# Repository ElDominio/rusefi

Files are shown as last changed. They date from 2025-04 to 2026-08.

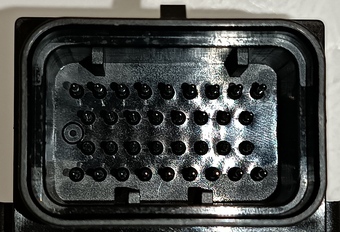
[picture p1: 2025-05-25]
firmware/config/boards/hellen/alphax-4K-GDI/connectors/34pins-4k-A.jpg

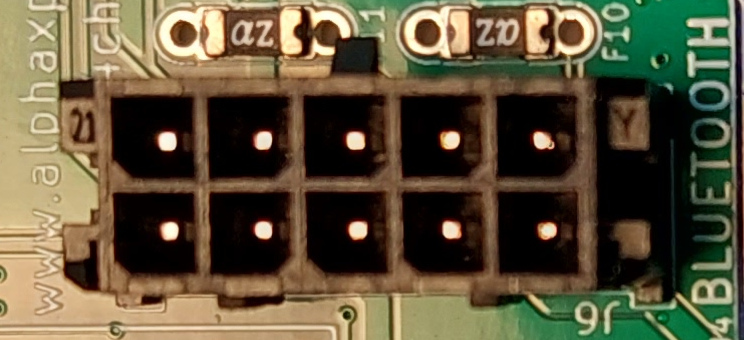
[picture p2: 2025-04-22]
firmware/config/boards/hellen/alphax-silver/connectors/alphax-silver-aux.jpg

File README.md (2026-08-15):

<div align="center">

rusEFI

<b>GPL open-source ECU</b>



</div>

# rusEFI



[shop.rusEFI.com](https://www.shop.rusefi.com/)

# Download

Current binaries are always available on our [build server](http://rusefi.com/build_server/)

# Release Notes

See [the changelog](firmware/CHANGELOG.md)

# What do we have here?
 * [Firmware](/firmware) Source code for open source engine control unit for stm32 chips including [implementation overview](https://github.com/rusefi/rusefi/blob/master/firmware/readme.md)
 * [Hardware](/hardware) KiCAD files for our older PCBs
 * [rusEFI console](/java_console) rusEFI own native tuning software
 * [Simulator](/simulator) win32 or posix version of firmware allows to explore without any hardware
 * [Unit Tests](/unit_tests) Unit tests of firmware pieces [coverage report](https://rusefi.com/docs/unit_tests_coverage/)
 * [Misc tools](/java_tools) Misc development utilities
 * [Software Development process](misc/SoftwareDevelopmentProcess.md)

# External Links

 * [Forum](http://rusefi.com/forum)
 * [Documentation](https://wiki.rusefi.com)
 * [Doxygen documentation](http://rusefi.com/docs/html)
 * [General source code Q&A](http://rusefi.com/forum/viewtopic.php?f=5&t=10)
 * [Facebook](https://www.facebook.com/rusEfiECU)
 * [YouTube](https://www.youtube.com/user/rusefi)
 * [Patreon](https://www.patreon.com/rusefi)

# Cloning the repository
`git clone https://github.com/rusefi/rusefi.git`
Important note - we now use submodules:

`git submodule update --init`

# Building the Code

See [gcc_version_check.c](https://github.com/rusefi/rusefi/blob/master/firmware/gcc_version_check.c) for recommended version of GCC.

Check out https://rusefi.com/forum/viewtopic.php?f=5&t=9

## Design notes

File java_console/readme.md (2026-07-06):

# rusEFI console

rusEFI frontend applications is historically known as rusEFI console.

* firmware update
* wizard for one-time initial setup
* on-going monitoring and calibration

Here we have source code for rusEFI console: while [TunerStudio](http://www.tunerstudio.com/index.php/products/tuner-studio) is the primary calibration frontend application we need secondary app for firmware update and some advanced troubleshooting. One day we shall combine but not yet :(

See also http://rusefi.com/build_server/ for pre-compiled full bundle

🔴 not main folder for java code - it's [../java_tools](../java_tools) where primary build.gradle is located 🔴

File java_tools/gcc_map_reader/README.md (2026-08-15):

# Firmware Stack Usage Report

`StackUsageReport` combines GCC's post-LTO callgraph data with stack metadata
linked into the firmware and bootloader ELF files. The report is informational:
it highlights changes for review but does not fail a build because a stack is
too small.

## Files

| Path | Reason |
|---|---|
| `src/main/resources/stack_usage/*.md` | Hand-maintained profile inputs: display names, reviewed measurements, proxy snapshots, and scenarios |
| `firmware/build/firmware_stack_usage_<profile>.md` | Generated by `com.rusefi.tools.stack.StackUsageReport` during the stack-usage workflow |
| `docs/firmware_stack_usage.md` | Generated and committed by `.github/workflows/firmware-stack-usage.yaml` from the three profile reports |

Generated reports carry a header naming their generator. Do not edit generated
reports directly; update the firmware metadata, profile input, or report tool.

## Inputs

uses compiler-checked metadata macros from
`firmware/controllers/core/common_headers.h`:

- `RUSEFI_STACK_ROOT` for a `ThreadController` or `PeriodicController` member.
- `RUSEFI_STACK_ROOT_EXPLICIT` for a root with an explicit function and budget.
- `RUSEFI_STACK_PROCESS_ROOT` for the linker-sized main process stack.
- `RUSEFI_STACK_FOREIGN_ROOT` only for inaccessible upstream static functions.

The STM32 linker keeps this metadata in non-allocated ELF sections, so it adds
nothing to the flashed image. The Java tool reads:

- The full ELF symbol table for typed roots, including local symbols.
- Foreign-root string sections for inaccessible upstream functions.
- Linker map process and exception stack sizes.
- GCC `.ci` post-LTO callgraphs produced with `-fcallgraph-info=su`.
- The matching hand-maintained profile table under
  `src/main/resources/stack_usage/`.

Profile membership is exact. Adding or removing a linked root without updating
the corresponding profile table makes report generation fail with the missing
and extra entries.

## Add A Thread

1. Mark the thread entry in the source that owns its working area:

```cpp
class ExampleThread final : public ThreadController<512> {
    // ...
};

RUSEFI_STACK_ROOT(ExampleThread, ThreadTask);
```

For a `PeriodicController`, use `PeriodicTask`. For a function passed directly
to `chThdCreateStatic`, use the working-area size explicitly:

```cpp
static THD_WORKING_AREA(exampleThreadStack, 512);

static THD_FUNCTION(exampleThread, arg) {
    // ...
}

RUSEFI_STACK_ROOT_EXPLICIT(exampleThread, 512);
```

Place the macro after the entry function is declared. Use
`RUSEFI_STACK_FOREIGN_ROOT` only when the entry is an inaccessible static
function in upstream code. The macros compile to no code outside production
stack-report builds and their ELF metadata is not flashed.

2. Build and run the report for every affected reference-board profile. The
report fails and prints the exact `missing` or `extra` entry when a linked root
is not in its profile.

3. Add the exact demangled entry name to the matching
`src/main/resources/stack_usage/<profile>.md` table. Start with `-` for
Retained, Proxy, and Scenario if the thread has not been measured:

```text
| firmware | ExampleThread::ThreadTask | example worker | - | - | - |
```

Do not add inactive roots to a profile. The profile describes the final ELF
for that board, not all source files.

## Fix A Stack Overflow

1. Reproduce the highest realistic workload on hardware and record the maximum
stack used by the thread. `Remaining stack` console diagnostics and the stack
guard/check are useful runtime evidence; include ChibiOS overhead in the
working-area budget.

2. Increase the owning `ThreadController<N>`, `PeriodicController<N>`, or
`THD_WORKING_AREA` size above that measurement with a practical margin. Do not
use the direct-call proxy as the measurement: indirect calls, unknown frames,
recursion, interrupts, and context switches can make it too small.

3. Update the profile row's Retained bytes, Proxy snapshot, and Scenario. The
scenario must say what was exercised, for example `SD exFAT log creation`.
The next report compares Current proxy to that snapshot and flags growth for
review.

## Run Locally

Build one profile with stack and callgraph data. For example, H743:

```bash
cd firmware
EXTRA_3_PARAMS="-fstack-usage -fcallgraph-info=su" \
  bash bin/compile.sh config/boards/nucleo_h743/meta-info.env \
  elf bootloader --output-sync=recurse
cd ..
```

Build, test, and run the Java report tool:

```bash
./gradlew :gcc_map_reader:test :gcc_map_reader:shadowJar
java -cp java_tools/gcc_map_reader/build/libs/gcc_map_reader-all.jar \
  com.rusefi.tools.stack.StackUsageReport \
  --profile stm32h743_nucleo \
  --firmware-dir firmware/build \
  --bootloader-dir firmware/bootloader/blbuild \
  --output firmware/build/firmware_stack_usage_stm32h743_nucleo.md
```

`arm-none-eabi-readelf` and `arm-none-eabi-c++filt` must be available on
`PATH`; command overrides are available through `--readelf` and `--cxxfilt`.

## Reading The Report

- **Nominal** is the allocated stack budget from C++ or the linker.
- **Reviewed** is a manually traced realistic scenario, not a root-wide maximum.
- **Proxy snapshot** is the post-LTO direct-call estimate when that scenario was
  reviewed.
- **Current proxy** is the estimate from the current build.
- `REVIEW PROXY +N` means the estimate grew and the scenario should be reviewed.
- `NOT REVIEWED` means no retained scenario exists for that root.

Indirect calls, unknown frames, recursion, interrupts, and context switching can
make the proxy incomplete. The report lists these limitations rather than
pretending the proxy is a proven maximum.

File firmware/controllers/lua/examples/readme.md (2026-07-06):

# rusEFI Lua examples

General reference: https://wiki.rusefi.com/Lua-Scripting

This folder is a grab-bag of community Lua snippets that talk to the rusEFI Lua API
(CAN RX/TX, sensors, outputs, PWM, timers, PID, TunerStudio buttons, etc.). When
asked to write a new Lua script, **scan this folder first** for an analogous
example before starting from scratch. Files use `.lua` or `.txt` — both are plain
Lua; the `.txt` extension is historical.

For iterating on a live or simulated ECU from an LLM, see
`java_console/mcp_ecu/README.md` (the `:mcp_ecu` MCP server: `set_lua`,
`lua_reset`, `wait_for_message`, …).

---

## Gotchas (read before writing a script)

- **Lua-fed sensors time out — refresh them every `onTick`, not on a slow
  gated cadence.** A `Sensor.new(...)` value goes invalid `setTimeout(ms)`
  after the last `:set()` (see `StoredValueSensor::get()` in
  `controllers/sensors/core/stored_value_sensor.h`). If you only call `:set()`
  from a block gated to, say, every 2s while the timeout is 3s, you have ~1s
  of slack — any tick jitter pushes the gap past the timeout and the consumer
  briefly reads 0/invalid, then your next update restores it (gauges that
  "drop to 0 and jump back"). Push `:set()` unconditionally each tick and gate
  only the *value computation* (e.g. a sweep counter). Or, at minimum, set the
  timeout well above the worst-case refresh interval.
- **Failed `txCan` stalls the Lua thread.** On a bench with no second node to
  ACK (or a mis-wired/unterminated bus), transmits fail and `txCan` blocks
  until timeout; the `canWriteNotOk` output channel climbs. Many `txCan` calls
  per tick at a high `setTickRate(...)` can then delay `onTick` by seconds —
  which is exactly what trips the sensor-timeout gotcha above. Symptom is
  environmental (gone on a live, terminated bus) but design scripts to tolerate
  it.

Related (full engine configs, not just snippets):
- VAG CAN producer — `firmware/config/engines/vw_b6.lua`
- GM CAN producer — `firmware/config/engines/gm_ls_4.cpp`

---

## Categories

### Getting started / building blocks
- `pid.lua` — minimal `Pid.new(...)` usage; a good "hello PID" template.
- `ts-button-example.lua` — wire a TunerStudio button (`fireEvent`) to a Lua
  handler. Reference for any UI-triggered action.
- `etb-test-script.lua` — one-liner to drive the electronic throttle manually.
- `dac.txt` — write an analog voltage via the on-board DAC.
- `analog-gear-input.txt` — decode a gear position from a single analog input
  (voltage windows → gear number).
- `linear-oil-sensor.lua` — convert a linear oil-pressure sensor voltage to a
  rusEFI sensor reading.

### Utilities / helpers (good to copy-paste into other scripts)
- `utils-print-array.lua` — pretty-print a Lua array (debug helper).
- `utils-can-dbc.lua` — bit-field pack/unpack helpers in the spirit of DBC
  signal definitions; the cleanest reference for building CAN payloads.
- `utils-dash-sweep.lua` / `dash-sweep.lua` — sweep gauge needles on power-up
  (a "self-test" animation for digital dashes).

### Launch control / antilag / quickshift
- `launch_control.lua` — full-featured launch control with CAN status frames,
  ignition cut and configurable thresholds. The most complete example in this
  folder.
- `custom-launch-control.txt` — simpler launch-control sketch.
- `CruiseCheck.lua` — cruise-control safety / engagement checks.
- `ALS (simple antilag strategy).txt` and the companion
  `ALS (simple antilag strategy)LUA_MAPS.txt` — minimal antilag with Lua-side
  fuel/ignition maps.
- `quickshift.txt` — flat-shift / quickshifter ignition-cut on a digital input.

### Drive-by-wire / actuators
- `DBW-controller.txt` — closed-loop electronic throttle controller written in
  Lua (useful when the built-in ETB is not enough).
- `can-client-dc-pid.txt` — PID-controlled DC motor over CAN.
- `Volvo-electric-power-steering-pump.txt` — drive a Volvo EPS pump via PWM /
  CAN.

### CAN: man-in-the-middle and gateways
"Cut a CAN bus and put rusEFI in the middle" patterns — rusEFI receives frames
on one bus and re-transmits modified copies, typically to spoof RPM / TPS / etc.
to a downstream module.
- `man-in-the-middle.txt` — generic MITM template, start here.
- `man-in-the-middle-nissan-tcu.txt`, `nissan-xterra-tcu.txt`,
  `nissan-tcu.lua` — feed a Nissan TCU with fabricated ECU frames so the
  factory transmission keeps working behind rusEFI.
- `TCU-4-speed.txt` — a fuller standalone 4-speed TCU written in Lua.
- `vag-headlight.txt` — VAG headlight / lighting CAN MITM.

### CAN: VAG / VW transport protocol (TP 2.0)
- `vw-tp.txt` — VW/Audi TP 2.0 transport layer in Lua (channel setup,
  segmented messages).
- `vw-tp-tcu.txt` — TP 2.0 talking to a VAG TCU.
- `vw-sensors-from-ptbus-pq46.txt` — read sensor values off a PQ46 powertrain
  bus.

### CAN: dashboards / instrument clusters
Drive a factory cluster from rusEFI by emitting the frames it expects.
- `suzuki_can_dash.lua` — Suzuki cluster.
- `dash_output_abit_m11.txt`, `dash_output_abit_m11.16txt` — Abit M11
  aftermarket dash.
- `uaDASH-dev.lua` — uaDASH (rusEFI / community digital dash) output frames.
- `bmw-idrive.txt` — drive BMW iDrive / cluster signals.

### CAN: body / comfort modules (BCM)
- `honda-bcm.txt` — Honda body control module signalling.
- `nissan-350z-bcm.txt`, `350z-ac.txt` — Nissan 350Z BCM + A/C request
  handling.
- `ford-focus-ii-pps.txt` — Ford Focus II accelerator-pedal (PPS) decode from
  CAN.
- `polaris_slingshot.txt` — Polaris Slingshot bus integration.

### CAN: peripherals / smart sensors / dynos
- `motec-ltc-input.lua` — read a MoTeC LTC wideband over CAN.
- `Dyno-Dynamics.lua`, `ECU-to-DynoLog.txt` — exchange data with Dyno
  Dynamics / DynoLog dynamometers.
- `canopen-keypad.lua` — read a CANopen keypad (button matrix over CAN).
- `cantcu.lua` — talk to a generic CAN-controlled TCU.
- `can-adc-server.txt` — expose ADC readings as a CAN server (let other nodes
  ask rusEFI for analog values).
- `gdi4-communication.lua` — communicate with the GDI4 (4-channel direct-
  injection driver) over CAN; the most detailed GDI example here.
- `gdi8-pressure-input.lua` — read fuel-rail pressure reported by a GDI8
  driver.
- `msio-device.lua` — talk to an MSIO expansion board.

### Diagnostics / programming protocols
- `uds-prog.txt` — UDS (ISO 14229) programming session sketch.
- `xcp-prototyping.txt` — XCP measurement/calibration protocol prototype.
- `ms11bit.txt`, `ms29bit.txt` — raw 11-bit vs 29-bit CAN ID handling demos.

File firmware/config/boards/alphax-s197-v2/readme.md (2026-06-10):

# alphax-s197-v2

Custom board for the Ford S197 Mustang, heavily based on the `uaefi F4` design.

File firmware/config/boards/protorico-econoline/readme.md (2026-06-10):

# Protorico-Econoline rusEFI board definition

This is a board definition for the custom Protorico-Econoline board.

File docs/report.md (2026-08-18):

# Work Report

## 2026-07-14 - Investigation: "Malformed Packet: packet length" in USB.pcapng

What was done:
- Analyzed USB.pcapng (USBPcap capture of the rusEFI ECU USB link, device address 7)
  using tshark to explain the "malformed packet" warnings.

Findings:
- Protocol hierarchy: 84926 frames, mostly USB mass storage (usbms/scsi) plus 2 CDC
  (usbcom) control frames. 23 SCSI frames + 1 URB frame flagged _ws.malformed.
- The 23 usbms malformed frames are ALL the same case: the device reply to
  SCSI Mode Sense(6) (opcode 0x1a). Wireshark message: "SCSI: length of contained
  item exceeds length of containing item".
- Root cause is a Wireshark dissector strictness issue, NOT bad wire data. The 16-byte
  reply is self-consistent:
      0f 00 00 00  08 0a 00 00 00 00 00 00 00 00 00 00
  Mode Data Length=15 (=total-1), Caching mode page (0x08) with PageLength=0x0a=10.
  SBC-2 mandates the Caching page be 0x12=18 long (20-byte page); rusEFI emits a valid
  but non-standard SHORT caching page. Wireshark decodes the full 20-byte layout, reads
  past the 16-byte buffer, and raises the exception. Windows accepts it -> device works.
- Response is hardcoded in ChibiOS-Contrib USB-MSD SCSI target (os/hal/src/hal_usb_msd.c,
  submodule not checked out locally), driven by
  firmware/hw_layer/mass_storage/mass_storage_device.cpp.
- Frames 27759-27772 "USBPcap did not recognize URB Function code" are a USBPcap capture-
  driver limitation, unrelated to rusEFI traffic.

Decisions:
- Classified as cosmetic; no code change made. Not a functional defect.

Validation:
- tshark -z io,phs, per-frame -V dissection, and raw -x hex confirmed the byte layout
  and that all 23 malformed frames share the Mode Sense(6) cause.

Open follow-ups:
- Optional cleanup if the warning ever matters: set the Caching mode page length to 0x12
  and pad the page to the full 20 bytes, or drop the caching page from the Mode Sense
  reply. Lives upstream in ChibiOS-Contrib hal_usb_msd.c.

## 2026-07-14 - SD ECU<->PC switch soak sandbox + USB CDC link-drop investigation

What was done:
- Created a headless soak sandbox SdEcuPcCycleSandbox in the :ui test subproject
  (java_console/ui/src/test/java/com/rusefi/SdEcuPcCycleSandbox.java), modeled on the
  purple-gateway SdPcToEcuSwitchSandbox. It cycles the SD card ECU/logging <-> PC/MSD 10
  times, 20s dwell per mode, confirming each switch via the sd_present / sd_logging_internal
  / sd_msd output channels, and reports a pass/fail tally. Added Gradle task :ui:runSdCycle.
- Initialized two uninitialized git submodules required by the Java build:
  java_console/peak-can-basic (missing peak.can.basic.* -> :ecu_io compile fail) and
  java_console/luaformatter (missing neoe.formatter.lua -> :ui compile fail).

Result of the run (COM149, purple-gateway fw, USB-powered only / no +12V):
- Cycle 1 fully succeeded BOTH directions. PC/MSD->ECU no longer hits FR_DISK_ERR: firmware
  logged "SD: switched from PC/MSD to ECU/logging" and opened log file re_10.mlg; status bits
  confirmed sd_logging_internal=1.
- ~1.5s after the ECU switch the host CDC serial link dropped:
  "output channels: executeCommand failed: java.io.IOException: write failed: wrote 0 but
  expected 11", COM149 closed. Never recovered, so cycle 2's first command got no response and
  the soak aborted at 1/20. Sandbox behaved correctly - it detected and reported the drop.

Root cause (investigated, code-evidenced):
- CDC console and USB mass storage are interfaces on ONE composite USB device (USBD1). The
  config descriptor is fixed at 3 interfaces - MSD IF0 + CDC-control IF1 + CDC-data IF2, 98
  bytes (usbcfg.cpp DESCRIPTOR_SIZE/NUM_INTERFACES). MSD is always present in the enumerated
  descriptor whenever HAL_USE_USB_MSD is built in.
- The SD mode switch does NOT re-enumerate or reconfigure USB. attachMsdSdCard /
  deattachMsdSdCard (mass_storage_init.cpp) merely hot-swap LUN1's backing block device
  between the real SD card and the null device ND1 on the already-running MSD controller.
- Causal chain: PC/MSD->ECU calls deattachMsdSdCard() which swaps LUN1 (SD card -> ND1) while
  Windows still has that mass-storage volume mounted -> the medium vanishes under the mounted
  volume -> the Windows usbstor stack resets/re-enumerates the whole composite device to
  recover -> firmware gets USB_EVENT_RESET/SUSPEND, whose handler calls sduSuspendHookI(&SDU1)
  (usbcfg.cpp:446), tearing down the CDC channel -> host CDC write returns 0, COM149 drops.
- It is host-side (write wrote 0 = port handle invalidated), not a firmware stall: the switch
  completed cleanly, logging started, and the device kept emitting messages up to the drop.

Remediation directions (not implemented - investigation only):
- Don't swap the MSD LUN to a dead null device under a mounted volume. Instead present a stable
  medium or return SCSI "not ready / medium not present" (unit attention) so Windows performs an
  orderly media-eject rather than treating it as a device fault and resetting the port.
- Or signal proper SCSI medium-removal / unit-attention before switching so the host dismounts
  cleanly.
- Host-side, for a true 10x soak: reconnect LinkManager after each switch (treat the CDC drop
  as expected re-enumeration). The current sandbox intentionally reports it instead.
- The existing USB.pcapng capture can confirm the host-issued bus reset around a mode switch.

Validation:
- ./gradlew :ui:compileTestJava BUILD SUCCESSFUL after submodule init.
- ./gradlew :ui:runSdCycle exercised against real hardware; full log captured.

Open follow-ups:
- Decide remediation approach (firmware SCSI media-eject vs host-side reconnect).
- Consider gating: the soak cannot complete 10 cycles over one connection until the CDC drop is
  addressed.

## 2026-07-14 - SD indicator/output-channel name reuse between SdEcuPcCycleSandbox and .ini

What was done:
- Removed the duplicated magic strings sd_present / sd_logging_internal / sd_msd that existed
  independently in output_channels.txt (bit field names), tunerstudio.template.ini (6 indicator
  expressions) and SdEcuPcCycleSandbox.java (SensorCentral lookups). They now flow from a single
  source of truth via the existing code generation.

Change inventory:
| File | Change |
|---|---|
| firmware/integration/rusefi_config_shared.txt | new OUTPUT_CHANNEL_SD_PRESENT / _SD_LOGGING_INTERNAL / _SD_MSD quoted defines |
| firmware/console/binary/output_channels.txt | the 3 SD bit fields renamed to @#OUTPUT_CHANNEL_SD_...#@ references |
| firmware/tunerstudio/tunerstudio.template.ini | 6 indicator lines reference @#OUTPUT_CHANNEL_SD_...#@ |
| java_tools/.../ReaderStateImpl.java (config_definition_base)| handleBitLine now applies variable substitution to the bit name (comment stays templated, matching plain-field parsing) |
| java_tools/.../ConfigFieldParserTest.java | new testBitNameViaVariableReference |
| java_console/.../SdEcuPcCycleSandbox.java | uses VariableRegistryValues.OUTPUT_CHANNEL_SD_* constants |
| java_tools/version/.../UiVersion.java | CONSOLE_VERSION -> 20260714 |

Key decisions and why:
- Constants live in rusefi_config_shared.txt because it is prepended by BOTH pipelines that need
  them: gen_config_common.sh (template .ini + VariableRegistryValues.java) and the LiveData.yaml
  output_channels entry (LiveDataProcessor parsing output_channels.txt).
- Used the existing @#NAME#@ quote-stripping substitution (same as TS_HELLO_COMMAND usages) so the
  quoted define yields a bare identifier in struct field names and { } indicator expressions while
  generating a proper Java String constant.
- handleBitLine substitution was narrowed to the name part only: applying it to the whole line
  expanded @@...@@ comment templates at parse time, which changed engine_state_generated.h
  (clutchDownState comment). The narrowed version keeps every generated artifact byte-identical.
- Did not resurrect the deleted generated TsOutputs.java (removed in #6711); defines + existing
  VariableRegistryValues generation is the sanctioned mechanism.

Validation:
- ./gradlew :config_definition:test :config_definition_base:test green including the new test.
- gen_live_documentation.sh + gen_config_board.sh f407-discovery: all generated outputs
  (output_channels_generated.h, live_data_fragments.ini, data_logs.ini, board .ini indicator
  lines) byte-identical to committed state; only VariableRegistryValues.java gains the 3 new
  String constants. Board-generated .h/.ini signature/date churn reverted (CI regenerates).
- ./gradlew :ui:compileTestJava BUILD SUCCESSFUL with the sandbox on the generated constants.

Open follow-ups:
- Other magic output-channel names shared between java_console and .ini (e.g. sd_error,
  sd_formating, sd_active_wr/rd) could adopt the same pattern when java code starts using them.

---

## 2026-07-14 - N52 preset: bake in TPS/PPS calibration from reference tune

What: Ported TPS + PPS calibration out of the "super N52" TunerStudio tune (CurrentTune.msq)
into the `bmwN52()` engine preset in `firmware/config/engines/bmw.cpp`, so a fresh N52 selection
ships with the real throttle-body/pedal calibration instead of raw defaults.

| Field(s) | Source (msq, volts) | Stored as |
|---|---|---|
| tpsMin / tpsMax | 4.545 / 0.58 | 10-bit ADC via convertVoltageTo10bitADC |
| tps1SecondaryMin / tps1SecondaryMax | 0.75 / 4.72 | 10-bit ADC via convertVoltageTo10bitADC |
| throttlePedalUpVoltage / throttlePedalWOTVoltage | 0.625 / 2.230 | float volts (verbatim) |
| throttlePedalSecondaryUpVoltage / ...WOTVoltage | 0.947 / 4.197 | float volts (verbatim) |

Key decisions:
- Used shared helpers setTPS1Calibration()/setPPSCalibration() (defaults.h), matching subaru.cpp.
- TPS stored as 10-bit ADC counts (not volts): wrapped msq volts in convertVoltageTo10bitADC
  (= volts*200). PPS stored as float volts, copied through directly. This units split is the main
  porting hazard and is now documented.
- Skipped tps2* fields: msq had them at defaults (0/5, 5/0); N52 runs a single dual-sensor throttle.
- Added #include "defaults.h"; convertVoltageTo10bitADC comes transitively via pch.h.

Docs: new docs/AI/engine_presets.md documents the canned-tune/preset process end to end
(enum -> engine_type_impl.cpp dispatch -> config/engines setup fn), the TPS-vs-PPS units gotcha,
and a step-by-step msq->preset porting recipe.

Validation: static review only - mirrors the established subaru.cpp calibration pattern; all
referenced helpers are declared in the included headers. No generated files touched (presets are
plain code, no gen_config step).

Open follow-ups:
- Confirm on hardware that a defaults-reset N52 reads plausible TPS
---

## 2026-07-14 - N52 preset: bake in TPS/PPS calibration from reference tune

What: Ported TPS + PPS calibration out of the "super N52" TunerStudio tune (CurrentTune.msq)
into the bmwN52() engine preset in firmware/config/engines/bmw.cpp, so a fresh N52 selection
ships with the real throttle-body/pedal calibration instead of raw defaults.

| Field(s) | Source (msq, volts) | Stored as |
|---|---|---|
| tpsMin / tpsMax | 4.545 / 0.58 | 10-bit ADC via convertVoltageTo10bitADC |
| tps1SecondaryMin / tps1SecondaryMax | 0.75 / 4.72 | 10-bit ADC via convertVoltageTo10bitADC |
| throttlePedalUpVoltage / throttlePedalWOTVoltage | 0.625 / 2.230 | float volts (verbatim) |
| throttlePedalSecondaryUpVoltage / ...WOTVoltage | 0.947 / 4.197 | float volts (verbatim) |

Key decisions:
- Used shared helpers setTPS1Calibration()/setPPSCalibration() (defaults.h), matching subaru.cpp.
- TPS stored as 10-bit ADC counts (not volts): wrapped msq volts in convertVoltageTo10bitADC
  (-> volts*200). PPS stored as float volts, copied through directly. This units split is the
  main porting hazard and is now documented.
- Skipped tps2* fields: msq had them at defaults (0/5, 5/0); N52 runs a single dual-sensor throttle.
- Added #include "defaults.h"; convertVoltageTo10bitADC comes transitively via pch.h.

Docs: new docs/AI/engine_presets.md documents the canned-tune/preset process end to end
(enum -> engine_type_impl.cpp dispatch -> config/engines setup fn), the TPS-vs-PPS units gotcha,
and a step-by-step msq->preset porting recipe.

Validation: static review only - mirrors the established subaru.cpp calibration pattern; all
referenced helpers are declared in the included headers. No generated files touched (presets are
plain code, no gen_config step).

Open follow-ups:
- Confirm on hardware that a defaults-reset N52 reads plausible TPS%/pedal% before user tuning.
---

## 2026-07-15 - SD card logging: overview doc + code comments (f_expand logic)

What: Documented the SD card logging subsystem and annotated its three core source files.

| File | Change |
|---|---|
| docs/AI/sd_card_logging.md (new) | End-to-end overview: SD thread mode state machine (IDLE/ECU/PC/UNMOUNT/FORMAT, all transitions via IDLE), .mlg vs .teeth loggers, FileBufferedWriter path, f_expand pre-allocation, file naming, status channels, console commands |
| firmware/hw_layer/mmc_card.cpp | Expanded LOGGER_MAX_FILE_SIZE, f_expand and f_truncate comments; doc pointer in file header |
| firmware/console/binary_mlg_log/binary_mlg_logging.cpp | File-header overview (MLG v2 layout, who owns file lifecycle); comments on writeFileHeader/writeSdBlock/writeSdLogLine/resetFileLogging |
| firmware/console/binary/tooth_logger.cpp | Comment on freeBuffers/filledBuffers multi-buffering (BigBuffer, interrupt producers -> TS/SD consumers); ToothLoggerWriter() contract incl. 3s idle timeout -> new file |
| CLAUDE.md | Added sd_card_logging.md to Deep Dive AI Guidance list |

Key facts captured (the f_expand logic in particular):
- sdLoggerCreateFile() pre-allocates each log file to 32Mb with f_expand(fd, size, opt=1)
  (allocate-now, contiguous; FF_USE_EXPAND=1 in firmware/ext/FatFS/ffconf.h). All FAT
  updates happen up-front, so writes inside the pre-allocated area never touch FAT
  structures -> sudden power loss loses buffered data but not the filesystem.
- f_expand failure (fragmented card) is deliberately non-fatal: FatFS falls back to
  cluster-by-cluster growth, logging works without the corruption protection.
- sdLoggerCloseFile() f_truncate()s back to actual size; a power-lossed file stays 32Mb
  with trailing garbage.
- Both loggers share sdLoggerCreateFile() (so .teeth files are pre-allocated too) but
  only sdLoggerMlg() enforces the 32Mb rollover cap.

Validation: comment/doc-only changes, no code touched; facts verified against source
(mmc_card.cpp, file_writer.h, ffconf.h FF_USE_EXPAND=1, tooth_logger.cpp, sd_log_trigger.h).

Open follow-ups: none.

## 2026-07-15 - Lua scripting API: categorized hook inventory doc

What: Reviewed every custom Lua method registered around lua_hooks.cpp and documented
them in a new docs/AI/lua_scripting.md, grouped into 11 categories.

| File | Change |
|---|---|
| docs/AI/lua_scripting.md (new) | Full inventory of Lua hooks by category: input reads, virtual sensors, virtual switches, closed-loop trims, cut/disable controls, PWM/DAC outputs, CAN, config/calibration access, state queries, luaaa helper classes, framework/test hooks; plus registration-site map, indexing conventions, build-flag gating, and an "adding a new hook" recipe |
| CLAUDE.md | Added lua_scripting.md to the Deep Dive AI Guidance list |

Key decisions / findings:
- Registration is spread over four files: lua_hooks.cpp (bulk + luaaa classes),
  lua_hooks_util.cpp (print/interpolate/find*/mcu_standby), lua.cpp (setTickRate,
  onTick dispatch), lua_can_rx.cpp (onCanRx dispatch, global_can_data workaround).
  lua_hooks_ext.cpp is an empty extension point; boardConfigureLuaHooks() is a weak
  board hook with no in-tree overrides.
- Documented the mixed indexing convention explicitly: 1-based (HUMAN_OFFSET) for
  TS-facing entities (CAN bus, curves, tables, TS buttons, gauges), 0-based for
  sensor indices, PWM channels, aux digital inputs, vin().
- Documented flash-saving exclusions (#if !defined(STM32F4) group) and the
  DISABLE_LUA_* / WITH_LUA_* opt-out macros.
- setTickRate code clamps 1..2000 Hz while its comment says 1..200 - doc records
  the code behavior (comment discrepancy left in source, not a functional issue).

Validation: doc-only change; every listed hook, guard macro and constant
(LUA_PWM_COUNT=8, LUA_GAUGE_COUNT=8, LUA_DIGITAL_INPUT_COUNT=8, LUA_BUTTON_COUNT=10,
CMD_BURNCONFIG="burnconfig") verified against source via grep/read of the four
registration files, lua_pid.h and rusefi_config.txt.

Open follow-ups:
- lua.cpp setTickRate comment ("Limit to 1..200 hz") disagrees with clampF(1, x, 2000).
- lua_hooks.cpp has a commented-out hasCriticalReportFile hook referencing issue #7291.

## 2026-07-17 - loss-of-cdc.pcapng analysis: one-shot composite reset from pre-capture MSD wedge

What: Analyzed loss-of-cdc.pcapng (repo root, USBPcap, 24.6 s, captured 2026-07-17
12:25 - i.e. the day AFTER the #9860 fix series landed) against the recent
mass_storage changes. Goal: confirm/refute whether the CDC drop mechanism from
issue #9860 is still present.

Devices in capture: address 21 = the ECU (VID 0483:5740, composite MSD+CDC),
address 22 = PEAK PCAN-USB adapter (19.9k of the 22k packets - unrelated noise).

Timeline (t = seconds from capture start):
- t=0..10.8: ZERO MSD traffic from the ECU. A healthy medium-less device gets
  ~1 Hz Test Unit Ready polls (visible later in this same capture), so at capture
  start usbstor already had one command in flight that never completed - the MSD
  side was already wedged/stuck before the capture began.
- t=7.79: host opens the COM port (GET/SET LINE CODING burst); CDC request/reply
  traffic (TS-style 7/11-byte commands, 1024-byte replies) runs cleanly for 3 s.
- t=10.847: usbstor ~20 s give-up timer fires -> all-endpoint cancel storm on the
  ECU: 10 URBs with USBD_STATUS_CANCELED (0xc0010000) - MSD bulk-IN 0x81 (the
  stuck data/CSW read, pending since before capture start), CDC data 0x82/0x02,
  CDC interrupt 0x83, plus control. This is the loss-of-CDC moment.
- t=10.883: host immediately retries line coding - those control URBs are
  canceled too (device still resetting).
- t=11.03..11.05: MSD recovers: Test Unit Ready on LUN0 and LUN1 -> Check
  Condition -> Request Sense (Good) -> Mode Sense(6) (the known-cosmetic
  "malformed" short caching page). Both LUNs report medium-not-present.
- t=11.28: CDC port re-opens at USB level (line coding OK) but NO data traffic
  follows - the app-level session was dead, host serial layer sat in its ~10 s
  timeout.
- t=12..24.5: clean steady state: 1 Hz TUR polls per LUN, no stalls, no babble,
  no further cancels or resets.
- t=20.79: app fully reconnects (line coding + control line state), TS-style
  traffic resumes. Total user-visible CDC outage: ~10 s (10.85 -> 20.79).

Reading vs the 2026-07-16 fix series (298162eb075..68e7d77c042, all in
firmware/hw_layer/mass_storage/):
- 298162eb0/8a515546c (MSD diag #9838): sdinfo diagnostics incl. per-opcode
  in-flight timer.
- e1feee380 (isCommandAbandoned #9861): 10 s data-phase timeouts on all SCSI
  transfers + CSW via msdUsb*Timeout helpers -> wedged thread self-recovers,
  re-arms bulk-OUT.
- 12b613c59 (#9864): LUN detach now synchronizes with in-flight command
  (m_lunMutex held around scsiExecCmd+CSW) -> kills the SPI double-waiter
  deadlock from the SD mode switch.
- 04331c28f (#9866) + 68e7d77c0 (uaefi): medium-less data-IN commands answered
  with ZLP instead of STALL -> no EP0 clear-halt round-trip near CDC traffic.
The capture is consistent with the fixes WORKING as designed for the recurring
part: exactly ONE reset (the tail of a wedge that began ~9 s before capture,
matching usbstor's ~20 s timer), then 13.5 s of clean behavior with no repeat
reset - the old signature was a reset every ~20 s.

Remaining gap (why one reset still happens): the firmware 10 s data-phase
timeout releases the MSD *thread*, but leaves the *host's* pending IN URB
hanging - firmware just returns to CBW wait and never completes/STALLs the
IN transfer the host is still waiting on. usbstor therefore still escalates to
a full composite reset once, taking CDC down with it. A full fix would complete
the host's data phase on timeout (e.g. STALL the IN endpoint so the host gets
an immediate error -> clear-halt -> CSW path) instead of leaving the URB
pending. Caveat: cannot verify from the capture which firmware build was
flashed or which opcode wedged (the CBW predates the capture); console sdinfo
counters (data-phase timeouts / no-data ZLPs) on the connected unit would
distinguish "fixed firmware, host-side URB gap" from "stale firmware".

Validation: tshark 3.6.2 field-level analysis (usb.usbd_status, endpoints,
SCSI dissection); code cross-checked at HEAD (mass_storage_device.cpp timeout/
ZLP/mutex mechanisms present).

Open follow-ups:
- On data-phase timeout, also complete the host-visible transfer (STALL data-IN
  or arm+flush) so usbstor never needs its 20 s reset - would remove the single
  remaining CDC drop.
- Confirm via sdinfo on hardware whether the flashed build has the 07-16 fixes
  and whether data-phase timeout counters tick.

## 2026-07-17 - MSD data-phase timeout: close the command host-side (stall + phase-error CSW)

What: Implemented the follow-up from the loss-of-cdc.pcapng analysis (previous
entry). Before this change, a data-phase timeout only freed the MSD *thread*
(e1feee380 #9861); the *host's* pending URB was left hanging and the CSW was
skipped, so usbstor still escalated to one full composite-device reset per
wedge - taking the CDC console down for ~10 s each time.

| File | Change |
|---|---|
| firmware/hw_layer/mass_storage/mass_storage_device.cpp | ThreadTask: split the abandoned-command check. BOT reset still skips the CSW (host is not expecting one). Data-phase timeout now STALLs the data endpoint in the CBW's direction (usbStallTransmitI/usbStallReceiveI) and then sends a CSW with CSW_STATUS_PHASE_ERROR and honest residue. sendCsw() now returns whether the host read the CSW; sdinfo prints "N data-phase timeouts (M closed by CSW)" |
| firmware/hw_layer/mass_storage/mass_storage_device.h | sendCsw() -> bool; new m_timeoutCswDeliveredCount counter |

Key decisions and why:
- STALL is the BOT-sanctioned "cannot complete this data phase" signal: a host
  still waiting on its data URB completes it with an error immediately (well
  before usbstor's ~20 s give-up), does a clear-halt on this one endpoint, and
  collects the CSW - recovery stays class-level on the MSD interface, the CDC
  endpoints never notice. A host that already canceled its URBs ignores the
  stall and resets anyway - no worse than before.
- Arming the CSW while the endpoint is still stalled is the exact sequence the
  pre-ZLP medium-less path used (04331c28f), already validated on Windows
  hardware (STALL -> clear-halt -> CSW observed on the wire).
- CSW_STATUS_PHASE_ERROR rather than FAILED: after a broken data phase the
  transport has genuinely lost sync; phase error makes the host run Bulk-Only
  Reset Recovery (class request + clear both halts), fully resynchronizing
  data toggles without any port-level reset. The existing onBulkOnlyResetIsr
  path handles that request.
- Safe to stall: all three msdUsb*Timeout helpers clear the endpoint's
  active flag on timeout, so usbStall*I (which refuses while a transfer is
  active) always takes effect by the time ThreadTask runs the recovery.
- The no-data-ZLP timeout path intentionally keeps its plain 'continue': a
  host that will not even take a zero-length packet is gone from the data
  phase entirely; its next action is a new CBW (accepted normally) or a reset.

Validation: uaefi firmware build (see below). No unit-test coverage exists for
this path (EFI_PROD_CODE + HAL_USE_USB_MSD only). Hardware validation plan:
reproduce the wedge (host abandons a command mid-data-phase), then check
1. sdinfo shows "closed by CSW" ticking together with data-phase timeouts,
2. a capture shows STALL -> clear-halt -> CSW(phase error) -> BOT reset
   instead of the all-endpoint cancel storm,
3. the CDC console stays connected across the event.

Open follow-ups:
- Wedges *below* the USB layer (e.g. blkRead stuck on a dying SD card) are
  still uncovered: no timeout wraps lib_scsi's block-device calls, so such a
  wedge never reaches the new recovery path (lib_scsi is in ChibiOS-Contrib).
- The loss-of-cdc.pcapng pre-capture wedge could not be attributed (stale
  firmware vs blkRead wedge); confirm the flashed build via sdinfo counters.

## 2026-07-23 - alphax-4chan_f7: Lua script (TS page 5) not persisting across reboot

Reported symptom: sending a Lua script to the ECU via console on
alphax-4chan_f7 runs immediately but does not survive a power cycle, while
the same workflow is fine on alphax-s550-pnp (also an F7/mm176 board).

Root cause: page5_s (which holds page5_s::luaScript,
firmware/integration/config_page_5.txt:7) is an "extra page" - on F7 boards
it only gets an internal-flash backend if board.mk both (a) includes
hw_layer/ports/stm32/2mb_flash.mk, which relocates config storage above the
first 1.5MB of flash into 128KB sectors (the only F7 layout where extra-page
piggybacking is valid, per the STM32F7XX guard in
storage_flash.cpp::getExtraPageFlashAddr()), and (b) sets
-DEFI_STORAGE_SD=FALSE so a stale SD custom_page.bin doesn't clobber the
flash copy of page 5 on read (EFI_STORAGE_SD defaults TRUE). Without both,
the page has no backend and silently resets to defaults every boot - live
uploads work because they only touch RAM.

This is the same defect class previously found and fixed on alphax-gold (see
FLASH_DATA_VERSION / page-5 flash persistence history). alphax-4chan's F7
branch in firmware/config/boards/hellen/alphax-4chan/board.mk was never
given the fix; alphax-gold, alphax-s550-pnp, alphax-4K-GDI, uaefi, and
super-uaefi all already include 2mb_flash.mk.

Fix: added the same two lines (2mb_flash.mk include + EFI_STORAGE_SD=FALSE)
inside the ARCH_STM32F7 branch of alphax-4chan/board.mk, mirroring
alphax-s550-pnp's board.mk verbatim (comments included).

Validation: `./compile_alphax-4chan_f7.sh -j12` builds clean. Flash layout
now shows the same relocated split as alphax-gold (flash0 1504KB / flash1
1504KB, 44.56%/33.34% used) instead of a single un-split flash region.
Hardware validation (flash Lua script, power-cycle, confirm it survives) not
yet performed - firmware image only.

Open follow-ups:
- Flash the built image to hardware and confirm the Lua script (and other
  page 5 fields, e.g. custom lookup tables) survive a real power cycle.
- Consider a compile-time guard (like the existing page5_container_s static
  assert) that fails the build for any F7 board defining page-5-backed
  features without EFI_STORAGE_INT_FLASH properly wired, so this class of
  bug can't recur silently on a new board.

## 2026-07-30 - TCU Input Speed Sensor: "shared with main VSS" toggle

What was done:
- Added a dropdown to the TCU Input Speed Sensor panel letting the user mark
  that sensor as physically the same wire as the main Chassis VSS, instead of
  a second independent input.

Key decisions and why:
- Config field: repurposed the unused `devBit0` placeholder
  (firmware/integration/rusefi_config.txt) as
  `tcuInputSpeedSensorSharedWithVss` rather than growing the struct, avoiding
  a FLASH_DATA_VERSION bump (see FLASH_DATA_VERSION bump history). Removed
  its stale `field = devBit0, devBit0` line from the "Experimental 3" parking
  lot dialog in tunerstudio.template.ini.
- Investigated whether "shared" could simply mean pointing
  tcuInputSpeedSensorPin at the same physical pin as
  vehicleSpeedSensorInputPin. Ruled out: firmware/hw_layer/digital_input/digital_input_exti.cpp
  keeps one ExtiChannel per physical pin index (`channels[16]`); a second
  FrequencySensor::initIfValid() on an already-claimed pin hard-fails via
  firmwareError(CUSTOM_ERR_PIN_ALREADY_USED_2) and returns -1 - two
  independent EXTI registrations on one pin are not possible on STM32.
- Implemented instead as edge fan-out inside FrequencySensor
  (firmware/controllers/sensors/frequency_sensor.{h,cpp}): a FrequencySensor
  can now be initialized via initShared() to skip owning a pin/EXTI callback
  entirely and instead receive the raw edge frequency from another
  FrequencySensor's onEdge() through a new onSharedEdge() path
  (setSharedListener()/m_sharedListener). Each side still applies its own
  biquad filter and its own SensorConverter (VehicleSpeedConverter vs.
  InputShaftSpeedConverter) independently on top of the same raw frequency,
  so filter tuning (vssFilterReciprocal vs issFilterReciprocal) and units
  (km/h via gear ratio vs. RPM via tooth count) stay fully independent even
  though the physical signal is shared.
- firmware/init/sensor/init_input_shaft_speed_sensor.cpp now branches on
  engineConfiguration->tcuInputSpeedSensorSharedWithVss: shared mode calls
  inputShaftSpeedSensor.initShared(...) and attaches it as
  vehicleSpeedSensor's shared listener (extern-declared from
  init_vehicle_speed_sensor.cpp); non-shared mode is unchanged
  (initIfValid on tcuInputSpeedSensorPin). Both init and deinit paths clear
  the listener to avoid a stale pointer across a mode switch or engine
  reconfiguration.
- TS UI (tunerstudio.template.ini, inputSpeedSensorPanel): added the
  "Shared with main VSS" field; "Input Pin" is now hidden when shared is
  enabled; "Filter parameter" stays visible either way since it still
  applies to the shared reading. tcuInputSpeedSensorTeeth is left
  independently user-editable in both modes (not auto-derived from
  vssToothCount) - kept the change minimal since only the pin-sharing
  dropdown was requested.

Validation:
- `./gradlew -p java_tools :config_definition:shadowJar` - rebuilt a stale
  config_definition-all.jar first (unrelated pre-existing issue on this
  branch, see Stale config_definition jar history: a page5_s static_assert
  was failing at 8000 vs 10000 bytes purely from the stale jar, nothing to
  do with this change).
- `unit_tests/test.sh` - full suite compiles and links; 1297/1298 pass. The
  one failure (ClosedLoopFuel.StateBasedRegionMapping, a
  ShortTermFuelTrim::regionForSmState(S::Coasting) mismatch) is unrelated to
  this change - none of the edited files touch STFT/region-mapping code -
  and predates this session's work.
- Confirmed generated INI (firmware/tunerstudio/generated/rusefi_f407-discovery.ini)
  renders the field correctly: `tcuInputSpeedSensorSharedWithVss = bits, U32,
  1680, [18:18], "Disabled", "Enabled"` (defaults to Disabled/not-shared),
  and the Input Pin field's visibility condition
  `{ !tcuInputSpeedSensorSharedWithVss }` is present.
- Not yet built for a real board or tested on hardware.

Open follow-ups:
- Hardware validation: confirm InputShaftSpeed reads sensibly when
  tcuInputSpeedSensorSharedWithVss is enabled and vehicleSpeedSensorInputPin
  is wired to the transmission input shaft sensor.
- Consider whether tcuInputSpeedSensorTeeth should warn/default from
  vssToothCount when shared is enabled, if users find the duplicate field
  confusing in practice.

## 2026-07-31 - A/C pressure fan mode: pressure is now the command, independent of compressor state

What was done:
- Fixed `FanController::enabledForAcByPressure()` (firmware/controllers/modules/fan_control/fan_control.cpp)
  in the existing `EFI_AC_PRESSURE_FAN` / `fan_ac_mode_e::Pressure` feature: previously it
  required `acActive` (A/C compressor currently enabled) AND a valid AcPressure reading before
  the fan could be commanded on. Per user direction, when a fan is set to Pressure mode the
  high-side pressure reading is the command by itself - if pressure is over the On threshold,
  the fan turns on regardless of whether the A/C compressor is currently engaged (e.g. static
  heat soak with the clutch open still raises high-side pressure and should still get airflow).
- Dropped the now-unused `acActive` parameter from `enabledForAcByPressure()` (and its call site
  in `FanController::getState()`); Relay mode is untouched and still gates on `acActive`.
- Updated the `fan1AcMode`/`fan2AcMode` field docs and the struct comment block in
  firmware/integration/config_page_6.txt to state that Pressure mode is independent of
  compressor state.

Decisions:
- Scoped strictly to the on/off relay-mode fan logic (`getState`/`enabledForAcByPressure`).
  Left the PWM-mode A/C adder path (`onSlowCallbackPwm`, still keyed off `acActive` via
  `getPwmAcAdder()`) untouched - it's a separate pre-existing TODO (pressure-proportional PWM
  curve) not part of this request.

Validation:
- Added `Actuators.FanAcPressureModeIgnoresCompressorState` in
  unit_tests/tests/actuators/test_fan_control.cpp: with the mock A/C compressor OFF, drives
  AcPressure sensor above/below the on/off thresholds and confirms the fan follows pressure
  alone (also covers invalid-pressure-reading fail-safe: fan not commanded on).
- `unit_tests/test.sh Actuators.FanAcPressureModeIgnoresCompressorState` - passes.
- Full `test.sh "Actuators.Fan*"` re-run after the (separately fixed) Oil Life Monitor
  gauge-name-length codegen issue was resolved: codegen and build now succeed; all 10
  Actuators.Fan* tests pass, including the new
  Actuators.FanAcPressureModeIgnoresCompressorState.

Open follow-ups:
- Consider whether the PWM-mode A/C adder should eventually get the same pressure-is-the-command
  treatment as the relay-mode path (existing TODO in fan_control.cpp).

## 2026-07-31 - Feature: Weighted Engine Oil Life Monitor (EFI_OIL_LIFE_MONITOR)

What was done:
- New AlphaX page-6 feature: tracks a temperature-weighted cumulative engine-revolution counter
  and reports remaining oil life as a percentage (`oilLifePercent` output channel), plus which
  temperature source is active (`oilLifeTempSource`).
- New module `firmware/controllers/modules/oil_life_monitor/` (`OilLifeMonitor : EngineModule`),
  registered in `engine.h`'s `type_list` and `modules/modules.mk`, gated by a new
  `EFI_OIL_LIFE_MONITOR` flag (FALSE on f4, TRUE on f7/h7 - see FEATURE_FLAGS.md).
- Algorithm: every `onSlowCallback()` tick, diffs `getRevolutionCounter()` against the last-seen
  value, reads `SensorType::OilTemperature` (falls back to `SensorType::Clt` if invalid, tracked
  via an internal `TempSource` enum), looks up a per-zone multiplier (fixed thresholds 70/105/125
  degC; 8 TS-tunable multipliers, oil vs. coolant-fallback x 4 zones), and accumulates
  `revs * multiplier` into an in-RAM `uint32_t`. `oilLifePercent = clamp(0,100, (1 - weightedRevs /
  (oilLifeRevsScaleMillions * 1e6)) * 100)`; `oilLifeRevsScaleMillions` is a TS-tunable 1-100 scalar.
- Persistence: deliberately NOT periodic. Accumulates in RAM for the whole time the ECU is
  powered and flushes to flash exactly once, on ignition-off, via a new `EFI_OIL_LIFE_RECORD_ID`
  storage item (`storage.h`/`storage.cpp`/`storage_sd.cpp`) and the `needsDelayedShutoff()`
  EngineModule hook (holds the main relay open until the write completes). Because of this, the
  feature requires `EFI_MAIN_RELAY_CONTROL` and enforces it with a compile-time `#error` guard -
  confirmed firing correctly for all four TRUE/FALSE combinations via a standalone preprocessor
  check. Consequently the feature is intentionally NOT enabled in the simulator
  (`simulator/simulator/efifeatures.h` sets `EFI_MAIN_RELAY_CONTROL FALSE`).
- Reset: both a TS command button (new `OIL_LIFE_RESET` in `bench_mode_e`, wired through
  `bench_test.cpp` / `cmd_oil_life_reset` / a new dialog under `&Advanced`) and a Lua function
  `resetOilLifeMonitor()` (`lua_hooks.cpp`, documented in `docs/AI/lua_scripting.md`), both calling
  the same `OilLifeMonitor::reset()`.
- Config fields added to `config_page_6.txt` (`PAGE6_DATA_VERSION` bumped 19 -> 20, defaults added
  in `custom_page.cpp`); output channels added to `console/binary/output_channels.txt` and wired
  in `status_loop.cpp`.

Decisions:
- Config scope: user chose AlphaX page 6 + dedicated `EFI_` flag (not a master-portable
  `rusefi_config.txt` addition), matching every other custom feature already on this branch.
- Zone multipliers are 8 discrete named TS fields, not a `float[8]` array - the zones are a fixed
  step function, not an interpolated curve, so discrete labeled fields read clearer in the TS UI.
- No periodic flash save (unlike the LTFT `SAVE_AFTER_HITS` precedent this was originally modeled
  on) - user explicitly rejected it: flash can't be written while the engine runs on most boards
  anyway, so the only meaningful save point is ignition-off.
- `oilLifePercent` is an `output_channels.txt` gauge only, no `LiveData.yaml` live-dialog-panel
  addition (used by Misfire/Burst Knock/WOT Enrichment) - not required by the spec.

Validation:
- `unit_tests/tests/test_oil_life_monitor.cpp` (6 tests: percent formula incl. div-by-zero
  fail-open, zone boundary edges for both temp sources, sensor fallback flip/recovery,
  weighted-rev accumulation math, shutdown-save `needsDelayedShutoff()` transition, reset) - all
  pass. Plus `LuaHooks.ResetOilLifeMonitor` in `test_lua_hooks.cpp` exercising the actual Lua
  binding. Full `unit_tests/test.sh` run: 1305/1306 pass; the one failure
  (`ClosedLoopFuel.StateBasedRegionMapping`) is pre-existing and unrelated (confirmed failing in
  isolation on a clean `git status` for the STFT files it touches).
- Full firmware build: `proteus` F7 (`EFI_OIL_LIFE_MONITOR=TRUE`) links successfully. `f407-discovery`
  F4 (`EFI_OIL_LIFE_MONITOR=FALSE`, stub path) - all Oil-Life-Monitor-touched object files
  (`oil_life_monitor.o`, `storage.o`, `custom_page.o`, `status_loop.o`, `bench_test.o`,
  `lua_hooks.o`, `storage_sd.o`) compiled cleanly; the board's full link was blocked by a
  pre-existing, unrelated `ramdisk_image` codegen issue on this branch (stale placeholder left
  over from a prior `proteus_f7` build; matches a previously-recorded F4 INI-ramdisk-limit issue on
  this branch) - not caused by this feature, not fixed here.
- Found (via a concurrent session's report entry above, which hit it as a side effect) and fixed a
  real bug this feature introduced: the initial `oilLifePercent`/`oilLifeTempSource` output-channel
  comments exceeded `DataLogConsumer`'s 34-char gauge-name limit, breaking `LiveDataProcessor`
  codegen for every board. Fixed by giving both fields a short first-line gauge name
  (`Oil Life %` / `Oil Life Temp Src`) with the longer description on a second `\n`-separated line,
  matching the existing `actualLastInjectionRatio`-style convention.
- Confirmed the `#error` guard with a standalone `g++` preprocessor check across all four
  `EFI_OIL_LIFE_MONITOR` x `EFI_MAIN_RELAY_CONTROL` TRUE/FALSE combinations.

Open follow-ups:
- The pre-existing `ramdisk_image` / F4 INI codegen issue still blocks a full f407-discovery link;
  unrelated to this feature.
- The pre-existing `ClosedLoopFuel.StateBasedRegionMapping` unit test failure is unrelated and
  still open.
- No hardware validation yet (flash persistence across a real power cycle, TS dialog/button
  round-trip) - only unit tests and firmware compilation were exercised this session.

## 2026-08-01 - Transmission Settings / TCU: trim UI to a minimal working subset, add 5 gauges

Context: the native TCU stack (`firmware/controllers/tcu/`) is marked by its own readme as
"very unfinished... no plans to invest into this area" (09/2022). Its TS "Transmission
Settings" surface had accumulated dialogs for features that either don't work end-to-end
(line-pressure-per-gear/per-shift, 3-2 solenoid duty table - all `Gm4l6x`-only) or become
unreachable once mode-selection dropdowns are removed (range-selector matrix belongs to
`GearControllerMode::Generic`, button-shift belongs to `ButtonShift` - neither is the mode
being defaulted to). User also supplied a working reference Lua TCU script (CAN-sourced
sensors, VSS/TPS shift tables + WOT curves, 2-solenoid PWM, idle-forced-1st-gear, 5
`setLuaGauge()` outputs) to compare against the native implementation and mine for gauge
ideas. Comparison finding: the Lua script isn't a new architecture, it's a more complete,
currently-functional version of what `AutomaticGearController`/`SimpleTransmissionController`
already do on paper (VSS/TPS shift-table state machine, per-gear solenoid pattern table) -
just missing WOT curves, idle-shift, and gear-verification timeout. This pass ports the gauge
surface only, not the WOT-curve algorithm (separate future project).

What was done:
- `tunerstudio.template.ini`: rewrote `transmissionPanel` (kept TCU Enabled, added "# of
  Gears" locked to 4), `shiftSolenoidPanel` (trimmed from 6 solenoids + 3-2 solenoid down to
  just Solenoid 1 & 2), `otherSolenoidPanel` (kept TCC on/off, TCC PWM, pressure control -
  ungated by mode), migrated `inputSpeedSensorPanel` into `tcuControls` as a 5th panel.
  Deleted `buttonShiftInputPanel`, `rangeMatrixInputPanel`, `gearControls` (emptied once its
  two panels were removed), `inputSpeedSensor` (standalone wrapper), `pcPerGearDialog`,
  `pcPerShiftDialog`, `32Dialog`, `rangeMatrixDocumentation`, `rangeMatrixDialog`. Left
  `shiftSpeedDialog`, `tccCurves`, `tcuSolenoidTableTbl` untouched per explicit user decision.
- `top_level_menu.ini`: removed the 6 now-dead subMenu lines to match.
- `rusefi_config.txt`: `totalGearsCount` (pre-existing but never TS-exposed field) got its
  `lo,hi` clamped from `1, TCU_GEAR_COUNT` to `4,4` plus a descriptive comment - this is the
  zero-risk way to render a scalar as a locked spinner in this ini dialect (no per-field
  min/max override syntax exists). Added a `//`-comment near `TCU_SOLENOID_COUNT` documenting
  future 6-solenoid support (10R80 motivating example).
- `default_base_engine.cpp`: `defaultsOrFixOnBurn()` now forces `gearControllerMode` ->
  `Automatic` and `transmissionControllerMode` -> `Generic4` whenever `tcuEnabled` is true and
  they're still `None` (the as-shipped default) - the established idiom for "hardcode a
  default without a config-layout change" (see `docs/calibration-compatibility.md`), so TCU
  works without the now-removed mode dropdowns. Guarded by `== None` so explicit presets
  (`configureTcu4R70W()`) and existing unit tests are untouched.
- `tcu_controller.txt` + `simple_tcu.cpp` + `gc_auto.cpp` + `gauge_declarations.ini`: added 5
  new fields modeled on the Lua script's gauges, all under the existing `gaugeCategory =
  Transmission` block, gated `@@if_show_tcu_gauges` like their nearest siblings:
  `tcu_solenoid1On`/`tcu_solenoid2On` (read back from the existing `tcuSolenoidTable` lookup
  in `SimpleTransmissionController::update()`), `tcu_idleShiftToFirst` (new behavior - forces
  a downshift to 1st at idle in `AutomaticGearController::update()`, previously nothing did
  this), `tcu_upshiftMargin`/`tcu_downshiftMargin` (captured from the existing `curveSpeed`
  computation in `AutomaticGearController::shift()`).
- `unit_tests/tests/test_tcu.cpp`: added 5 new tests (mode defaulting on/off, mode not
  clobbered when already explicit, idle-shift-to-first fires and clears, solenoid/margin
  gauge values against the `TCU_4R70W` preset's known shift tables at a bin-aligned TPS).

Gotchas hit:
- `rusefi_config.txt`/`*.txt` struct-definition comments do NOT support `;`-prefixed
  standalone line comments (that's an `.ini`-only convention) - `ConfigDefinition` throws
  `Cannot parse line`. Standalone comments in these files use `//` (or legacy `!`).
- The 34-char `DataLogConsumer` gauge-name limit (documented in CLAUDE.md for
  `output_channels.txt`) also applies to `tcu_controller.txt` struct-field comments feeding
  `LiveData.yaml` - `tcu_upshiftMargin`'s first attempt (a long single-line comment) broke
  `LiveDataProcessor` codegen for every board. Fixed with the `\n`-split short-name/long-desc
  convention.
- Confirmed via `gauge_declarations.ini:330` that `tcuDesiredGear`/`desiredGearGauge` (the
  Lua script's gauge #1, "intended gear") already existed - zero new plumbing needed for it.

Validation:
- `unit_tests/test.sh`: 1314/1315 pass. The one failure, `ClosedLoopFuel.StateBasedRegionMapping`,
  is unrelated (STFT region-for-state mapping, no file this session touched) and reproduces in
  isolation - pre-existing on this branch.
- All 7 tests in the `tcu` suite pass (2 pre-existing + 5 new).
- `firmware/gen_config_board.sh config/boards/proteus proteus_f7` regenerated cleanly; manually
  inspected the generated `rusefi_proteus_f7.ini` to confirm the trimmed `tcuControls` dialog
  matches spec exactly and all 9 deleted dialogs are absent, and that the 5 new gauge fields
  (`entry =`, `indicator =`, `graphLine =`) are present.

Open follow-ups:
- TCC PWM Solenoid fields stay visible per user's explicit "keep the tcc solenoids" (plural)
  instruction, but `Generic4TransmissionController` (the hardcoded default) never drives that
  pin - only `Gm4l6xTransmissionController` does. So those 3 fields are currently assignable
  but inert plumbing under the new default. Flagged to the user before implementation; no
  change requested.
- 5-10 gear support and the WOT-curve shift logic from the reference Lua script are explicitly
  out of scope - `AutomaticGearController`/`Generic4TransmissionController` remain hardcoded
  to a 4-gear, non-WOT-aware state machine.
- No hardware/TS-console validation this session (both `ts_show_tcu` and `show_tcu_gauges`
  alpha flags stay `false` by default, unchanged) - only codegen + unit tests were exercised.
- `ClosedLoopFuel.StateBasedRegionMapping` remains open and unrelated to this work.

## 2026-08-01 - TCU follow-up: fix invisible gauges, make idle-shift-to-first configurable + SM-driven

Two corrections to the same-day TCU rework above, both reported by the user after reviewing
the generated console.

**1. New Transmission gauges were invisible in TunerStudio.** All 5 new gauges added earlier
today were gated `@@if_show_tcu_gauges`, matching `desiredGearGauge`/`currentGearGauge`/
`ISSGauge`/`tcRatioGauge` (the "most similar" siblings, per that session's own flagged
judgment call). Checked every `board.mk`/`prepend*.txt` in the repo: `show_tcu_gauges`
defaults `false` (`rusefi_config.txt:2941`) and **no board anywhere overrides it to `true`** -
so that gate is dead code, permanently hiding anything behind it. Fix: dropped the
`@@if_show_tcu_gauges` suffix from the 5 new gauge lines in `gauge_declarations.ini` to match
the *majority* of the category's gauges (`detectedGearGauge`, `speedToRpmRatioGauge`,
`shiftTimeGauge`, `idealEngineTorqueGauge`, `pressureControlGauge`, `torqueConverterGauge`,
all ungated). Verified by regenerating `protorico-econoline`'s `.ini` (`EFI_TCU=TRUE`,
`ts_show_tcu=true`) - all 5 now appear under `gaugeCategory = Transmission`. Did not touch the
4 pre-existing gauges still gated behind the same dead flag (out of scope, pre-existed before
today's TCU rework).

**2. Idle-shift-to-first made configurable and delegated to the Engine State Machine.** The
feature was unconditionally on with hardcoded RPM/TPS/VSS thresholds duplicated in
`gc_auto.cpp`. Per user request:
- Added `bit tcuIdleShiftToFirstEnabled` and `uint8_t tcuIdleShiftToFirstMaxVss` (km/h, 0 =
  ignore speed entirely) to `rusefi_config.txt`, exposed in the `shiftSettingsPanel` of
  Transmission Settings as "Shift to First if Idle" / "Idle Shift Max Speed (km/h, 0 = ignore
  speed)", the latter greyed out unless the former is checked.
- Then, per a second follow-up request, replaced the hardcoded RPM/TPS idle check entirely
  with a query to the Engine State Machine's `engineSmIsIdle` bit
  (`engine->module<EngineStateMachine>().unmock().engineSmIsIdle`) - the exact same
  idiom `MisfireController::onEnginePhase` already uses for its own idle-only gating
  (`misfire_detection.cpp:194`). `gc_auto.cpp` no longer computes idle itself at all; it just
  asks the state machine and applies the optional VSS gate on top.
- Default `tcuIdleShiftToFirstEnabled = true` set in `setDefaultBaseEngine()` (not
  `defaultsOrFixOnBurn()` - a plain bit has no "unset" sentinel distinguishable from a
  deliberate `false`, so the migration-safe `== 0` guard pattern doesn't apply here; this is a
  brand-new field on an unreleased feature, so a real factory default in the reset-to-defaults
  path is correct and won't fight a user's later choice to disable it on burn).
  `tcuIdleShiftToFirstMaxVss` needs no explicit default - 0 (ignore speed) is naturally both
  the zero-init value and the safe/neutral choice per `docs/calibration-compatibility.md`.

Gotcha hit: `tcuEnabled`/`gearControllerMode`/`totalGearsCount` (accessed via
`engineConfiguration->`) and `tcu_shiftTime`/`tcu_shiftSpeed12`/my new idle fields (accessed
via `config->`) are declared in the *same* `rusefi_config.txt` file but land in two different
generated C++ structs - `engine_configuration_s` (lines 1375-6824 of the generated header) vs.
a second struct nested in `persistent_config_s` alongside it (~lines 6982-8821). Using the
wrong pointer for a new field compiles fine for `.ini`/gauge purposes (TS's flat field
namespace doesn't care) but fails C++ compilation with a "no member named X" error that
doesn't obviously point at the real cause. Fixed by matching the pointer convention of the
nearest pre-existing sibling field in the `.txt` file (`config->tcu_shiftTime` right next to
my insertion), not by assuming `engineConfiguration`/`config` are interchangeable aliases.

Validation: `unit_tests/test.sh` - 1316/1317 pass (all 9 `tcu` tests, including 2 new:
`testIdleShiftToFirstDisabled`, `testIdleShiftToFirstVssThreshold`; `testIdleShiftToFirst`
rewritten to drive `engineSmIsIdle` directly instead of mocking RPM/TPS/VSS). The one failure
is the same pre-existing unrelated `ClosedLoopFuel.StateBasedRegionMapping`. One test-design
pitfall worth noting for future TCU tests: forcing `desiredGear` down via the idle-shift path
and then leaving VSS at a "driving" value in the same update() call lets the *ordinary*
VSS/TPS shift-table logic in the same `update()` immediately shift back up before the test can
observe the idle-forced gear - discovered via `testIdleShiftToFirst` failing until the idle
step's VSS mock was also dropped to a realistic (stopped) value; the dedicated VSS-threshold
test sidesteps this by using a TPS value (11%, `tcu_shiftTpsBins[0]`) whose ordinary shift
thresholds sit safely below every VSS value the test uses.

Open follow-ups: same as the original TCU entry above (no >4 gear/WOT support, no hardware/TS
validation, `ClosedLoopFuel.StateBasedRegionMapping` still open).

## 2026-08-01 - alphax-s550-pnp: A/C Pressure reads wrong on power-on until pin is re-selected

**Symptom** (user-reported, real hardware): on the S550 PNP board, the A/C Pressure sensor
(PF9 mux=1, `EFI_ADC_43` which is numerically channel 44 - this board's `adc_channel_e` enum
has a permanent +1 offset from `EFI_ADC_NONE=0`) reads a plausible-looking but wrong voltage
(~0.8-0.9V) from power-on, and only reads correctly (~1.45-1.5V, matching real A/C system
pressure) after the user manually re-selects the input in TunerStudio away from A/C Pressure
and back (any burn touching that specific field - "any burn" alone, e.g. an unrelated fan
setting, does not fix it).

**Investigation path** (several disproven theories worth recording so they aren't re-tried):
- Not a mux-GPIO-polarity/boot-race issue (this board sets `ADC_MUX_PIN_INVERTED=1`) - a patch
  forcing the mux to its documented primary state at `portInitAdc()` was written, then reverted
  once hardware data contradicted it (the bad reading is stable/rock-steady for 10+ seconds,
  not a one-cycle race that a low-pass filter would self-correct).
- Not `AdcSubscription`'s per-channel `VoltsPerAdcVolt` divider-coefficient caching - the
  `sensorinfo` console command showed `divider=2.00` identically in both the wrong and fixed
  states.
- Not a silent ADC3 conversion failure - `ECU: Slow ADC errors`/`overruns` sat at flat 0 in the
  user's `.msl` log throughout the bad-reading window.
- Not a slow analog RC settling time on the sensor's own input filter - proven wrong by the
  user: leaving the (still-wrong) reading untouched for 20-30+ seconds does not make it
  converge; it only ever fixes instantly, exactly when the A/C-Pressure channel field itself is
  reconfigured+burned.
- A real, reproducible-on-the-bench-with-nothing-connected anomaly was key: added a `muxdiag`
  console command (`stm32_adc_v2.cpp`) dumping the mux GPIO logic level, PF9's *actual* GPIO
  mode/pull straight from the hardware registers (`debugBrainPin(..., Gpio::F9)`), and raw
  ADC counts for both mux positions of all 16 standard channels - all in one shot, so a "stuck
  wrong" state and a "just fixed" state can be compared without needing to catch a boot-time
  transient (the bad reading persists indefinitely once present). This showed PF9 sitting at
  **`Input Pull-down`** (not `Mode Analog`) whenever A/C Pressure read wrong, flipping to
  `Mode Analog` the instant the fix was applied - with nothing connected on the bench, ruling
  out any real sensor/hardware explanation entirely.

**Root cause**: `adcIsMuxedInput()`/`adcMuxedGetParent()` (`firmware/hw_layer/ports/stm32/
stm32_adc.cpp`) only recognize `adc_channel_e` values 40-47 as "muxed" (an alias of a lower
root channel, needing pin-ownership-bypass handling) when `ADC3_SLOW_CHANNEL_COUNT` is defined
- and grepping the whole repo confirms **no board anywhere defines that macro**; it's dead
code. This board (alphax-s550-pnp) populates channels 40-47 through a *different*, unguarded
mechanism instead (`board.mk`'s `-DEFI_SLOW_ADC=ADCD3`, aliased in `stm32_adc_v2.cpp::
readSlowAnalogInputs()`'s `EFI_SLOW_ADC == ADCD3` block), which those two lookup functions
didn't know about. Consequence: A/C Pressure's channel (44) was never recognized as muxed, so
`getAdcChannelBrainPin()` couldn't even resolve it to a physical pin (its lookup table only
lists root channels; the 44->36 alias translation is exactly what `adcMuxedGetParent()` is
supposed to provide and didn't), and `AdcSubscription::SubscribeSensor()` therefore never
touched PF9's GPIO pad mode at all on a normal boot - it just sat at this MCU's power-on
default (`stm32f7/board.h`: `EFI_DR_DEFAULT = PIN_PUPDR_PULLDOWN`, applied to *every* pin),
which is noisy enough (digital input circuitry active) to overpower the board's 680k pulldown
and read a plausible-but-wrong voltage. TPS/PPS live on the exact same shared-pin structure
(e.g. TPSA/PPSB are also in the unrecognized 40-47 range) but were never affected, because
their *root* counterpart (TPSB/PPSA, `setTPS1Inputs`/`setPPSInputs`) is *also* permanently,
independently subscribed and correctly configures the shared physical pin regardless - A/C
Pressure's root-channel sibling (Fuel Rail Pressure) is not independently active in this tune,
so nothing else ever came along to fix the pin, until the user's manual pin-swap-and-back
incidentally did (by momentarily subscribing the root/Fuel-Rail-Pressure channel, which *is*
correctly resolved, setting PF9 to analog and leaving it there).

**Fix**: extended `adcIsMuxedInput()`/`adcMuxedGetParent()` with an `#elif defined(EFI_SLOW_ADC)
&& (EFI_SLOW_ADC == ADCD3)` branch recognizing 40-47 unconditionally in that case. Scoped
correctly - confirmed via repo-wide grep that alphax-s550-pnp is the only board defining
`EFI_SLOW_ADC=ADCD3`, so this is a no-op for every other board.

**Validation**: full firmware build for alphax-s550 (F7) succeeds. User confirmed on real
hardware, via the new `muxdiag` command: PF9 now reads `Mode Analog` on a fresh reboot with
no pin-swap workaround needed at all (previously always `Input Pull-down` until manually
fixed). Did not run `unit_tests/test.sh` - this fix lives entirely in `EFI_PROD_CODE`-only,
STM32-hardware-specific files with no host-side test coverage.

**Kept**: the `muxdiag` console command (`stm32_adc_v2.cpp`, gated `#if ADC1_SLOW_MUXED`) -
cheap, generically useful for this whole shared-mux board family for any future "which mux
channel is actually configured how" debugging, not just this one bug.

Open follow-ups: none identified for this specific bug. Worth a broader repo grep next time
someone touches `ADC3_SLOW_CHANNEL_COUNT` to confirm whether that whole code path (also
unreferenced by any board) should be removed outright rather than left as effectively-dead
code that nearly caused a second maintenance-time mix-up.

## 2026-08-01 - TCU follow-up 2: expose commanded gear, wire "Current Gear" to real gear detection

User reported live-testing: at conditions where the TCU should be commanding 1st gear, the
"TCU: Solenoid 1 On" gauge read 0 despite the configured solenoid table requiring solenoid 1
on / solenoid 2 off for gear 1. Asked for a "commanded gear" gauge to cross-check against.

Investigation found the diagnostic tool they needed already existed but was invisible:
`desiredGearGauge`/`currentGearGauge`/`ISSGauge`/`tcRatioGauge` in `gauge_declarations.ini`
were still gated `@@if_show_tcu_gauges` - the same dead flag fixed for the 5 gauges added
earlier today, just not touched then because that fix was scoped to only the new gauges.
`tcuDesiredGear` ("Desired Gear") is exactly "the gear passed to the solenoid lookup table" -
`GearControllerBase::update()` calls `transmissionController->update(getDesiredGear())`
directly, and that same value indexes `tcuSolenoidTable` in `SimpleTransmissionController::
update()`. Un-gated all 4 remaining `@@if_show_tcu_gauges`-gated Transmission-category gauges
so the user can now see it. Re-verified the solenoid capture formula added earlier
(`config->tcuSolenoidTable[i][static_cast<int>(gear) + 1]`) is byte-for-byte identical to the
pre-existing formula that drives the physical solenoid pins (`simple_tcu.cpp`), so a gauge/pin
mismatch given the same commanded gear should not be possible - the live-test discrepancy is
most likely explained by the commanded gear not actually being 1 at that moment, or testing
against a pre-today firmware build; newly-visible "Desired Gear" should confirm which.

Follow-up user request, addressed in the same session: **redefine gauge semantics.**
"Desired Gear" should stay as-is (commanded/solenoid-lookup value). "Current Gear" should
instead be *derived from the VSS/RPM ratio* (same concept as "Detected Gear" - user explicitly
equated the two), not a mirror of the commanded value.

Found `firmware/controllers/modules/gear_detector/gear_detector.cpp` (`GearDetector`, compiled
into every board unconditionally via `controllers/modules/modules.mk`) already does exactly
this: computes driveshaft RPM from `SensorType::VehicleSpeed` + `driveWheelRevPerKm` +
`finalGearRatio`, compares against `InputShaftSpeed` (or `Rpm` if no ISS), matches the ratio
against a per-gear `gearRatio[]` table, and publishes the result as `SensorType::DetectedGear`.
This module was previously dormant/disconnected from the TCU work: `gearRatio[]` (the
threshold table it needs) was declared in `rusefi_config.txt` but had **zero TS exposure
anywhere** - so it was permanently all-zeros, which would trigger `GearDetector::
initGearDetector()`'s `criticalError("Expecting positive gear ratio for #%d", ...)` (halts the
engine) for anyone who happened to have `totalGearsCount != 0`. It stayed silently safe only
because nothing ever set `totalGearsCount` either.

Also found (before making any change) that `totalGearsCount` and a full 10-entry `gearRatio1..
10` table **already exist** in a pre-existing `gearDetection` panel inside the "Speed sensor"
dialog (`tunerstudio.template.ini:4478`, part of the always-visible `speedSensor` dialog) -
this morning's earlier TCU pass had duplicated `totalGearsCount` into a new "# of Gears" field
inside Transmission Settings without knowing this, and additionally clamped its `lo,hi` to
`4,4` in `rusefi_config.txt` - which would have silently broken `gearDetection`'s existing
5th-10th-gear fields (and any non-TCU/manual-transmission use of `GearDetector`) for every
board, since the field is shared, not TCU-exclusive.

Asked the user whether `GearDetector` should auto-arm with placeholder ratios or stay
opt-in-only; they chose opt-in (matches existing default, zero risk) and specified the gear
ratio table belongs solely in the Speed Sensor dialog, not duplicated into Transmission
Settings. Implemented:
- `rusefi_config.txt`: reverted `totalGearsCount`'s `lo,hi` from `4,4` back to `1,
  @@TCU_GEAR_COUNT@@` (its original range); updated its comment to explain the field is shared
  between `GearDetector` (any count) and TCU Automatic mode (hardcoded to 4 gears regardless of
  this count) and that it's configured in the Speed Sensor dialog.
- `tunerstudio.template.ini`: removed the duplicate "# of Gears" field + its comment block from
  `transmissionPanel`, replaced with a single `field = "!..."` pointer note directing to the
  Speed Sensor dialog.
- `tcu.cpp`: `TransmissionControllerBase::postState()` no longer sets `tcuCurrentGear =
  getCurrentGear()` (the last-commanded-gear tracker, which is still needed internally
  unchanged for `Generic4TransmissionController`'s shift-start detection via `shiftingFrom`/
  `isShifting`). It now reads `Sensor::get(SensorType::DetectedGear)` and only updates
  `tcuCurrentGear` when that sensor is valid, otherwise retaining its last value. Zero risk of
  the `criticalError` path being hit by this change alone, since `totalGearsCount` still
  defaults to 0 and nothing in this pass changes that default.
- `gauge_declarations.ini`: un-gated `desiredGearGauge`/`currentGearGauge`/`ISSGauge`/
  `tcRatioGauge` (dropped `@@if_show_tcu_gauges`), matching the fix already applied to the 5
  gauges added earlier today and the majority-ungated convention in that category.

Validation: `unit_tests/test.sh` - 1316/1317 pass, same pre-existing unrelated
`ClosedLoopFuel.StateBasedRegionMapping` failure, no `tcu` or `gear_detector` test regressions
(neither test file references `tcuCurrentGear`/`getCurrentGear()` directly, so none needed
updating). Regenerated `protorico-econoline`'s `.ini` and confirmed: Transmission Settings no
longer duplicates the gear-count field, the pre-existing Speed Sensor dialog's 10-gear table is
back to its full un-clamped range, and all 9 Transmission-category gauges (4 re-enabled + 5
from earlier today) are present.

Open follow-ups:
- `tcuCurrentGear` ("Current Gear") will read invalid/stale until a user actually configures
  "Forward gear count" and the per-gear ratio table in the Speed Sensor dialog - this is
  unfinished setup work inherent to `GearDetector` itself, not something this pass changes.
- Live-hardware confirmation of the original solenoid-gauge-vs-commanded-gear discrepancy is
  still outstanding - depends on the user re-testing with today's build and the now-visible
  Desired Gear gauge.
- Same open items as both earlier TCU entries today (no >4-gear/WOT support in Automatic mode,
  `ClosedLoopFuel.StateBasedRegionMapping` still open, no hardware validation this session).

## 2026-08-01 - TCU follow-up 3: root-caused "Desired Gear stuck at 0" via user-supplied .msl log

User captured a short log (`whygear0.msl`, protorico-econoline, engine idling, RPM ~886, VSS
0) showing every TCU channel pinned at 0 the whole time: Desired Gear, Current Gear, both
solenoid-on flags, EPC/TC Duty. Engine SM channels (`Engine SM: enabled`/`Engine SM: Idle` = 1)
confirmed the rest of the ECU was running fine, isolating the problem to the TCU chain
specifically. Parsed the .msl header (tab-separated, columns at fixed offsets after 5 header
lines) with a small Python script to pull just the relevant columns across all 113 rows rather
than reading the ~30k-token raw file.

Root cause, established by elimination against the actual code path (not the log alone):
`AutomaticGearController::update()` unconditionally promotes `NEUTRAL -> GEAR_1` the instant
it's called (`if (getDesiredGear() == NEUTRAL) setDesiredGear(GEAR_1);`) - so `desiredGear`
staying 0 across 113 rows / 1.2s only makes sense if that `update()` call never ran at all,
which happens if either `tcuEnabled` is false or `gearControllerMode == None`
(`engine_controller.cpp:192`'s gate). User confirmed `tcuEnabled` was on, narrowing it to
`gearControllerMode`. `defaultsOrFixOnBurn()`'s TCU block (added earlier today) only forced
the mode when it was still exactly `None`, specifically to avoid disturbing
`configureTcu4R70W()`'s deliberate `Generic` selection - but that same guard meant a tune
already sitting on `Generic` or `ButtonShift` from *before* today's UI changes (dropdown +
range-selector dialog both removed) would never get corrected, and had no way to be fixed
through TS anymore either (nothing left in the UI reads or writes those fields). User confirmed
this board previously had "Generic gear controller" selected in an earlier firmware build -
exact match.

User's call on the tradeoff (asked because it also affects `configureTcu4R70W()`, a
hypothetical real-board preset unrelated to this specific bug): don't preserve compatibility
with anything, this is a ground-up reimplementation. Changed `defaultsOrFixOnBurn()`'s TCU
block from "set only if still `None`" to **unconditional**: whenever `tcuEnabled`, force
`gearControllerMode = Automatic` and `transmissionControllerMode = Generic4` on every boot,
full stop, overriding whatever was previously persisted (including `configureTcu4R70W()`'s
explicit `Generic` choice, and including a mode a user leaves selected while `tcuEnabled` is on
- there is no longer any code path that can set anything else, so this simply keeps
re-asserting the only supported state every startup/burn).

Updated `test_tcu.cpp`'s `testDefaultModeDoesNotOverrideExplicitChoice` (whose whole premise -
"a tune with Generic set must not be touched" - is now the opposite of intended behavior) to
`testDefaultModeOverridesExplicitChoice`, asserting a `Generic`-mode tune gets forced to
Automatic/Generic4. Along the way discovered `EngineTestHelper` construction itself already
runs `defaultsOrFixOnBurn()` a second time post-`applyEngineType()` (simulating a real boot
sequence past the initial "reset to defaults" pass) - so `configureTcu4R70W()`'s live `Generic`
selection was *already* being overridden to `Automatic` by the time the test body started
running, before its own explicit `defaultsOrFixOnBurn()` call. Rewrote the test to explicitly
re-set `gearControllerMode = Generic` after construction (simulating a stale *persisted* value,
which is the actual real-world scenario) rather than relying on the preset's transient
in-memory value, which is both more realistic and avoids the ordering trap.

Validation: `unit_tests/test.sh` - 1316/1317 pass, same pre-existing unrelated
`ClosedLoopFuel.StateBasedRegionMapping` failure; the 9 `tcu` tests all pass including the
rewritten mode-override test. No other tests reference `gearControllerMode`/
`transmissionControllerMode` post-`defaultsOrFixOnBurn()` in a way this change could affect.

Open follow-ups:
- User has not yet re-flashed/re-tested on the actual protorico-econoline hardware to confirm
  the fix resolves the stuck-at-NEUTRAL symptom live - this session's validation is unit-test
  only.
- `GenericGearController`/`ButtonShiftController` and their supporting config fields
  (range-selector matrix, button pins) are now fully unreachable dead code paths in production
  (no UI can select or configure them, and the one remaining C++ path that could -
  `configureTcu4R70W()` - is itself now overridden every boot). Not removed this session; worth
  a follow-up cleanup pass given the user's "ground-up reimplementation" framing.
- Same other open items as the earlier TCU entries today (no >4-gear/WOT support in Automatic
  mode, `ClosedLoopFuel.StateBasedRegionMapping` still open).

## 2026-08-01 - protorico-econoline: enable CLT-from-CHT estimation

User asked to enable the CHT-to-CLT estimator (`cht_clt_estimator.h`/`.cpp`, page 6
`cltFromCht`) for protorico-econoline. This board is a Ford Modular V8 (firing order
`FO_1_3_7_2_6_5_4_8`, cylindersCount 8) - these engines ship with a head-mounted CHT sensor and
no separate coolant sensor, so the harness signal previously wired as `clt.adcChannel` (labeled
`CLT_OUT` on the connector, PC2 / `H144_IN_CLT`) is actually a CHT signal.

Two things were required, not just the runtime toggle:
1. `board.mk`: this board's `meta-info.env` pins `PROJECT_CPU=ARCH_STM32F4`, and
   `stm32f4ems/efifeatures.h` defaults `EFI_CHT_CLT_ESTIMATOR` to `FALSE` (only
   `stm32f7ems`/`stm32h7ems` default it `TRUE`) - without an explicit override the estimator
   code compiles out entirely (`cht_clt_estimator.cpp`'s `#else` stub). Added
   `-DEFI_CHT_CLT_ESTIMATOR=TRUE`. Caught this only after the user asked "don't we need to
   enable this in board.mk?" - initially assumed it was already compiled in because
   `board.mk` has F7/H7-conditional sections, without checking which `PROJECT_CPU` this board
   actually builds as.
2. `board_configuration.cpp`: repointed the PC2 ADC input from `engineConfiguration->clt` to
   `engineConfiguration->chtSensor` (nothing else on this board reads `chtSensor`, so it was
   previously wired to nothing), gave `chtSensor.config` a placeholder thermistor curve (reused
   the same generic NTC curve `engine_configuration.cpp` uses as the global `clt` default -
   `chtSensor` has no default curve set anywhere in the codebase, and an unconfigured
   `{0,0,0,...}` curve trips `validateThermistorConfig`'s ascending-order check and calls
   `firmwareError` at boot), and set `getCustomPage()->cltFromCht = true` in
   `protorico_econoline_boardDefaultConfiguration()` (runs after `resetExtraPages()`'s
   `customPageSetDefaults()`, which sets `cltFromCht = false`, so the override sticks; it's a
   soft default like the other ADC channel assignments in the same function, not forced via
   `ConfigOverrides`, so a user can still flip it back to a real CLT sensor in TS if the harness
   changes).

Validation: full firmware build via `bin/compile.sh config/boards/protorico-econoline/meta-info.env
-j12` - succeeds, flash 75.86% (571712/736KB), ram0 100% (pre-existing headroom pattern, not a
regression). Not flashed/tested on hardware this session.

**Follow-up same day**: user reported `build_gui.py`'s bundle build (`compile.sh -b ...`, which
additionally builds the OpenBLT bootloader region) failing with `LAUNCH_POWER_RAMP_CURVE_SIZE`/
`BURST_KNOCK_*_SIZE`/`WOT_ENRICHMENT_SIZE was not declared in this scope` plus a static_assert
failure, all in `page_6_generated.h`, compiling `board_configuration.o` under `-DEFI_BOOTLOADER`.
Root cause: `#include "custom_page.h"` (added above, for `getCustomPage()`) pulls in
`page_6_generated.h` directly; those curve-size macros are normally supplied by `engine.h`'s
unconditional module-header includes (`launch_power_ramp.h`, `burst_knock.h`,
`wot_enrichment.h`), but the bootloader's compile of `board_configuration.cpp` never includes
`engine.h` at all (`pch.h` only pulls in `engine_configuration.h`, and the bootloader
never runs engine config) - so in that one translation unit the macros were simply never
defined. Confirmed no other OpenBLT board (`f407-discovery`, `alphax-s197-v2`,
`alphax-gold`, `alphax-2chan`, etc.) includes `custom_page.h` from `board_configuration.cpp`,
which is why this class of break hadn't surfaced before. Fix: wrapped the `#include
"custom_page.h"` and the `getCustomPage()->cltFromCht = true;` call in `#ifndef
EFI_BOOTLOADER` (mirroring the guard `engine.h` itself uses around
`engine_modules_generated.h`) - both are dead code under `EFI_BOOTLOADER` anyway.
Re-validated with the actual failing command, `bin/compile.sh -b
config/boards/protorico-econoline/meta-info.env BUNDLE_SIMULATOR=false` (bootloader + firmware
+ bundle zip) - now completes successfully end to end.

Open follow-ups:
- `chtSensor.config` curve is an unvalidated placeholder (same caveat as the existing CLT and
  EOT estimator defaults) - needs bench/real-sensor calibration against the actual Ford CHT
  sensor part before trusting the reported temperature.
- Not yet confirmed on hardware that PC2 is actually reading a CHT-characteristic sensor and
  not something else; relies on user's stated wiring.
- Only validated the plain `bin/compile.sh ... -j12` build the first time, missing that
  `build_gui.py`/`compile.sh -b` exercises an additional bootloader compile of the same source
  file with a much smaller define/include set - worth remembering to test the `-b` bundle path
  (or at least grep for what an added `#include` pulls in) whenever touching a board's
  `board_configuration.cpp` on an OpenBLT-enabled board, not just the plain firmware build.

## 2026-08-01 - Oil Life Monitor: add set_oil_life console command

What was done:
- Added `OilLifeMonitor::setOilLifePercent(float percent)`: clamps to 0-100, converts back to
  a weighted-revolution count using the current `oilLifeRevsScaleMillions`, and immediately
  requests a flash flush (`requestFlush()`), same as `reset()`.
- Wired it up as a console command `set_oil_life` (`addConsoleActionF`, `initOilLifeMonitor()`
  in `oil_life_monitor.cpp`), e.g. `set_oil_life 62.5`, for manually correcting the tracked
  value after a settings loss. Not exposed in TunerStudio - it's a one-off correction, not a
  tune setting.
- Added the `EFI_UNIT_TEST`-stub counterpart (`void OilLifeMonitor::setOilLifePercent(float) {
  }`) alongside the other stubbed methods for builds with `EFI_OIL_LIFE_MONITOR` off.

Validation:
- `unit_tests/tests/test_oil_life_monitor.cpp`: new `OilLifeMonitor.SetOilLifePercent` test
  covers the direct call (75% round-trips exactly) and clamping at both ends (150 -> 100,
  -10 -> 0).

Open follow-ups: none identified.

## 2026-08-02 - Fix STFT gauge reading -9900% (missing master fix, plus stale test)

What was reported: Short Term Fuel Trim showed -9900% with STFT disabled, and moved oddly
once enabled, on protorico-econoline and reportedly every board on this branch
(`first-order-rpm-master-merge`); not reproducible on master.

Root cause: `stftCorrection` is a 1.0-centered fuel multiplier (1.0 = neutral,
`ClosedLoopFuelCellBase::getAdjustment()` returns `1.0f + m_adjustment`). TunerStudio's
scalar-channel conversion is `display = (raw + translate) * scale`. Commit `b4022c973d`
("fuel: fix STFT correction channel scaling") changed `stftCorrection`'s `translate` from
`-1.0` to `-100` based on the opposite (and incorrect) assumption `display = raw*scale +
translate`. At neutral (raw=1.0): `(1.0 + -100) * 100 = -9900` -> exactly the reported
value. Master hit and fixed the same regression same-day (`8fe687b081` introduced it,
`8f7834e77f` "fix: decouple VE Analyze from STFT display scale" corrected it) -> this
branch just hadn't merged that fix in yet.

What was done (ported/re-applied master's `8f7834e77f` onto this branch's diverged files):
- `firmware/controllers/algo/engine_state.txt`: reverted `stftCorrection`'s TS `translate`
  back to `-1.0` (scale stays 100, lo/hi stay -50/50).
- `firmware/tunerstudio/tunerstudio.template.ini`: `egoCorrectionForVeAnalyze` now reads
  `{ Gego }` (the pre-existing 100-neutral EGO correction channel already published by
  `status_loop.cpp`) instead of `{ 100 + stftCorrection1 }`, so VE Analyze/WUE Analyze no
  longer depend on the user-facing STFT gauge's display scale.
- Added `java_tools/configuration_definition/src/test/java/com/rusefi/test/VeAnalyzeCorrectionTest.java`
  (ported from master) asserting raw 0.9/1.0/1.1 display as -10/0/+10% and that
  `egoCorrectionForVeAnalyze` binds to `Gego`.
- Bumped `UiVersion.CONSOLE_VERSION` to 20260802.

Also found and fixed (unrelated, surfaced by running the full unit test suite to validate
the above): `ClosedLoopFuel.StateBasedRegionMapping` in `unit_tests/tests/test_stft.cpp` was
failing independently of this change. Commit `9bae8c75b0` ("Engine State Machine: classify
off-throttle rolling above maxIdleVss as Coasting") deliberately moved
`EngineStateMachineState::Coasting` from the overrun fuel-trim region to the idle region in
`ShortTermFuelTrim::regionForSmState()`, but the test wasn't updated to match. Updated the
test's expectation (Coasting -> `ftRegionIdle`) rather than the (intentional) production
mapping.

Validation:
- `./gradlew :config_definition:test --tests VeAnalyzeCorrectionTest` passes.
- `gen_config_board.sh config/boards/protorico-econoline protorico-econoline`: generated
  `rusefi_protorico-econoline.ini` now shows `stftCorrection1 = scalar, F32, 1612, "%",
  100.0, -1.0` and `egoCorrectionForVeAnalyze = { Gego }`.
- `unit_tests/test.sh`: full suite 1317/1317 passing after the test-file fix (was 1316/1317
  before, with the pre-existing unrelated Coasting-mapping failure).

Open follow-ups:
- This branch is a `first-order-rpm-master-merge` branch that is otherwise still missing
  whatever else has landed on master since its last merge point (`27b5263d4d`) - a proper
  `git merge origin/master` (or continued cherry-picking) is still owed, this session only
  targeted the one regression the user hit.

## 2026-08-02 - A/C idle: pressure-based adder table + RPM target -> RPM adder

What was requested: replace the flat "A/C Idle adder" % with a table vs A/C pressure, remove
the flat adder field from the Air Conditioning tab, and change "A/C Idle RPM" from an
absolute idle target into an adder on top of the normal CLT-based idle target.

Note: this reverses a deliberate design change from years ago - CHANGELOG.md #5628 says
"'acIdleRpmBump' renamed to 'acIdleRpmTarget', and changed ... from added to absolute
target". Going back to an adder is an explicit ask this session, not an oversight.

What was done:
- `firmware/integration/rusefi_config.txt`: retired `acIdleExtraOffset` (flat % adder) to
  `unusedAcIdleExtraOffset` (byte slot kept reserved, dropped from ini). Renamed
  `acIdleRpmTarget` -> `acIdleRpmAdder` (same offset/type, comment + range updated: max
  lowered from 2000 to 1000 RPM since it's now an adder, not a target). Added a new
  `AC_PRESSURE_CURVE_SIZE` (8) curve `acIdleAdderByPressureBins`/`acIdleAdderByPressure`
  (kPa/psi vs %) in the hot-tunable tuning-table area (`config->`, like `cltIdleRpm`), placed
  next to `iacCoasting`. Bumped `FLASH_DATA_VERSION` 260718 -> 260802 (new fields = layout
  change).
- `firmware/controllers/actuators/idle_thread.cpp`: `getTargetRpm()` now does
  `target = targetRpmByClt + targetRpmAc` instead of `max(targetRpmByClt, targetRpmAc)` -
  this also resolves the long-standing `FIXME: this is running as "RPM target" not "RPM
  bump"` comment on that line. Added a static `getAcIdleAdder()` helper: looks up
  `config->acIdleAdderByPressureBins/acIdleAdderByPressure` against
  `Sensor::get(SensorType::AcPressure)`; if the sensor is invalid (not wired), falls back to
  the curve's leftmost value (index 0) rather than 0, per explicit request - cars without an
  A/C pressure sensor still get a (fixed) adder instead of losing the feature entirely. Used
  at both existing flat-adder call sites (`getRunningOpenLoop`'s A/C bump, and the coasting
  A/C bump in `getOpenLoop`).
- `firmware/controllers/actuators/idle_state.txt`: live-data `targetRpmAc` comment updated
  ("Idle: Target A/C RPM" -> "Idle: A/C RPM adder"), same field/offset.
- `firmware/controllers/algo/engine_configuration.cpp`: default `acIdleRpmAdder` changed from
  900 (was a target) to 100 (an adder); added `setDefaultIdleSpeedTarget()` defaults for the
  new curve (`setLinearCurve` 0-500 kPa bins, flat 15% - matches the old flat-adder default
  magnitude) so brand-new configs aren't silently adder-less.
- `firmware/config/engines/mazda/mazda_miata_na8.cpp`,
  `firmware/config/engines/mazda/mazda_miata_vvt.cpp`: updated the two engine presets that
  set the old flat field to `setArrayValues(config->acIdleAdderByPressure, 15)` instead.
- `firmware/tunerstudio/tunerstudio.template.ini`: removed the flat "A/C Idle adder" field
  from both the "Open Loop Idle" dialog and the "A/C Settings" (Air Conditioning tab) dialog;
  renamed the RPM fields there to "A/C RPM adder" / "A/C Idle RPM adder" bound to
  `acIdleRpmAdder`. Added a new `acIdleAdderCurve` curve definition (A/C pressure vs %
  adder, dot indicator via the existing `acPressureGauge`/`AcPressure` channel).
- `firmware/tunerstudio/top_level_menu.ini`: added `acIdleAdderCurve` as a new "A/C Idle
  Adder vs A/C Pressure" entry under the "Idle" menu (gated on `ts_show_air_conditioning`,
  same as the rest of the A/C UI), following the existing pattern for standalone curve tabs
  (`cltIdleRPMCurve`, `iacCoastingCurve`) rather than embedding it as a dialog panel.
- `unit_tests/tests/test_idle_controller.cpp`: updated the two tests that set the old flat
  field (`runningFanAcBump`, `idleAdderShouldNotAffectNonIdleAreas`) to
  `setArrayValues(config->acIdleAdderByPressure, 9)` instead - these tests don't mock an A/C
  pressure sensor, so the no-sensor leftmost-value fallback exercises the same flat-9 behavior
  as before.

Validation:
- `unit_tests/test.sh` full suite: 1317/1317 passing, including `idle_v2.runningFanAcBump`
  and `idle_v2.idleAdderShouldNotAffectNonIdleAreas` (both updated to drive the new curve).
- `gen_config_board.sh config/boards/protorico-econoline protorico-econoline`: codegen
  succeeds ("Happy protorico-econoline!"); generated ini shows `unusedAcIdleExtraOffset`
  dropped from all `field =`/tooltip entries, `acIdleRpmAdder` and the new
  `acIdleAdderByPressureBins`/`acIdleAdderByPressure` curve present with correct
  offsets/ranges, and the `acIdleAdderCurve` + Idle-menu `subMenu` entry both render.
- `bin/compile.sh config/boards/protorico-econoline/meta-info.env`: full F4 cross-compile
  and link succeeds (`idle_thread.cpp`, `ac_control.cpp`, both Mazda Miata engine presets all
  compile clean against the regenerated headers); flash0 75.93% used, ram0/ram4 100% (normal
  for this board per prior sessions).

Open follow-ups:
- The new curve's default shape is a flat 15% (matching the old constant) rather than a real
  pressure-shaped curve - real tuning data would let it ramp with pressure instead of being
  flat.
- Did not audit `java_console` migration-test fixtures
  (`java_console/ui/src/test/java/com/rusefi/maintenance/migration/default_migration/test_data/*.ini`,
  `java_console/ui/src/test/resources/january.ini`) - these are frozen historical INI
  snapshots for tune-migration tests and still reference `acIdleExtraOffset`/
  `acIdleRpmTarget` by design (they represent old firmware versions), left untouched.

## 2026-08-03 - Malfunction Indicator: Key-On-Engine-Off bulb check

What was done:
- Added a page-6 `celOnKoeo` bit (`config_page_6.txt`, default off in `custom_page.cpp`):
  when enabled, the CEL output lights solid while the engine is stopped
  (Key-On-Engine-Off), mimicking the classic OBD-II bulb check, and goes off once the engine
  starts - unless an active DTC or Check Engine Triggering escalation takes over the output
  first (both existing branches in `MalfunctionIndicator`'s periodic thread run ahead of the
  new KOEO branch, so a real fault still wins).
- Along the way, removed a stale unconditional "flash the CEL for 500ms after trigger sync"
  block in `malfunction_indicator.cpp` (dead code, no config gate, and marked with its own
  `// todo: why do I not see this on a real vehicle? is this whole blinking logic not used?`
  comment) - the new KOEO bulb check replaces it with an intentional, user-configurable
  version of the same idea.
- Enabled `EFI_MALFUNCTION_INDICATOR=TRUE` in `protorico-econoline/board.mk` so this board
  can use the new field (the flag previously defaulted off there).
- Exposed the field in `tunerstudio.template.ini`'s Malfunction Indicator dialog as "Light
  at Key-On-Engine-Off (bulb check)".

Validation: `unit_tests/test.sh` full suite passes; no dedicated unit test added (the
existing `MalfunctionIndicator` class has no test harness - out of scope to add one here).

Open follow-ups: none identified.

## 2026-08-03 - protorico-econoline: enable Oil Life Monitor by default

This board has no physical oil temperature sensor, so the Oil Life Monitor's primary
temperature source is set to the estimated CLT (itself derived from CHT, see the
CLT-from-CHT entry above) rather than the default oil-temp-sensor source. Set
`getCustomPage()->oilLifeMonitorEnabled = true` and
`oilLifePrimarySource = oil_life_temp_source_e::CoolantTemp` in
`protorico_econoline_boardDefaultConfiguration()`, alongside the existing `cltFromCht`
default (both guarded `#ifndef EFI_BOOTLOADER` for the same reason as `cltFromCht`).

Open follow-ups: none identified.
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

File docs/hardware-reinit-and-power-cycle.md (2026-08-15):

# Hardware Re-init on Configuration Change, and the `requiresPowerCycle` Exceptions

rusEFI applies most configuration changes at runtime, without a reboot: when the user
presses Burn in TunerStudio, the firmware selectively stops and restarts the affected
hardware with the new settings. This document describes that mechanism and then lists
the settings that are declared as reboot-only (`requiresPowerCycle` in the TunerStudio
ini), with the code-level reason for each.

## The dynamic approach

### Two configuration images

The core idea is a diff between two copies of `engine_configuration_s`:

- `engineConfiguration` - the *new/future* configuration. TunerStudio writes land here
  immediately.
- `activeConfiguration` - the *old/current* configuration, i.e. a snapshot of what the
  hardware was last started with (`firmware/controllers/algo/engine_configuration.cpp`).

Helper macros compare the two (`firmware/controllers/algo/engine_configuration.h`):

```cpp
#define isConfigurationChanged(x) (engineConfiguration->x != activeConfiguration.x)
#define isPinOrModeChanged(pin, mode) (isConfigurationChanged(pin) || isConfigurationChanged(mode))
```

On RAM-constrained chips, `EFI_ACTIVE_CONFIGURATION_IN_FLASH` avoids the second RAM
copy: `activeConfiguration` aliases the flash image of the stored configuration, and
`isActiveConfigurationVoid` widens `isConfigurationChanged` to treat any non-zero new
value as "changed" until the first `rememberCurrentConfiguration()`.

### The Burn flow

TS Burn -> `onBurnRequest()` -> `incrementGlobalConfigurationVersion()`
(`engine_configuration.cpp`), which is the single top-level entry point for "the
configuration changed". It runs, in order:

1. `applyNewHardwareSettings()` (`firmware/hw_layer/hardware.cpp`) - see below.
2. `custom_board_OnConfigurationChange` board hook.
3. `engine->preCalculate()` - refresh derived/cached math.
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

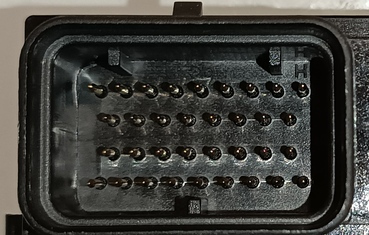
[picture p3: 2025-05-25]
firmware/config/boards/hellen/alphax-silver-revA/connectors/34pins-3k.jpg

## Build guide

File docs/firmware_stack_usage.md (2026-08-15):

<!-- Generated by .github/workflows/firmware-stack-usage.yaml from StackUsageReport output. Do not edit. See java_tools/gcc_map_reader/README.md. -->

<!-- Generated by com.rusefi.tools.stack.StackUsageReport. Do not edit. See java_tools/gcc_map_reader/README.md. -->

# Stack Usage Overview: f407-discovery

Reviewed bytes are one manually traced realistic scenario, not a root-wide maximum. The direct proxy is intentionally biased and can miss indirect or non-dominant growth; it is compared only with its snapshot, never added to the reviewed value. Interrupts and context switching are not included. Statuses remain report-only.

## Configured Stacks

| Image | Stack / entry | Nominal | Reviewed | Scenario | Proxy snapshot | Current proxy | Result |
|---|---|---:|---:|---|---:|---:|---|
| firmware | accelerometer | 400 | 184 | normal SPI sensor read | 24 | 24 | PROXY +0, PROXY BELOW REVIEWED; partial proxy: 1 indirect |
| firmware | bench test | 1600 | 148 | idle production worker | 1932 | 1852 | PROXY -80; partial proxy: 33 unknown, 6 indirect, recursion |
| firmware | CAN RX | 768 | 440 | CAN serial receive | 1244 | 1276 | REVIEW PROXY +32; partial proxy: 58 unknown, 23 indirect, recursion |
| firmware | CAN TX | 1536 | 600 | Honda-K dashboard output | 860 | 892 | REVIEW PROXY +32; partial proxy: 32 unknown, 7 indirect, recursion |
| firmware | electronic throttle | 512 | 304 | normal ETB update | 556 | 588 | REVIEW PROXY +32; partial proxy: 20 unknown, 3 indirect, recursion |
| firmware | exception/ISR | 4096 | - | - | - | - | NOT REVIEWED |
| firmware | idle | 32 | - | - | - | 0 | NOT REVIEWED: direct graph resolved |
| firmware | log flush | 400 | 124 | mailbox wait/flush | 660 | 692 | REVIEW PROXY +32; partial proxy: 25 unknown, 2 indirect, recursion |
| firmware | Lua | 4096 | - | - | - | 3212 | NOT REVIEWED: 44 unknown, 15 indirect, recursion |
| firmware | main loop | 1024 | - | - | - | 684 | NOT REVIEWED: 21 unknown, 3 indirect, recursion |
| firmware | main/process | 1536 | - | - | - | 1212 | NOT REVIEWED: 70 unknown, 24 indirect, recursion |
| firmware | MAX3185x | 400 | 192 | normal sensor read | 756 | 788 | REVIEW PROXY +32; partial proxy: 27 unknown, 2 indirect, recursion |
| firmware | SD/MMC | 1600 | 1432 | exFAT log creation | 2052 | 1852 | PROXY -200; partial proxy: 51 unknown, 19 indirect, recursion |
| firmware | software knock | 400 | 144 | normal RMS processing | 628 | 652 | REVIEW PROXY +24; partial proxy: 24 unknown, 2 indirect, recursion |
| firmware | stepper | 400 | 280 | dual H-bridge stepping | 676 | 708 | REVIEW PROXY +32; partial proxy: 25 unknown, 6 indirect, recursion |
| firmware | storage manager | 1200 | 1032 | SD extra-page burn | 660 | 692 | REVIEW PROXY +32, PROXY BELOW REVIEWED; partial proxy: 28 unknown, 5 indirect, recursion |
| firmware | timer watchdog | 256 | 104 | normal watchdog sleep | 552 | 584 | REVIEW PROXY +32; partial proxy: 20 unknown, 2 indirect, recursion |
| firmware | TunerStudio | 1200 | 824 | normal communication | 1324 | 1340 | REVIEW PROXY +16; partial proxy: 64 unknown, 33 indirect, recursion |
| firmware | USB mass storage | 256 | 240 | SD block read | 756 | 788 | REVIEW PROXY +32; partial proxy: 27 unknown, 5 indirect, recursion |
| bootloader | exception/ISR | 4096 | - | - | - | - | NOT REVIEWED |
| bootloader | idle | 32 | - | - | - | 0 | NOT REVIEWED: direct graph resolved |
| bootloader | LED | 256 | - | - | - | 80 | NOT REVIEWED: 3 unknown |
| bootloader | main/process | 2048 | - | - | - | 472 | NOT REVIEWED: 14 unknown, 3 indirect |

## Largest Post-LTO Frames

| Image | Frame bytes | Function | Source |
|---|---:|---|---|
| firmware | 688 | updateWidebandFirmwareFromFile(unsigned char) | controllers/can/rusefi_wideband.cpp:336:6 |
| firmware | 520 | f_unlink | ext/FatFS/ff.c:5087:9 |
| firmware | 424 | errorHandlerDeleteTypedReport(ErrorCookie) | controllers/core/error_handling.cpp:364:13 |
| firmware | 416 | errorHandlerIsReportExist(ErrorCookie) | controllers/core/error_handling.cpp:339:12 |
| firmware | 408 | f_mkdir | ext/FatFS/ff.c:5176:9 |
| firmware | 368 | ToothLoggerWriteCsvLine(Writer&, long long, composite_logger_s, composite_sensor_snapshot_s const&, void const*) | console/binary/tooth_logger.cpp:530:12 |
| firmware | 352 | f_open | ext/FatFS/ff.c:3799:9 |
| firmware | 344 | f_sync | ext/FatFS/ff.c:4218:9 |
| firmware | 328 | canDashboardHondaK(CanCycle) | controllers/can/can_dash_honda.cpp:46:6 |
| firmware | 272 | f_findnext | ext/FatFS/ff.c:4850:9 |
| bootloader | 256 | XcpPacketReceivedHook | ../hw_layer/openblt/hooks.c:366:32 |
| bootloader | 128 | HardFault_Handler_C | ../hw_layer/main_hardfault.c:37:6 |
| bootloader | 128 | MemManage_Handler_C | ../hw_layer/main_hardfault.c:106:6 |
| bootloader | 120 | UsageFault_Handler_C | ../hw_layer/main_hardfault.c:72:6 |
| bootloader | 56 | main | bootloader_main.cpp:192:5 |
| bootloader | 48 | ComTransmitPacket | ../ext/openblt/Target/Source/com.c:166:6 |
| bootloader | 48 | Vector14C | ../ChibiOS/os/hal/ports/STM32/LLD/OTGv1/hal_usb_lld.c:737:1 |
| bootloader | 48 | chSchGoSleepTimeoutS | ../ChibiOS/os/rt/src/chschd.c:359:7 |
| bootloader | 48 | iqReadTimeout | ../ChibiOS/os/hal/src/hal_queues.c:388:8 |
| bootloader | 48 | oqWriteTimeout | ../ChibiOS/os/hal/src/hal_queues.c:655:8 |

<!-- Generated by com.rusefi.tools.stack.StackUsageReport. Do not edit. See java_tools/gcc_map_reader/README.md. -->

# Stack Usage Overview: stm32f767_nucleo

Reviewed bytes are one manually traced realistic scenario, not a root-wide maximum. The direct proxy is intentionally biased and can miss indirect or non-dominant growth; it is compared only with its snapshot, never added to the reviewed value. Interrupts and context switching are not included. Statuses remain report-only.

## Configured Stacks

| Image | Stack / entry | Nominal | Reviewed | Scenario | Proxy snapshot | Current proxy | Result |
|---|---|---:|---:|---|---:|---:|---|
| firmware | bench test | 1600 | - | - | - | 692 | NOT REVIEWED: 20 unknown, 3 indirect, recursion |
| firmware | CAN RX | 768 | 296 | normal IOBox receive | 1212 | 1212 | PROXY +0; partial proxy: 48 unknown, 23 indirect, recursion |
| firmware | CAN TX | 1536 | 648 | Honda-K dashboard output | 836 | 836 | PROXY +0; partial proxy: 22 unknown, 7 indirect, recursion |
| firmware | electronic throttle | 512 | 256 | normal ETB update | 8 | 8 | PROXY +0, PROXY BELOW REVIEWED; partial proxy: 1 indirect |
| firmware | exception/ISR | 4096 | - | - | - | - | NOT REVIEWED |
| firmware | idle | 32 | - | - | - | 0 | NOT REVIEWED: direct graph resolved |
| firmware | log flush | 400 | 120 | mailbox wait/flush | 636 | 636 | PROXY +0; partial proxy: 17 unknown, 2 indirect, recursion |
| firmware | Lua | 4096 | - | - | - | 3196 | NOT REVIEWED: 33 unknown, 15 indirect, recursion |
| firmware | lwIP driver | 672 | 240 | normal Ethernet delivery | 804 | 804 | PROXY +0; partial proxy: 33 unknown, 6 indirect, recursion |
| firmware | lwIP TCP/IP | 1024 | - | - | - | 652 | NOT REVIEWED: 16 unknown, 5 indirect, recursion |
| firmware | main loop | 1024 | - | - | - | 628 | NOT REVIEWED: 14 unknown, 3 indirect, recursion |
| firmware | main/process | 1536 | - | - | - | 1148 | NOT REVIEWED: 53 unknown, 24 indirect, recursion |
| firmware | stepper | 400 | 220 | normal startup positioning | 652 | 652 | PROXY +0; partial proxy: 16 unknown, 6 indirect, recursion |
| firmware | storage manager | 400 | 308 | internal-flash tune burn | 628 | 628 | PROXY +0; partial proxy: 18 unknown, 5 indirect, recursion |
| firmware | timer watchdog | 256 | 112 | normal watchdog sleep | 528 | 528 | PROXY +0; partial proxy: 12 unknown, 2 indirect, recursion |
| firmware | TunerStudio | 1200 | 804 | normal tune burn | 1244 | 1260 | REVIEW PROXY +16; partial proxy: 51 unknown, 31 indirect, recursion |
| bootloader | exception/ISR | 4096 | - | - | - | - | NOT REVIEWED |
| bootloader | idle | 32 | - | - | - | 0 | NOT REVIEWED: direct graph resolved |
| bootloader | LED | 256 | - | - | - | 80 | NOT REVIEWED: 3 unknown |
| bootloader | main/process | 2048 | - | - | - | 536 | NOT REVIEWED: 21 unknown, 3 indirect |

## Largest Post-LTO Frames

| Image | Frame bytes | Function | Source |
|---|---:|---|---|
| firmware | 328 | canDashboardHondaK(CanCycle) | controllers/can/can_dash_honda.cpp:46:6 |
| firmware | 256 | Engine::periodicFastCallback() | controllers/algo/engine.cpp:599:6 |
| firmware | 248 | luaO_pushvfstring | ext/lua/lobject.c:480:13 |
| firmware | 240 | luaO_str2num | ext/lua/lobject.c:308:8 |
| firmware | 200 | luaD_rawrunprotected | ext/lua/ldo.c:135:5 |
| firmware | 192 | f_parser | ext/lua/ldo.c:999:13 |
| firmware | 192 | luaH_newkey | ext/lua/ltable.c:665:13 |
| firmware | 184 | CanWrite::PeriodicTask(long long) | controllers/can/can_tx.cpp:55:6 |
| firmware | 168 | handleShaftSignal(int, bool, long long) | controllers/trigger/trigger_central.cpp:554:6 |
| firmware | 144 | TriggerDecoderBase::printGaps(char const*, TriggerConfiguration const&, TriggerWaveform const&) | controllers/trigger/trigger_decoder.cpp:441:6 |
| bootloader | 256 | XcpPacketReceivedHook | ../hw_layer/openblt/hooks.c:366:32 |
| bootloader | 128 | HardFault_Handler_C | ../hw_layer/main_hardfault.c:37:6 |
| bootloader | 128 | MemManage_Handler_C | ../hw_layer/main_hardfault.c:106:6 |
| bootloader | 120 | UsageFault_Handler_C | ../hw_layer/main_hardfault.c:72:6 |
| bootloader | 64 | main | bootloader_main.cpp:192:5 |
| bootloader | 48 | ComTransmitPacket | ../ext/openblt/Target/Source/com.c:166:6 |
| bootloader | 48 | Vector14C | ../ChibiOS/os/hal/ports/STM32/LLD/OTGv1/hal_usb_lld.c:737:1 |
| bootloader | 48 | chSchGoSleepTimeoutS | ../ChibiOS/os/rt/src/chschd.c:359:7 |
| bootloader | 48 | iqReadTimeout | ../ChibiOS/os/hal/src/hal_queues.c:388:8 |
| bootloader | 48 | oqWriteTimeout | ../ChibiOS/os/hal/src/hal_queues.c:655:8 |

<!-- Generated by com.rusefi.tools.stack.StackUsageReport. Do not edit. See java_tools/gcc_map_reader/README.md. -->

# Stack Usage Overview: stm32h743_nucleo

Reviewed bytes are one manually traced realistic scenario, not a root-wide maximum. The direct proxy is intentionally biased and can miss indirect or non-dominant growth; it is compared only with its snapshot, never added to the reviewed value. Interrupts and context switching are not included. Statuses remain report-only.

## Configured Stacks

| Image | Stack / entry | Nominal | Reviewed | Scenario | Proxy snapshot | Current proxy | Result |
|---|---|---:|---:|---|---:|---:|---|
| firmware | bench test | 1600 | 204 | idle production worker | 2028 | 1940 | PROXY -88; partial proxy: 24 unknown, 6 indirect, recursion |
| firmware | CAN RX | 768 | 496 | CAN serial receive | 1340 | 1396 | REVIEW PROXY +56; partial proxy: 50 unknown, 23 indirect, recursion |
| firmware | CAN TX | 1536 | 1136 | Honda-K saturated output | 1024 | 1024 | PROXY +0, PROXY BELOW REVIEWED; partial proxy: 23 unknown, 7 indirect, recursion |
| firmware | electronic throttle | 512 | 312 | normal ETB update | 532 | 588 | REVIEW PROXY +56; partial proxy: 11 unknown, 3 indirect, recursion |
| firmware | exception/ISR | 4096 | - | - | - | - | NOT REVIEWED |
| firmware | idle | 32 | - | - | - | 0 | NOT REVIEWED: direct graph resolved |
| firmware | log flush | 400 | 132 | mailbox wait/flush | 644 | 700 | REVIEW PROXY +56; partial proxy: 16 unknown, 2 indirect, recursion |
| firmware | Lua | 4096 | - | - | - | 3196 | NOT REVIEWED: 34 unknown, 15 indirect, recursion |
| firmware | lwIP driver | 672 | 192 | normal Ethernet delivery | 812 | 868 | REVIEW PROXY +56; partial proxy: 33 unknown, 6 indirect, recursion |
| firmware | lwIP TCP/IP | 1024 | 584 | TCP write with ARP | 660 | 716 | REVIEW PROXY +56; partial proxy: 15 unknown, 5 indirect, recursion |
| firmware | main loop | 1024 | 208 | normal ADC processing | 620 | 676 | REVIEW PROXY +56; partial proxy: 14 unknown, 3 indirect, recursion |
| firmware | main/process | 1536 | 704 | startup fast callback | 1196 | 1236 | REVIEW PROXY +40; partial proxy: 62 unknown, 24 indirect, recursion |
| firmware | SD/MMC | 1600 | 1436 | exFAT log creation | 2036 | 1852 | PROXY -184; partial proxy: 44 unknown, 19 indirect, recursion |
| firmware | stepper | 400 | 280 | startup redundant pedal check | 652 | 708 | REVIEW PROXY +56; partial proxy: 15 unknown, 6 indirect, recursion |
| firmware | storage manager | 400 | 292 | internal-flash tune burn | 644 | 700 | REVIEW PROXY +56; partial proxy: 17 unknown, 5 indirect, recursion |
| firmware | timer watchdog | 256 | 112 | normal watchdog sleep | 528 | 584 | REVIEW PROXY +56; partial proxy: 11 unknown, 2 indirect, recursion |
| firmware | TunerStudio | 1200 | 744 | Ethernet TS with ARP | 1316 | 1388 | REVIEW PROXY +72; partial proxy: 54 unknown, 31 indirect, recursion |
| firmware | USB mass storage | 2048 | 300 | SD READ/WRITE(10) | 732 | 788 | REVIEW PROXY +56; partial proxy: 18 unknown, 5 indirect, recursion |
| bootloader | exception/ISR | 4096 | - | - | - | - | NOT REVIEWED |
| bootloader | idle | 32 | - | - | - | 0 | NOT REVIEWED: direct graph resolved |
| bootloader | LED | 256 | - | - | - | 80 | NOT REVIEWED: 3 unknown |
| bootloader | main/process | 2048 | - | - | - | 632 | NOT REVIEWED: 23 unknown, 3 indirect |

## Largest Post-LTO Frames

| Image | Frame bytes | Function | Source |
|---|---:|---|---|
| firmware | 824 | canDashboardHondaK(CanCycle) | controllers/can/can_dash_honda.cpp:46:6 |
| firmware | 744 | updateWidebandFirmwareFromFile(unsigned char) | controllers/can/rusefi_wideband.cpp:336:6 |
| firmware | 520 | f_unlink | ext/FatFS/ff.c:5087:9 |
| firmware | 424 | errorHandlerDeleteTypedReport(ErrorCookie) | controllers/core/error_handling.cpp:364:13 |
| firmware | 416 | errorHandlerIsReportExist(ErrorCookie) | controllers/core/error_handling.cpp:339:12 |
| firmware | 408 | f_mkdir | ext/FatFS/ff.c:5176:9 |
| firmware | 352 | ToothLoggerWriteCsvLine(Writer&, long long, composite_logger_s, composite_sensor_snapshot_s const&, void const*) | console/binary/tooth_logger.cpp:530:12 |
| firmware | 352 | f_open | ext/FatFS/ff.c:3799:9 |
| firmware | 344 | f_sync | ext/FatFS/ff.c:4218:9 |
| firmware | 272 | f_findnext | ext/FatFS/ff.c:4850:9 |
| bootloader | 256 | XcpPacketReceivedHook | ../hw_layer/openblt/hooks.c:366:32 |
| bootloader | 128 | HardFault_Handler_C | ../hw_layer/main_hardfault.c:37:6 |
| bootloader | 128 | MemManage_Handler_C | ../hw_layer/main_hardfault.c:106:6 |
| bootloader | 120 | UsageFault_Handler_C | ../hw_layer/main_hardfault.c:72:6 |
| bootloader | 104 | ComTransmitPacket | ../ext/openblt/Target/Source/com.c:166:6 |
| bootloader | 104 | main | bootloader_main.cpp:192:5 |
| bootloader | 48 | Vector1D4 | ../ChibiOS/os/hal/ports/STM32/LLD/OTGv1/hal_usb_lld.c:737:1 |
| bootloader | 48 | chSchGoSleepTimeoutS | ../ChibiOS/os/rt/src/chschd.c:359:7 |
| bootloader | 48 | iqReadTimeout | ../ChibiOS/os/hal/src/hal_queues.c:388:8 |
| bootloader | 48 | oqWriteTimeout | ../ChibiOS/os/hal/src/hal_queues.c:655:8 |

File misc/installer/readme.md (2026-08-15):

# Windows installers

rusEFI has a Windows Edition license for [install4j](https://www.ej-technologies.com/install4j). The current license and projects use install4j 11, not version 12.

This directory contains branded Windows installers for rusEFI bundles:

| Product | Project | Bundle input |
|---|---|---|
| rusEFI Universal | `universal/universal-updater.install4j` | `rusefi_bundle_universal/rusefi.snapshot.universal` |
| uaEFI | `uaefi/uaefi-updater.install4j` | `rusefi_bundle_uaefi/rusefi.snapshot.uaefi` |

## Scope

An installer wraps an already-built public bundle. It must not rebuild firmware or Java artifacts. Its responsibilities are:

- install the complete bundle, including firmware, INI, console, updater, drivers, and scripts;
- provide branded launchers and shortcuts;
- bundle the supported Windows JRE;
- request administrator privileges where driver installation or ECU updates require them;
- emit install4j update metadata and checksums.

## Proposed layout

Keep each product independent so identities, versions, artwork, and bundle paths cannot leak between installers:

```text
misc/installer/
  readme.md
  <product>/
    <product>-updater.install4j
    installation.properties
    <product>-16.png
    <product>-32.png
    <product>-48.png
    <product>-256.png
```

Generated EXEs, `md5sums`, `sha256sums`, and generated `updates.xml` should be ignored or published as release artifacts according to the release workflow. Do not commit downloaded bundle contents.

## Bundle input

Use a downloaded and extracted public bundle as the install4j input. Keep it outside the source tree, for example:

```text
../bundles/rusefi_bundle_<product>/rusefi.snapshot.<product>/
```

Set `allPathsRelative="true"` and use only project-relative paths in the install4j file. Do not commit developer-specific paths such as `C:/stuff/...`.

Package the extracted bundle root with one `dirEntry` instead of listing individual files. Firmware names contain changing dates and hashes, so references to a specific SREC become stale on every bundle refresh. Packaging the directory also prevents accidentally omitting drivers, INI files, or updater support files.

## Launchers

The current public console bundle places both entry points in `console/rusefi_console.jar`:

| Launcher purpose | Main class |
|---|---|
| Download fresh bundle and update ECU | `com.rusefi.autoupdate.Autoupdate` |
| Start console/update ECU | `com.rusefi.Launcher` |

Do not reference `rusefi_autoupdate.jar` unless the selected bundle actually contains it. Current bundles include the autoupdate class in `rusefi_console.jar`.

If the launcher working directory is `console`, its install4j classpath location is still relative to the installation root, for example `console/rusefi_console.jar`.

`installation.properties` can tell the console which installed launcher to use:

```properties
console-exe-file=../<Product>-Update-ECU.exe
```

## Product identity and versions

Every installer needs its own install4j `applicationId`. Never copy an ID from another product: Windows and install4j will otherwise treat both products as the same installation.

Keep the installer version monotonic. Do not reset a copied project to `1.0.0.0` if an older published installer has a higher version. Rebuilds that will be published should advance the version so update clients and Windows can distinguish them.

## Icons and console branding

Windows executable icons and the logo rendered inside the Java console are separate resources.

For Windows executables:

- start from square artwork; pad rectangular artwork instead of stretching it;
- provide explicit 16, 32, 48, and 256 pixel PNG files;
- assign all sizes to every launcher through `iconImageFiles`;
- set `useCustomIcon=true` and `customIconImageFiles` on the install4j `InstallerApplication` for the outer installer EXE;
- do not assume a file added to the directory is used - install4j assets have no effect until referenced by the project.

Setting `CreateDesktopLinkAction.winIconFile` changes only the shortcut icon. It does not brand the downloaded installer EXE. A shortcut normally inherits the target launcher's icon, so an explicit shortcut ICO is unnecessary when the launcher is configured correctly.

The Java console loads `/com/rusefi/logo.png` from `rusefi_console.jar`. Normally branding belongs in the Java build. For a one-off installer made from an unsigned public JAR, that resource can be replaced directly without rebuilding Java, but this is ephemeral: extracting a fresh bundle overwrites the modified JAR. Verify that the JAR is unsigned before modifying it.

## Build

Build from the product's installer directory with install4j 11:

```bash
/path/to/install4j11/bin/install4jc --fail-on-warning <product>-updater.install4j
```

`--fail-on-warning` is required. Missing bundle files and stale image paths are otherwise only warnings until launcher compilation or, worse, an incomplete installer is produced.

Use `--test --fail-on-warning` for a dry run. Note that install4j may still regenerate checksum/update metadata during a dry run, so inspect the worktree afterward.

## Validation

Minimum validation for each installer:

1. Validate project XML with `xmllint --noout`.
2. Run an install4j strict dry run.
3. Run the full strict build.
4. Confirm the media contains both launchers, the console JAR, firmware, INI, updater, and drivers.
5. Compare the generated EXE size and SHA-256 with `updates.xml`.
6. Inspect PE group-icon resources in the outer installer and each packaged launcher with `wrestool` and `icotool`; confirm 16/32/48/256 entries.
7. Install on Windows and test Explorer/UAC branding, both launchers, ECU update, uninstall, and Add/Remove Programs.

Windows caches icons aggressively. When validating a changed icon at the same path, rename the EXE or clear the Windows icon cache before concluding that the new resource was not embedded.

## Known working install4j XML pattern

The important pieces are shown below; IDs, names, paths, and versions must be product-specific:

```xml
<application name="Product Updater" applicationId="UNIQUE-ID" version="MONOTONIC-VERSION" allPathsRelative="true">
  <jreBundles jdkProviderId="Zulu" release="17/17.0.14" />
</application>

<entries>
  <dirEntry mountPoint="ROOT_MOUNT" file="../../relative/path/to/extracted/bundle" />
  <fileEntry mountPoint="CONSOLE_MOUNT" file="./installation.properties" />
</entries>

<iconImageFiles>
  <file path="./product-16.png" />
  <file path="./product-32.png" />
  <file path="./product-48.png" />
  <file path="./product-256.png" />
</iconImageFiles>
```

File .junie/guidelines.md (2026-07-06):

### Scope of this file

`CLAUDE.md` (at the repository root) is considered part of these guidelines — read it first. This file only adds Junie-specific guidance and frontend/Java details that are **not** already covered in `CLAUDE.md`. Do not duplicate content from `CLAUDE.md` here; if something belongs in both audiences, put it in `CLAUDE.md` and reference it from here.

See also: `CLAUDE.md`, `docs/adding-new-trigger.md`, `.junie/ts-help-topic.md`, `.junie/ts-readme.md`, `README-mcp.md`, `java_console/mcp_lua/README.md`, `firmware/controllers/lua/examples/`, [Lua-Scripting.md](https://github.com/rusefi/rusefi_documentation/blob/master/Lua-Scripting.md).

## Firmware: engine modules

When creating a new engine module (or disabling an existing one), first search the codebase for the `[tag:disable_engine_module]` comment tag and read every hit for context — the main how-to lives in `firmware/controllers/core/engine_module.h`, with the module registry in `firmware/controllers/algo/engine.h` and `long_term_fuel_trim.h`/`.cpp` as the worked example of an optional module that owns a TunerStudio page. See also the "Engine modules" bullet under Key Concepts in `CLAUDE.md`.

## Frontend (Java console)

`CLAUDE.md` focuses on the C++ firmware / unit tests / simulator. This section covers the Java side, which `CLAUDE.md` does not describe.

rusEFI console frontend application scans serial ports and well-known local TCP port 29001 to locate an engine control unit embedded device.

`PortDetectorSandbox` (`java_console/ui/src/test/java/com/rusefi/autodetect/PortDetectorSandbox.java`) is a handy manual sandbox for testing serial port auto-detection logic against real hardware. Run its `main()` to continuously poll and print detected ports and signatures.

An ECU would respond to a HELLO command with a signature String which identifies ECU kind, model and firmware version (see `BundleInfo`).

Based on that signature, UI frontend would pull an `.ini` file with all the metadata related to the exact ECU we have connected to from the internet, and cache it locally in `user.home`.

That `.ini` file would be parsed into an `IniFileModel` instance giving java code knowledge of desired calibration memory and user interface layout.

The Java side is a Gradle project with build tools and the frontend application; it's a multi-repo-like structure where some modules are located outside the current root (`java_tools`).

#### Key Module Locations:
- `:ui` is located in `../java_console/ui`
- `:shared_io` is located in `../java_console/shared_io`
- `:core_ui` is located in `../java_console/core_ui`
- `:autoupdate` is located in `../java_console/autoupdate`
- `:shared_ui` is located in `../java_console/shared_ui`
- `:ecu_io` is located in `../java_console/io`
- `:logging` is located in `../java_console/logging`
- `:logging-api` is located in `../java_console/logging-api`
- `:inifile` is located in `../java_console/inifile`
- `:models` is located in `../java_console/models`
- `:autotest` is located in `../java_console/autotest`
- `:luaformatter` is located in `../java_console/luaformatter_module`
- `:mcp_lua` is located in `../java_console/mcp_lua` — MCP server exposing rusEFI Lua tooling (set/get scripts, messages, commands) over stdio JSON-RPC. See `java_console/mcp_lua/README.md` for the exposed tools (`set_lua`, `get_lua`, `lua_reset`, `read_messages`, `wait_for_message`, …) and the typical LLM iteration loop.
- `:mcp_can` is located in `../java_console/mcp_can` — MCP server for read-only CAN bus sniffing via PCAN hardware

#### MCP servers and Lua iteration
- The `:mcp_lua` module is the recommended way for an LLM (Junie / Claude Desktop / JetBrains AI / Cursor) to iterate on Lua scripts against a real ECU: write a candidate script, `set_lua` to upload + burn + `luareset`, then `wait_for_message` / `read_messages` to observe `print(...)` / `efiPrintf` output. See `java_console/mcp_lua/README.md` for the full architecture (`LuaService` in `:ecu_io`, `MessagesCentral` listener) and gotchas (stdio transport, single ECU connection, ASCII-only `LUASCRIPT`).
- **By default target a real ECU** connected via serial port. The Win32 simulator is not reliable for MCP workflows (socket binding issues, process instability). Use serial port autodetect (omit `--port`) or pass the explicit serial port name.
- Reference Lua scripts live in `firmware/controllers/lua/examples/` (e.g. `launch_control.lua`, `CruiseCheck.lua`, `gdi4-communication.lua`, `man-in-the-middle.txt`, `DBW-controller.txt`, `dash-sweep.lua`, …). When asked to write or improve a Lua script, **start by scanning that folder** for an analogous example before drafting from scratch, then iterate via `:mcp_lua`. Read `firmware/controllers/lua/examples/readme.md` first — its "Gotchas" section covers common pitfalls (Lua-fed sensors time out unless `:set()` is refreshed every `onTick`; failing `txCan` on an unACKed bus stalls the Lua thread).
- For CAN-bus context that a Lua script might react to, the read-only `:mcp_can` PCAN sniffer can be used to capture frames first.

#### Build and Development:
- When running Gradle commands from `java_tools`, you can refer to these modules by their simple names (e.g., `:ui`, `:ecu_io`) as they are included in `settings.gradle`.
- When navigating the file system, remember that `java_console` is a sibling directory to `java_tools`.
- Source code for `:ui` is in `../java_console/ui/src/main/java`.

#### UI entry points
- see docs/frontend.md

#### TS templating:
- Pattern: `#define CAM_INPUT_1_1_NAME "Cam sensor bank 1 intake"` in `rusefi_config.txt`
- Usage: `@@CAM_INPUT_1_1_NAME@@` in `tunerstudio.template.ini`
- This pattern is used for dynamic strings in the TunerStudio UI.

#### Autoupdate:
- Logic for bypassing: Caps Lock key skips the automatic update process.
- Configuration: `autoupdate_bundle=true` in `shared_io.properties` controls the global auto-update behavior.

#### Subject domain
- Timing: In the context of engine control, "timing" usually refers to **ignition timing advance** (the angle before TDC when the spark occurs).

#### Key frontend java application classes
AbstractIoStream: Base class for communication streams that manages byte counters, activity tracking, and listener notification.

IniFileModel: The primary interface for accessing configuration data, including fields, tables, menus, and gauges parsed from the INI.

ArrayIniField: A specialized field for handling multidimensional data arrays, managing their rows, columns, offsets, and multipliers.

FieldType: Enum defining the data types (FLOAT, INT16, etc.) and their specific storage sizes and binary reading logic.

GroupMenuModel: A container used to nest multiple menu items together under a single parent group.

IniField: The abstract foundation for every configuration parameter. It defines the core identity (name) and the specific memory address (offset) where a value resides within the controller's binary image.

MenuItem: A marker interface implemented by sub-menus and groups to be part of the navigation hierarchy.

MenuModel: Represents the top-level menu structure used to build the navigation tree in the UI.

SensorCentral: The central singleton hub that tracks real-time sensor values and dispatches updates to registered listeners.

SubMenuModel: A concrete menu entry that links a display name to a specific key (like a table ID).

TableModel: A metadata container (POJO) that stores a table's configuration, such as its ID, titles, axis labels, and bin constants.

UIContext: Acts as the main application state singleton, providing access to essential components like the link manager and the INI file state.

IniFileState: Manages the current state and availability of the INI configuration model within the application lifecycle.

CalibrationDialogWidget: The UI manager that orchestrates the layout of the right-side panel, dynamically creating fields and table views.

Node: A hierarchical data structure used to store and retrieve UI configuration and layout preferences.

SensorGauge: The primary factory and logic handler for instantiating individual gauge widgets based on model definitions.

GaugeModel: Represents the technical template for a single gauge, holding its output channel, display limits, and unit labels.

TuningTableView: The core visual component for 3D table editing, managing the JTable rendering and the gradient color logic.

GaugesPanel: Manages the overall layout, rendering, and container logic for the dashboard's collection of gauges.

WellKnownGauges: Provides an enumeration of standard gauges and their associated output channel names for consistent data mapping.

BinaryProtocol: Encapsulates the logical state of the connection and handles the retrieval of the configuration image from the controller.

GaugesGrid: Manages the visual container by wrapping a JPanel with a GridLayout and handling its dimensional resets.

GaugesGridElement: Acts as a factory wrapper for individual slots, toggling between gauge and graph modes based on persistent `Node` configuration.

### Bug Fix Process
- **Mandatory separation**: When fixing a bug, you must first create and commit (or submit in a separate prompt) a reproduction test case that fails without the fix.
- Only after the reproduction test case is verified to fail, you may proceed with implementing and committing the fix.
- Verification of the fix must be done using the same reproduction test case.
- The reproduction test source file must be `git add`-ed when created (see "Source Control Hygiene" in `CLAUDE.md`).

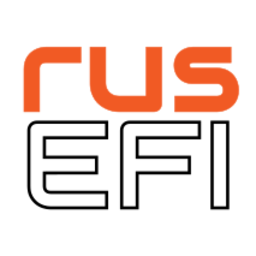
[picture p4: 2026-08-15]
misc/installer/uaefi/uaefi-256.png

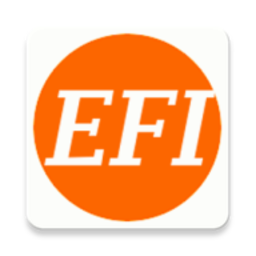
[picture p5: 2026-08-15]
misc/installer/universal/rusefi-256.png

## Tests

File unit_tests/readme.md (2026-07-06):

See https://wiki.rusefi.com/Dev-Quality-Control

TL, DR: just follow [tests](tests) folder as examples. [tests/nitrous_control](tests/nitrous_control) is a great starting point!

gcc/makefile/gtest

7. Run `./test.sh` to build and run all tests. You can also run `make -j$(nproc)` followed by `./build/rusefi_test`.
8. Execute tests on your PC/Mac, it's expected to say SUCCESS and not fail :) Googletest will also print results summary.
9. To run only one test use `./test.sh TEST_NAME` (which builds first) or ```build/rusefi_test --gtest_filter=*TEST_NAME*```.

In this folder we have rusEFI unit tests using https://github.com/google/googletest

Unit tests are not aware of ChibiOS or ARM or else, they are just plain C/C++ which you build for your desktop, not your MCU.

Note:
If you're using VSCode, we have launch tasks available to debug your tests!
see `.vscode/launch.json` "Debug Unit Tests (gdb)"

# Code Coverage

[Published CI Coverage Report](https://rusefi.com/docs/unit_tests_coverage/)

To generate coverage locally run `./run_coverage.sh` — it needs only `python3`; it creates a virtual environment in `unit_tests/venv/` and installs [gcovr](https://gcovr.com/en/stable/) into it automatically, then builds with `COVERAGE=yes`, runs all tests and writes reports to:
- `unit_tests/coverage_reports/coverage.html` (HTML)
- `unit_tests/coverage_reports/coverage.json` (JSON)

Gotcha: the build system does not detect compiler-flag changes, so objects from an earlier non-coverage build are reused without instrumentation and coverage comes out near zero (and vice versa — a coverage build slows down subsequent `./test.sh` runs). Run `make clean` whenever you switch between coverage and non-coverage builds.

CI uses a different script, `ci_gcov.sh` (invoked by `.github/workflows/build-unit-tests.yaml` after an instrumented test run), which writes `unit_tests/gcov_working_area/gcov/index.html` plus Cobertura XML and uses extra gcovr options (`--exclude-throw-branches --exclude-unreachable-branches --decisions --merge-mode-functions=separate`), so local percentages may differ slightly from the published report. Exclusion patterns shared by both scripts live in `coverage_common.sh`.

See also [https://wiki.rusefi.com/Build-Server-and-Automation](https://wiki.rusefi.com/Build-Server-and-Automation)

# Triggers Images

[Trigger images](https://wiki.rusefi.com/All-Supported-Triggers) generation is still a two-step manual process:

Step 1: Invoke unit_tests. One of the unit_tests artifacts is triggers.txt which is a snapshot of all trigger definitions.

Step 2: Once we have triggers.txt updated by unit_tests we can invoke firmware/gen_trigger_images.bat in order
to generate actual trigger images.

### Two-step TDD

We are trying to https://en.wikipedia.org/wiki/Test-driven_development

Ideal change happens as two commits:

* first we add coverage for _current_ behaviour. In case of a defect we add *green* coverage confirming defect.
* second step would be change in production code alongside of *change* in coverage.

### Testing 101

**Basic Test Setup**
```cpp
TEST(ModuleName, TestDescription) {
    EngineTestHelper eth(engine_type_e::TEST_ENGINE);

    // Your test logic here
    ASSERT_EQ(expectedValue, actualValue);
}
```

**Mocking Sensor Inputs**
```cpp
TEST(SensorModule, TestWithMockedSensor) {
    EngineTestHelper eth;

    // Mock sensor reading
    Sensor::setMockValue(SensorType::Clt, 80.0f);

    // Test logic using mocked sensor
    ASSERT_NEAR(80.0f, Sensor::get(SensorType::Clt), 0.1f);
}
```

**Testing Time-Based Functions**
```cpp
TEST(TimeModule, TestWithTimeAdvance) {
    EngineTestHelper eth;

    // Advance virtual time
    eth.moveTimeForwardUs(1000); // Advance 1ms
    eth.moveTimeForwardMs(1); // Advance 1ms

    // Test time-dependent behavior
    // ...
}
```
**Testing with Engine Module Mocks**
```cpp
TEST(ModuleInteraction, TestWithMockedModule) {
    EngineTestHelper eth(engine_type_e::TEST_ENGINE);

    MockIgnitionController ignController;

    EXPECT_CALL(ignController, getIgnState).WillRepeatedly(Return(true));

    engine->module<IgnitionController>().set(&ignController);
    EXPECT_TRUE(engine->module<IgnitionController>()->getIgnState());
}
```

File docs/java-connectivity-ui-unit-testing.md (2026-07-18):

# Java Console: Unit Test Approach for Connectivity Management & UI

Status as of 2026-07-08. Scope: `java_console` connectivity/flashing/session path
(`connectivity`, `io`, `shared_io`, `ui` modules) and the Swing UI around it.

## Why this document

The week of 2026-07-01..08 delivered a burst of connectivity features with real
brick-a-board consequences — DFU bootloader detection and in-session firmware
update (#9771), following a renumbered ECU port across OpenBLT/DFU reboots,
recovering a corrupted board with the same-session tune, and safeguards against
flashing firmware for the wrong board — followed by a deliberate testability
refactoring: the headless `connectivity` module, `ConnectivityContext`
dependency injection, the `PortScanner` and `HardwareProbes` seams, and the
first automated tests for this layer (`SerialPortScannerTest`,
`DeviceSessionManagerTest`, `ProgramSelectorTest`).

That refactoring history is recorded in `docs/java-connectivity-context-review.md`
(deleted once complete; retrievable via
`git show 148cb160d48^:docs/java-connectivity-context-review.md`). This document
is the follow-up: **how to test this layer going forward**, and a concrete
backlog ordered by how much production refactoring each test requires —
starting with tests that require none.

## The established approach

These patterns are already proven in the tree. New tests should follow them
rather than invent new machinery.

1. **Hand-written fakes, no new mocking machinery.** The project uses
   `mockito-core` (cannot mock final classes) and deliberately does *not* add
   `mockito-inline`. Seams are narrow interfaces + plain fakes:
   `FakePortScanner` (`java_console/connectivity/src/testFixtures/java/com/rusefi/FakePortScanner.java`,
   shared with `:ui` tests via `testFixtures(project(':connectivity'))`)
   implements `PortScanner` with scripted `fireHardwareChange(AvailableHardware)`
   and recorded `suspendCount`/`resumeCount`/`cachedPorts`/`invalidatedPorts`;
   `SerialPortScannerTest.FakeProbes` implements `SerialPortScanner.HardwareProbes`
   with scripted port lists, inspection results, device-probe flags and a fake
   clock. Mockito is fine for simple interface stubs (`mock(LinkManager.class)`
   in `ConnectionStatusIconTest`), but stateful collaborators get a fake.

2. **Constructor-injected seams, production wiring only at composition roots.**
   `SerialPortScanner(HardwareProbes, boolean startTimerOnFirstListener)` and
   `ConnectivityContext(PortScanner)` are the model. Production graphs are
   assembled in `ProductionConnectivity.CONTEXT` / `ConsoleUI` / `MassUpdater`;
   nothing else may reach for a singleton. When opening a new seam, copy this
   shape: extract the narrow interface the consumer actually uses, keep a
   production implementation wiring the old statics, change no call sites.

3. **Drive policy loops directly; never depend on real threads, sleeps or wall
   clock.** `SerialPortScannerTest` constructs the scanner with
   `startTimerOnFirstListener=false` and calls `findAllAvailablePorts()` per
   "cycle"; time for the device-probe throttle comes from `probes.now()`. Tests
   that need `Thread.sleep`, timing margins, or the real 300 ms `RecurringStep`
   loop are wrong — add a clock/step seam instead (see Tier 3).

4. **Resettable globals are tolerated, bounded, and reset around every test.**
   `DeviceSessionManagerTest` mutates `ConnectionStatusLogic.INSTANCE` and
   restores it in `@BeforeEach`/`@AfterEach`; `ConnectedEcuTargetTest` constructs
   a fresh `ConnectedEcuTarget` per test (the static holder was eliminated
   2026-07-08 — the process-wide instance now lives in `ConnectivityContext`,
   shared with the console `LinkManager` so `BinaryProtocol` can record the
   board at connect time) and writes `last_connected_board.txt` under the
   settings dir. This is acceptable (it serializes tests) but do not spread it —
   injecting a connection-status provider is a known later cleanup.

5. **Swing components are tested headlessly, off-screen.**
   `ConnectionStatusIconTest` (`java_console/ui/src/test/java/com/rusefi/ui/widgets/`)
   is the template:
   - instantiate the real component with mocked/fake constructor params;
   - inject state through the same channels production uses — constructor
     params, `JComponent` client properties (`bootloaderMode`, `isUpdating`),
     and the resettable `ConnectionStatusLogic.INSTANCE`;
   - assert **colors** by painting the `Icon` into a
     `BufferedImage(TYPE_INT_ARGB)` and checking pixel channel dominance
     (pure Java2D, needs no display), and **text** via `getToolTipText()` /
     title strings;
   - flush listener-driven updates with `SwingUtilities.invokeAndWait(() -> {})`.

   CI runs `./gradlew test` on `ubuntu-latest` *without* an X display
   (`xvfb-run` wraps only the TriggerImage step), so a test must never need a
   real frame/peer — off-screen painting and component getters only.

6. **`*Sandbox.java` files are manual hardware harnesses, not tests.** They have
   `main()` and no `@Test`, so `gradlew test` skips them automatically
   (`BltSwitchSandbox`, `InspectPortSandbox`, `FirmwareUpdateTabSandbox`, ~35
   more). Anything requiring a physical board or live serial port belongs there;
   automated tests must run hardware-free.

7. **Where tests live.** JUnit 5 is wired for every subproject via the root
   `build.gradle` (`allprojects` + `useJUnitPlatform()`). Pure decision logic
   tests sit next to their module (`shared_io` has `FindFileHelperTest`,
   `ConnectedEcuTargetTest`, `BoardCompatibilityTest`); the connectivity-policy
   tests (`SerialPortScanner*Test`, `DeviceSessionManagerTest`, etc.) now live in
   `connectivity/src/test`, with shared fakes such as `FakePortScanner` in
   `connectivity/src/testFixtures` so `:ui` tests can consume them too.

## Coverage today (2026-07-08)

| Area | Test | What it covers |
| --- | --- | --- |
| Scan policy | `connectivity` `SerialPortScannerTest` (13) | ttyS filtering, ECU caching vs Unknown retry, stale-node drop, unplug/replug eviction, listener-only-on-change, synthetic DFU port, device-probe throttle + last-known reuse, probe skip while connected, TCP not cached, `cachePort`/`invalidatePort`, ECU-first sort |
| Session state machine | `connectivity` `DeviceSessionManagerTest` (15) | OpenBLT/DFU detection + precedence + disappearance, initial-port pre-cache, re-cache on reconnect, CONNECTING/CONNECTED, snapshot to late subscribers, FLASHING + watchdog pause/resume + post-flash rescan choreography (`FakeJobExecutor`) |
| Flash mode/port decisions | `ui` `ProgramSelectorTest` | `mainButtonModeFor` (DFU/OpenBLT/live/offline), `resolveFlashPort` (bootloader wins, offline DFU>OpenBLT preference) |
| Tune merge recovery | `ui` `CalibrationsHelper*Test` | `decidePostMerge` all actions (#9756 crash path), partial-merge failed-field tracking, `isUiContext` |
| Firmware file targeting | `shared_io` `FindFileHelperTest` ×2 | `extractTargetFromFirmwareName`, `findXNumberOfFile` |
| Persisted board target | `shared_io` `ConnectedEcuTargetTest` | live → persisted-file → bundle fallback chain |
| Board compatibility | `shared_io` `BoardCompatibilityTest` | exact/wildcard/allowlist/QC-bypass matching |
| UI status | `ui` `ConnectionStatusIconTest` | red/green/purple priority, bootloader tooltip, offline tooltip (offline+disconnected, connected/bootloader precedence, property-change reaction), null tab pane |
| Update-available check | `ui` `MainFrameUpdateCheckTest` | `needsFirmwareUpdate` null/unparseable inputs, new-format hash compare, legacy date compare |
| Connectivity value types & helpers | `connectivity` `SerialPortCacheTest`, `AvailableHardwareTest`, `PortResultTest`, `SerialPortTypeTest`, `SerialPortScannerInspectPortsTest`, `RecurringStepTest` | cache eviction semantics, snapshot filtering/equality, PortResult identity contract, sort ranks, probe fan-out (dead port dropped, crash ⇒ Unknown), suspend-latch handshake — the Tier 1 batch, added 2026-07-08 |
| Flash brick guard | `ui` `MaintenanceUtilTest` | `confirmFirmwareMatchesBoard`: matching/case-insensitive target, unparseable name no-false-alarm, `_QC_` compatibility, mismatch declined/accepted via `UserConfirm` seam; `ensureFirmwareForConnectedTarget` unverified-declined + live-verified-skip; plus the `containsPattern` normalization (Tiers 2–3, 2026-07-08) |
| Firmware selection by board target | `shared_io` `FindFileHelperTargetSelectionTest` | newest-match wins, related-name (`_pro`) rejected, exact match beats newer foreign image, `older-fw` archive recovery, `.bin` variant, null/blank/unmatched ⇒ null; Tier 2, added 2026-07-08 |
| Device tab presentation decisions | `ui` `DevicePaneTest` | bootloader-state classification, DFU/OpenBLT guidance text (platform-aware), offline-capable tab lock list; Tier 2, added 2026-07-08 |
| Port classification pipeline | `ui` `EcuHardwareProbesInspectTest` | OpenBLT-first probing, stale-node/vanish ⇒ dropped, ECU-with/without-OpenBLT + calibrations, 3-attempt retry with between-attempts backoff, interrupt handling; Tier 3 item 1, added 2026-07-08 |
| Post-flash reconnect wait | `ui` `AbstractAutoFlashJobAwaitEcuPortTest` | `awaitEcuPort`: immediate ECU, follow renumbered port, bootloader-grace flicker vs persistent OpenBLT/DFU giveup, timeout, interrupt; Tier 3 item 3, added 2026-07-08 |
| Offline-mode UI state | `ui` `UIContextOfflineModeTest`, `TuningToolbarStateLabelTest` | `UIContext` offline flag default + setter + listener fan-out to every listener; Tuning toolbar dirty/offline label wording across all 4 offline×dirty combos (#9730, 2026-07-10) |
| OpenBLT job choreography | `ui` `OpenBltManualJobTest`, `OpenBltSwitchJobTest` | manual flash: suspend-before-flash / invalidate+resume-after (also on failure and flasher crash), restore-only-after-resume, ensure-firmware abort before touching the scanner; switch: reboot-then-`close()` ordering, never `disconnect()` (renumber-follow invariant), port released even with no `BinaryProtocol`; Tier 3 item 4, added 2026-07-10 |
| ECU-follow-across-reboot rule | `ui` `ConsoleUiEcuPortToFollowTest` | `ConsoleUI.ecuPortToFollow`: follows the single new ECU (incl. `EcuWithOpenblt`) once the old port vanished; stays put when disconnected-by-user, current port still present, never-connected, zero/multiple candidates, or candidate == current; Tier 3 item 6, added 2026-07-10 |

Not covered anywhere: `EcuHardwareProbes.inspect()`
classification/retry, `MainFrame` title composition, `StartupFrame` port-list
presentation and splash connection state machine.

The offline-tune UI glue added with #9730 (2026-07-10) is only unit-tested at
its pure edges (the two rows above). The Swing/IO-bound parts remain
sandbox/manual-only, consistent with the tiering: `PinoutPane.showOfflineBoard`
(needs the `pinouts_raw` board data + image render), `TuneManagementTab`'s
import-pair visibility gating, and the splash→offline-console frame-reuse
handoff (`StartupFrame.openOfflineConsole`, which the "not recommended" list
already excludes as splash-machine territory). If any of these regress, the
cheap seam is the same pattern used above — lift the decision (which board
signature, whether to show the import pair) out of the Swing wiring into a pure
helper and test that.

## Test backlog

Ordered by production-refactoring cost. Tier 1 items are pure additions; write
them first — they also lock in the behavior the recent bugfixes established
before further refactoring moves this code again.

### Tier 1 — no production change at all (IMPLEMENTED 2026-07-08)

Implementation notes: items 1–8 and 10 landed as the `connectivity/src/test`
suite plus `MaintenanceUtilTest` and extensions to `ProgramSelectorTest` /
`DeviceSessionManagerTest`; the missing `PortResult.hashCode` (item 3) was
added. Items 9, 11 and 12 turned out to be already covered —
`MainFrameUpdateCheckTest` covers `needsFirmwareUpdate` end to end,
`ConnectionStatusIconTest` already asserts bootloader-over-connected priority,
and `ConnectedEcuTargetTest.effectiveTarget_usesPersistedWhenNoLive` is exactly
the recovery-after-restart scenario.

Connectivity module value types and policy helpers (new tests can create
`connectivity/src/test`, or sit in `ui/src/test` next to the fakes; same
`com.rusefi` package gives package-private access):

1. **`SerialPortCache`** — `put`/`get` present-vs-absent, `retainAll` evicts
   exactly the not-retained keys, `invalidate`, overwrite of same port name.
   Currently only exercised through the scanner.
2. **`AvailableHardware`** — `getKnownPorts(type)` / `getKnownPorts(Set)`
   filtering, `isPortAvailable`, `isEmpty`, `equals`.
3. **`PortResult`** — `equals` compares only port+type (same port, different
   calibrations ⇒ equal), `isEcu()` for each `SerialPortType`. Note: custom
   `equals` with **no `hashCode` override** — a real finding to fix while
   writing the test.
4. **`SerialPortType` sort order** — assert the ordering the scanner's
   comparator relies on: OpenBlt(10) < Dfu(15) < Ecu/EcuWithOpenblt(20) <
   CAN(30) < Unknown(100).
5. **`SerialPortScanner.inspectPorts(...)` (static)** — inject a
   `Function<String, PortResult>` inspector, pass `null` probe-threads ref:
   null-returning inspector drops the port; throwing inspector yields
   `Unknown`; normal results collected. (Skip the deliberate-timeout case — it
   costs the hardwired 5 s sleep; that path needs the Tier 3 clock seam.)
6. **`RecurringStep.suspend()` latch state machine** (without `start()`):
   after `stop()` the returned latch is already at 0; before stop it is at 1
   and repeated `suspend()` returns the same latch until `resume()`.

Maintenance / flashing decision logic (`ui` and `shared_io`):

7. **`MaintenanceUtil.containsPattern`** — the `:`→`=` + whitespace
   normalization that DFU driver detection depends on:
   `"ConfigManagerErrorCode: 0"` must match pattern
   `"ConfigManagerErrorCode=0"`; plus plain substring and no-match cases.
   Package-private, zero deps, untested.
8. **`ProgramSelector.mainButtonModeFor` / `resolveFlashPort` cross-combos**
   — the corrupted-board + renumbering compounds the existing tests skip:
   offline with a stale ECU combo selection *and* a freshly appeared
   renumbered OpenBLT port ⇒ resolves to the OpenBLT port ⇒ `OPENBLT_MANUAL`;
   live connection while the combo selects a bootloader port.
9. **`MainFrame.needsFirmwareUpdate(RusEfiSignature, String)`** — already
   `static` and pure (hash/date comparison feeding the "update available" menu
   state). ~~No test exists~~ — correction: `MainFrameUpdateCheckTest` already
   covers it fully.
10. **`DeviceSessionManager` matrix rows** via existing `FakePortScanner`:
    an `EcuWithOpenblt` port that is a *real* port (not bootloader) while
    NOT_CONNECTED stays DISCONNECTED; stLink/PCAN flags alone don't change
    state.
11. **`ConnectionStatusIcon` additions** — any new color/tooltip/priority case
    uses the existing paint-to-image pattern as-is.
12. **`ConnectedEcuTarget`** — one explicit recovery-after-restart assertion:
    no live target this session (board stuck in bootloader) ⇒
    `isLiveTargetKnown()==false` while `effectiveTarget()` returns the
    persisted board.

### Tier 2 — test-fixture tricks or visibility-only changes (IMPLEMENTED 2026-07-08)

Implementation notes: item 13 landed in `MaintenanceUtilTest` (safe branches
only — the genuine-mismatch dialog still needs the Tier 3 confirm seam), item
14 as `FindFileHelperTargetSelectionTest` (a `@TempDir` input dir plus a
suite-unique target token so the real `older-fw` archive can be exercised and
cleaned safely), item 15 as `DevicePaneTest` after widening the three helpers
to package-private. The `ConnectedEcuTarget` DI migration (2026-07-08) made
item 13 simpler than described: the guard now takes the instance as a
parameter, so tests just construct one and use `setConnectedTargetForUnitTest`.

13. **`MaintenanceUtil.confirmFirmwareMatchesBoard` safe branches** — the
    brick guard added this week. Reachable today using the
    `ConnectedEcuTargetTest` recipe (construct a `ConnectedEcuTarget`, use
    `setConnectedTargetForUnitTest`, write `last_connected_board.txt`) and pass
    it with `UpdateOperationCallbacks.DUMMY`:
    matching target ⇒ true without dialog; unparseable firmware name
    (`extractTargetFromFirmwareName` ⇒ null) ⇒ true, no false alarm;
    compatible board via `BoardCompatibility` allowlist ⇒ true; no target
    known ⇒ true. Only the genuine-mismatch branch is Swing-blocked (Tier 3).
14. **`FindFileHelper.findSrecFileForTarget` / `newestMatchingTarget`** —
    `INPUT_FILES_PATH` is a mutable `public static String`; point it at a
    JUnit `@TempDir`. Scenarios: newest-by-mtime wins; a `uaefi` target must
    NOT pick a `uaefi_pro` file sitting in the same dir (file-selection layer
    of the mismatched-board guard); firmware only present in the `older-fw`
    archive is still found (foreign-download recovery); null/blank/no-match ⇒
    null.
15. **`DevicePane.bootloaderGuidance` / `isBootloaderState` /
    `isOfflineCapableTab`** — pure static helpers, currently `private`; make
    package-private and test directly (`bootloaderGuidance` branches on
    `FileLog.isWindows()`, so assert the platform-independent parts or both
    strings).

### Tier 3 — one small seam each, ranked by value

Each of these follows pattern #2: extract the narrow interface the consumer
already uses, keep a production impl wiring the old statics, change no call
sites.

1. **`EcuHardwareProbes.inspect()`** — DONE 2026-07-08. The three probes plus
   the retry backoff became the nested `PortProbe` interface (production
   `REAL_PROBE` wires the original private statics; 1-arg `inspect()` kept, no
   call sites changed). `EcuHardwareProbesInspectTest` (8 tests, scripted
   fake probe) covers: OpenBLT-first without ECU probing, stale-node ⇒ null,
   vanish-mid-detection ⇒ null, ECU with/without OpenBLT (calibrations ride
   along), found-on-third-retry, Unknown after max attempts with backoff
   between attempts only, and interrupt-during-backoff (stops retrying,
   restores the interrupt flag).
2. **`DeviceSessionManager` FLASHING state + watchdog choreography** — DONE
   2026-07-08. The nested `JobExecutor` interface (implemented by
   `SingleAsyncJobExecutor`, no call-site changes) plus constructor-injected
   watchdog pause/resume hooks (production overload wires
   `ConnectionWatchdog::pause/resume`). `DeviceSessionManagerTest` +4: job
   start ⇒ FLASHING (beats CONNECTED) + watchdog paused; job finish ⇒ scanner
   resume + forced rescan + watchdog resume + post-flash bootloader detection;
   already-running executor reports FLASHING immediately; null executor
   tolerated.
3. **`AbstractAutoFlashJob.awaitEcuPort`** — DONE 2026-07-08. Seam: nested
   `Clock` interface (`millis()` + `sleep()`); production wires `SYSTEM_CLOCK`,
   `awaitEcuPort` widened to package-private taking the clock. Test drives a
   `FakePortScanner`-backed `ConnectivityContext` whose hardware snapshot mutates
   per virtual `sleep`. `AbstractAutoFlashJobAwaitEcuPortTest` (8 tests): ECU
   already present returns without a poll; follows the ECU onto a renumbered port
   appearing after several polls (never the ghost pre-flash port); bootloader
   flicker within the 5 s grace then ECU ⇒ followed not abandoned; persistent
   OpenBLT/DFU past grace ⇒ null before timeout; nothing on the bus ⇒ null at
   timeout; interrupt mid-wait ⇒ null + interrupt flag restored; `EcuWithOpenblt`
   counts as connectable.
4. **OpenBLT job choreography** (`OpenBltManualJob` / `OpenBltSwitchJob`) — DONE
   2026-07-10. `OpenBltManualJob` grew a nested `FlashSteps` seam (ensure-firmware /
   flash / restore-calibrations; production `PRODUCTION_STEPS` wires the original
   `MaintenanceUtil` / `ProgramSelector` / `CalibrationsHelper` statics, no call
   sites changed) — the suspend/invalidate/resume choreography itself stays in
   `doJob` under test. `OpenBltSwitchJob` grew a nested `Rebooter` seam around the
   two `ProgramSelector.rebootToOpenblt` overloads. `OpenBltManualJobTest` (4,
   scripted steps record the fake scanner's state at each step) covers
   suspend-before-flash, invalidate+resume after success/failure/crash,
   restore-only-after-resume-and-only-on-success, and the ensure-firmware abort
   touching nothing. `OpenBltSwitchJobTest` (3, Mockito `InOrder` across the
   rebooter and a mocked `LinkManager`) locks reboot-before-`close()` and the
   `close()`-not-`disconnect()` invariant that keeps `isDisconnectedByUser()`
   false so reconnect can follow the renumbered port.
5. **`MainFrame.setTitle`** — extract a pure
   `composeTitle(isUpdating, bootloaderMode, connected, firmwareVersion, port,
   signature, offline, iniSignature)`; the priority ladder
   (UPDATING > BOOTLOADER > connected > OFFLINE > DISCONNECTED) is pure string
   logic currently welded to `ConsoleUI`/`FrameHelper`.
6. **`ConsoleUI` ECU-follow-across-reboot rule** — DONE 2026-07-10. Extracted
   exactly as sketched: package-private static
   `ConsoleUI.ecuPortToFollow(currentPort, commPorts, ecuPorts, disconnectedByUser)`
   returning `Optional<String>`; the scanner listener in the constructor now just
   gathers the four inputs and `ifPresent`-reconnects, and the
   not-gated-on-isConnected rationale moved to the predicate's javadoc.
   `ConsoleUiEcuPortToFollowTest` (8) covers: follows the single new ECU,
   `EcuWithOpenblt` counts as connectable; empty on disconnected-by-user,
   current-port-still-present (watchdog owns that reconnect), null current port,
   zero candidates, multiple (ambiguous) candidates, and candidate == current
   port (inconsistent scanner-vs-OS snapshot).
7. **`MaintenanceUtil` confirm seam** — DONE 2026-07-08. The nested
   `UserConfirm` interface with package-private overloads (public methods
   delegate to the `confirmOnEdt` JOptionPane production impl).
   `MaintenanceUtilTest` +5 covers the previously Swing-blocked branches:
   mismatch declined ⇒ flash blocked (message names both targets), mismatch
   explicitly accepted ⇒ proceeds, verified match never asks, unverified
   target declined ⇒ fail closed, live-verified bundle-matching target skips
   confirmation. Note: tests pick a board target outside the bundled
   `board_compatibility` allowlist to reach the mismatch branch
   deterministically.
8. **`LinkManager.restart()` gate** — the renumber-follow invariant
   (`disconnect()` blocks restart, port must be present in `getCommPorts()`).
   A `SerialPortSource` interface exists but is not injectable per instance;
   add a settable source. Cheapest immediate assertion (no seam):
   `disconnect()` then `restart()` is a no-op.
9. **`DfuFlasher` H7-vs-F4/F7 driver decision** — extract the one-line
   `isH7(effectiveTarget, is_h7Property)` predicate out of the
   Windows/process-exec method.
10. **`OpenbltDetectorStrategy`** protocol decoders — pure byte logic blocked
    on the concrete `IncomingDataBuffer`; needs a constructible/fake buffer in
    the `io` module. Moderate effort; do after the above.
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

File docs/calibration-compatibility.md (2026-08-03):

# Calibration Compatibility Guidance

When adding new calibration parameters to rusEFI, it is important to ensure that existing tunes (saved in older versions of the firmware) remain compatible and functional after a firmware update.

## The Problem
When a new parameter is added to the `engine_configuration_s` struct, it will initially have a value of 0 in existing user tunes. If 0 is not a sensible or safe default for that parameter, the engine might not start or might behave unexpectedly after an update.

## The Solution: `applyDefaultsOrFixAfterBurn()`
The `applyDefaultsOrFixAfterBurn()` function in `firmware/controllers/algo/defaults/default_base_engine.cpp` is specifically designed to handle these migrations. This function is called during startup and whenever a "burn" (save configuration) operation occurs.

### Implementation Pattern
Use the following pattern to provide a default value for a new parameter if it hasn't been initialized yet:

```cpp
if (engineConfiguration->someNewParameter == 0) {
  engineConfiguration->someNewParameter = DEFAULT_VALUE;
}
```

### Example: Engine Shutdown Period
In the codebase, you can find this example:

```cpp
if (engineConfiguration->engineShutDownPeriod == 0) {
  engineConfiguration->engineShutDownPeriod = 5;
}
```

This ensures that even if an old tune doesn't have `engineShutDownPeriod` set, it will default to 5 seconds instead of 0 (which might cause immediate shutdown or other issues).

## When to use `applyDefaultsOrFixAfterBurn()` vs `setDefaultBaseEngine()`
- **`setDefaultBaseEngine()`**: Use this to set the initial values for a *brand new* configuration (e.g., when "Reset to Defaults" is clicked).
- **`applyDefaultsOrFixAfterBurn()`**: Use this for *migration* logic. It ensures that *existing* configurations get reasonable values for newly added fields that they don't yet have values for.

## Best Practices
1. **Choose 0 carefully**: If possible, design new parameters so that 0 is a safe/neutral value. If 0 must have a specific meaning, consider if a different "uninitialized" value is needed or if `applyDefaultsOrFixAfterBurn()` migration is required.
2. **Avoid breaking changes**: If you must change the meaning of an existing field, you may need more complex migration logic in `applyDefaultsOrFixAfterBurn()` to translate old values to new ones.
3. **Validation**: Use `validateConfigOnStartUpOrBurn()` in `engine_controller.cpp` for hard errors if a configuration is truly invalid and cannot be safely fixed automatically.

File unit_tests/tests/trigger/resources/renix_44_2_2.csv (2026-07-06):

#Firmware: rusEFI v20260326@2070338890
PriLevel | SecLevel | Trigger | Sync | Coil | Injector | Time | ToothTime
Flag | Flag | Flag | Flag | Flag | Flag | ms | ms
1.0 | 0.0 | 0.0 | 0.0 | 0.0 | 0.0 | 36758.957 | 0.967
0.0 | 0.0 | 0.0 | 0.0 | 0.0 | 0.0 | 36758.957 | 0.967
1.0 | 0.0 | 0.0 | 0.0 | 0.0 | 0.0 | 36759.926 | 0.967
0.0 | 0.0 | 0.0 | 0.0 | 0.0 | 0.0 | 36759.926 | 0.967
1.0 | 0.0 | 0.0 | 0.0 | 0.0 | 0.0 | 36760.895 | 0.969
0.0 | 0.0 | 0.0 | 0.0 | 0.0 | 0.0 | 36760.895 | 0.969
1.0 | 0.0 | 0.0 | 0.0 | 0.0 | 0.0 | 36761.863 | 0.972
0.0 | 0.0 | 0.0 | 0.0 | 0.0 | 0.0 | 36761.863 | 0.972
1.0 | 0.0 | 0.0 | 0.0 | 0.0 | 0.0 | 36762.84 | 0.973
0.0 | 0.0 | 0.0 | 0.0 | 0.0 | 0.0 | 36762.84 | 0.973
1.0 | 0.0 | 0.0 | 0.0 | 0.0 | 0.0 | 36764.824 | 1.985
0.0 | 0.0 | 0.0 | 0.0 | 0.0 | 0.0 | 36764.824 | 1.985
1.0 | 0.0 | 0.0 | 1.0 | 0.0 | 0.0 | 36766.766 | 1.943
0.0 | 0.0 | 0.0 | 1.0 | 0.0 | 0.0 | 36766.766 | 1.943
1.0 | 0.0 | 0.0 | 1.0 | 0.0 | 0.0 | 36767.754 | 0.988
0.0 | 0.0 | 0.0 | 1.0 | 0.0 | 0.0 | 36767.754 | 0.988
1.0 | 0.0 | 0.0 | 1.0 | 0.0 | 0.0 | 36768.74 | 0.985
0.0 | 0.0 | 0.0 | 1.0 | 0.0 | 0.0 | 36768.74 | 0.985
1.0 | 0.0 | 0.0 | 1.0 | 0.0 | 0.0 | 36769.73 | 0.99
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

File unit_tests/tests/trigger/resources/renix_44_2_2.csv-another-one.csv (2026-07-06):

#Firmware: rusEFI v20260326@2070338890
PriLevel | SecLevel | Trigger | Sync | Coil | Injector | Time | ToothTime
Flag | Flag | Flag | Flag | Flag | Flag | ms | ms
1.0 | 0.0 | 0.0 | 1.0 | 0.0 | 0.0 | 74472.055 | 3.761
0.0 | 0.0 | 0.0 | 1.0 | 0.0 | 0.0 | 74472.055 | 3.761
1.0 | 0.0 | 0.0 | 0.0 | 0.0 | 0.0 | 74477.695 | 5.648
0.0 | 0.0 | 0.0 | 0.0 | 0.0 | 0.0 | 74477.695 | 5.648
1.0 | 0.0 | 0.0 | 0.0 | 0.0 | 0.0 | 74479.984 | 2.283
0.0 | 0.0 | 0.0 | 0.0 | 0.0 | 0.0 | 74479.984 | 2.283
1.0 | 0.0 | 0.0 | 0.0 | 0.0 | 0.0 | 74482.25 | 2.266
0.0 | 0.0 | 0.0 | 0.0 | 0.0 | 0.0 | 74482.25 | 2.266
1.0 | 0.0 | 0.0 | 0.0 | 0.0 | 0.0 | 74484.51 | 2.259
0.0 | 0.0 | 0.0 | 0.0 | 0.0 | 0.0 | 74484.51 | 2.259
1.0 | 0.0 | 0.0 | 0.0 | 0.0 | 0.0 | 74486.766 | 2.262
0.0 | 0.0 | 0.0 | 0.0 | 0.0 | 0.0 | 74486.766 | 2.262
1.0 | 0.0 | 0.0 | 0.0 | 0.0 | 0.0 | 74489.06 | 2.292
0.0 | 0.0 | 0.0 | 0.0 | 0.0 | 0.0 | 74489.06 | 2.292
1.0 | 0.0 | 0.0 | 0.0 | 0.0 | 0.0 | 74491.34 | 2.281
0.0 | 0.0 | 0.0 | 0.0 | 0.0 | 0.0 | 74491.34 | 2.281
1.0 | 0.0 | 0.0 | 0.0 | 0.0 | 0.0 | 74493.68 | 2.338
0.0 | 0.0 | 0.0 | 0.0 | 0.0 | 0.0 | 74493.68 | 2.338
1.0 | 0.0 | 0.0 | 0.0 | 0.0 | 0.0 | 74496.08 | 2.396
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

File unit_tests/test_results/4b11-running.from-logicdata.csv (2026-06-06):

Time[s] | Primary | Cam 1 | Cam 2 | Cam 3 | Cam 4 | Sync | TDC | Coils | Injectors
5.218129000000000 | 0 | 1 | 0 | 0 | 0 | 0 | 0 | 0 | 0
5.218737000000000 | 1 | 1 | 0 | 0 | 0 | 0 | 0 | 0 | 0
5.219288000000000 | 0 | 1 | 0 | 0 | 0 | 0 | 0 | 0 | 0
5.219896000000000 | 1 | 1 | 0 | 0 | 0 | 0 | 0 | 0 | 0
5.220446000000000 | 0 | 1 | 0 | 0 | 0 | 0 | 0 | 0 | 0
5.221056000000000 | 1 | 1 | 0 | 0 | 0 | 0 | 0 | 0 | 0
5.221608000000000 | 0 | 1 | 0 | 0 | 0 | 0 | 0 | 0 | 0
5.222220000000000 | 1 | 1 | 0 | 0 | 0 | 0 | 0 | 0 | 0
5.222381000000000 | 1 | 0 | 0 | 0 | 0 | 0 | 0 | 0 | 0
5.222773000000000 | 0 | 0 | 0 | 0 | 0 | 0 | 0 | 0 | 0
5.223388000000000 | 1 | 0 | 0 | 0 | 0 | 0 | 0 | 0 | 0
5.223944000000000 | 0 | 0 | 0 | 0 | 0 | 0 | 0 | 0 | 0
5.224562000000000 | 1 | 0 | 0 | 0 | 0 | 0 | 0 | 0 | 0
5.225119000000000 | 0 | 0 | 0 | 0 | 0 | 0 | 0 | 0 | 0
5.225736000000000 | 1 | 0 | 0 | 0 | 0 | 0 | 0 | 0 | 0
5.226297000000000 | 0 | 0 | 0 | 0 | 0 | 0 | 0 | 0 | 0
5.226915000000000 | 1 | 0 | 0 | 0 | 0 | 0 | 0 | 0 | 0
5.227474000000000 | 0 | 0 | 0 | 0 | 0 | 0 | 0 | 0 | 0
5.228093000000000 | 1 | 0 | 0 | 0 | 0 | 0 | 0 | 0 | 0
5.228651000000000 | 0 | 0 | 0 | 0 | 0 | 0 | 0 | 0 | 0
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

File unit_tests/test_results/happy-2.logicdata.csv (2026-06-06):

Time[s] | Channel 0 | Channel 1 | Channel 2 | Channel 3 | Channel 4 | Channel 5 | Channel 6 | Channel 7
0.000000000 | 0 | 0 | 0 | 0 | 0 | 1 | 1 | 0
0.000086500 | 1 | 0 | 0 | 0 | 0 | 1 | 1 | 0
0.000272500 | 0 | 0 | 0 | 0 | 0 | 1 | 1 | 0
0.000442000 | 1 | 0 | 0 | 0 | 0 | 1 | 1 | 0
0.000719000 | 0 | 0 | 0 | 0 | 0 | 1 | 1 | 0
0.000943000 | 1 | 0 | 0 | 0 | 0 | 1 | 1 | 0
0.001230500 | 0 | 0 | 0 | 0 | 0 | 1 | 1 | 0
0.001444000 | 1 | 0 | 0 | 0 | 0 | 1 | 1 | 0
0.001709000 | 0 | 0 | 0 | 0 | 0 | 1 | 1 | 0
0.001912000 | 1 | 0 | 0 | 0 | 0 | 1 | 1 | 0
0.001977500 | 1 | 0 | 0 | 0 | 0 | 1 | 1 | 0
0.002819500 | 0 | 0 | 0 | 0 | 0 | 1 | 1 | 0
0.002938000 | 1 | 0 | 0 | 0 | 0 | 1 | 1 | 0
0.003440000 | 0 | 0 | 0 | 0 | 0 | 1 | 1 | 0
0.003662000 | 1 | 0 | 0 | 0 | 0 | 1 | 1 | 0
0.003889500 | 0 | 0 | 0 | 0 | 0 | 1 | 1 | 0
0.004152000 | 1 | 0 | 0 | 0 | 0 | 1 | 1 | 0
0.004610000 | 0 | 0 | 0 | 0 | 0 | 1 | 1 | 0
0.004760000 | 0 | 0 | 0 | 0 | 0 | 0 | 1 | 0
0.004940500 | 0 | 0 | 0 | 0 | 0 | 0 | 0 | 0
0.008895500 | 0 | 0 | 0 | 0 | 0 | 0 | 0 | 0
0.009614500 | 0 | 0 | 0 | 0 | 0 | 0 | 0 | 0
0.011150000 | 0 | 0 | 0 | 0 | 0 | 0 | 0 | 0
0.013288000 | 0 | 0 | 0 | 0 | 0 | 0 | 0 | 0
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

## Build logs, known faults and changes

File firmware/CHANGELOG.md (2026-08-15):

<!---

How to use this file:
- When making a change to the firmware that users should know about, add it to the
	appropriate section (breaking/added/fixed) in the next release.
- If it's something interesting or breaking, make a post about it on the forum! We want users
	to find out about changes before they have to get help because their car won't start.

Release template (copy/paste this for new release):

## Month 202x Release - "Release Name"

### Breaking Changes
 -

### Added
 - MAP Prediction AE Improvements #9482
 - 1-2-3-4 firing order for 982 honda sabre 750 reverse rotation V4

### Fixed
 - wasted to sequential transition when phase is detected #9613

### Removed
 -

 -->

# Changelog

## Unreleased

## August 2026 "Day 1631"

### Added
 - Cranking Air Amount / Idle RPM Flare: add hold duration curve to lock the initial value before the Crank-to-Run taper begins
 - ETB bench test button: open throttle 300ms without sensors (#9171)
 - PWM support for fan control #5407
 - Per cylinder knock control individual gain control #9404
 - 6G75 Cam trigger support #9533
 - minimal launchTpsThreshold is required to reduce confusion
 - New firing order 1-6-2-5-3-4 (Maserati V6 and Porsche Boxster Flat-6)

### Breaking Changes
 - Dodge Neon 2003 crank actually uses crank decoder #8977
 - uaEFI PPS2 calibration #9549
 - uaefi121, super-uaefi, huge, 121vag PPS2 calibration #9551

### Fixed
 - Idle VE table when using an electronic throttle correctly uses accel pedal to match main idle logic
 - 6G75 crank Trigger fixes #8827
 - SD card access over USB is not reliable #9664
 - wmic.exe command-line utility is being completely eliminated. #9672
 - USB serial stability in some scenarios #9860
 - multispark

## February 2026 "Day 1458"

### Fixed
 - ETB: calibration, wrong scale 3% calibration error #8863
 - luaHeapAlloc crashed when not enough RAM #8874
 - uaefi121: pin 43 conflict with green LED #8884
 - super-uaefi: high side 43 conflict with green LED
 - TS: annoying numeric values after proper named values #8898
 - true/false? is that French? #8530
 - STM32: option bytes corruption when power is cut during settings save to flash #8926

### Added
 - FatFS update to R0.16
 - WBO: update from sd #8870
 - Switch to 7z for ini file compression on MSD #8895
 - stm32: flash: abort erase/write in case of undervoltage #9137
 - freedom units progress #9029

### Breaking Changes
 - CAN bitrare 666k #8784

## October 2025 "Day 1333"

### Added
 - OilTempGauge
 - LUA_USER_HEAP is no longer used
 - official binaries use gcc14
 - Jeep EVA 36-2-2 trigger pattern
 - migration to ChibiOS 21.11
 - long term fuel trim LTFT using SD card #6223
 - Add Lua hook for Launch Control request with 'setLaunchTrigger' method #7161
 - option to use Fahrenheit units #4788
 - lua editor highlighting #8413
 - lua: count dropped CAN messages #8225
 - larger LUA_canFrameCount on F7
 - native OpenBLT updater should help Mac/Linux #8495
 - firmware binaries to have detailed file names, older files go into .rusefi/older-fw folder #7830
 - predictive MAP AE Blend Duration is now a curve #8579

### Fixed
 - 3000gt 6g72 triggers cam and crank 3-0 more accuracy
 - unneeded ETB PID reset causes AE and causes AFR dip #8392
 - Torque reduction while using "Clutch Up Switch" trigger is inverted. #8447
 - TPS AE Fuel During Cranking #8500
 - migration fails in case of large diff #8524

## June 2025 "Day 1210"

### Added
 - SD card mode selection: do not wait for USB if vbatt voltage #7424
 - SD card mass storage read access performance improvements
 - migrate injector lag is now a table #7522
 - Allow fractional tachometer pulse ratio for fine tachometer calibration #7547
 - separate boost control open loop axis from closed loop axis #7580
 - verbose CAN PerCylinderKnock
 - modern Chrysler VVT cam decoder https://wiki.rusefi.com/All-Supported-Triggers#vvt
 - SD card formatting indicator
 - additional status on WBO dialog
 - default Lua tick rate changed from 10Hz to 200Hz
 - GMLAN slow single wire baud rate

### Fixed
 - map window averaging is broken since April 20th #7867
 - map window averaging does not use crank angle #7869

## February 2025 "Day 1075"

### Added
 - Flex Fuel sensor settings should be under "Fuel sensor" #7097
 - GM SENT fuel pressure sensor #6997
 - ETB calibration automatically enables ETB if needed #7197
 - Fuel Level Sensor should have a RAW option #6979
 - SD card bit data points #7227
 - stm32 build-in watchdog for F7/H7 #1339
 - improvements to SD card management #7327
 - FatFS: update to latest R0.15a version #7315
 - Honda J30 trigger wheel

### Fixed
 - Critical error when using big values on Boost Control Open Loop with Y axis as MAP #7093
 - "Baro Correction" axis label
 - unused "Throttle Up switch" is removed
 - Lua: fix heap used accumulator calculation: Do not increase if allocation failed #6924
 - Check Engine output hidden since the whole feature pretty much does not exist

### Breaking Changes
 - Lua: onCanRx parameter value to be use Lua-indexing #7110
 - After start enrichment Engine Cycles is now represented with U16 data type

## November 2024 "Day 998"

### Added
 - Support wasted spark on odd cylinder count 4-stroke engines. Improves startup and allows running without a cam sensor!
 - CLT/IAT boost duty/target compensation #6424
 - DFCO MAP condition hysteresis #6915
 - Add I-term bounds for Alternator Control #6988
 - knock fuel trim + disable suppression then deceleration #7017
 - TS runtime rate improvement

### Fixed
 - Removed questionable MAP sampling trigger index option
 - boost control load axis range and rename #6840
 - alphaNUseIat calculations are wrong #6907
 - TPS/PPS Error Detection Threshold visible twice in same dialog #6922
 - V-Twin MAP phase sense does not need to always wait for sync #6985
 - Organize sensor categories #6856
 - USB serial is sometimes lost #6595
 - fix detect cylinder for knock then wasted_spark #7062
 - Change BMW E46 CAN interval to 10 ms #6974

### Breaking Changes
- Now secondary injectors use `Secondary injector flow compensation mode` and `Secondary injector reference pressure` instead of `Injector flow compensation mode` and `Injector reference pressure` Tuner Studio settings #6972

## August 2024 "Day 898"

### Added
 - new rusEFI console tab: Knock analyzer #6467
 - Suzuki K6A (NON VVTI Trigger) #6490
 - explicit error if 32 bit java is used #6497
 - configurable Open Loop Boost vertical axis #4778
 - reduce JRE download complexity #6569
 - simpler basic firmware updater #5577
 - prohibit mcu_standby on ECU start-up #6589
 - Allow to choose lower RPM cutoff for AC Compressor #6597
 - New TPS/TPS enrichment mode: percent adder #3167
 - Launch control has a variable ignition cut BEFORE the main Hard cut #6566
 - Experimental mapExpAverageAlpha filtering #6579
 - minimum priming delay of 0.1 second
 - Launch to accept lua-based clutch and brake pedals #6658
 - Console command `set_sensor_mock` now accepts a sensor by name, instead of index. Example: `set_sensor_mock CLT 85.5`
 - STM32Cube v2.17
 - Better validation of thermistor configuration #6724
 - Full layout vs tuning layout #5154
 - Usability: turn on boost controller without ECU power cycle #6761
 - Knock frequency inputs to be bore diameter and checkbox #6767
 - Nissan HR crank trigger wheel #6773

### Fixed
 - knock logic not activated until any configuration change via TS #6462
 - VE Table have wrong units on Y-Axis #6479
 - General Purpose PWM tables have wrong names on X-axis and Y-axis #6491
 - Ignition scheduling errors after 40+ hours of uptime #6451
 - luaSoftSparkSkip/luaHardSparkSkip probably bug #6528
 - improved 4G63/4G9x cam wheel definition #6544
 - Launch RPM + Launch Control window is not correct #6533
 - MAX3185X_REFRESH_TIME is now 0.1 sec.
 - ADC array out of bounds when using analog muxes #6376
 - DFCO without a MAP sensor #6771

### Breaking Changes
 - "60/2 VW" trigger wheel renamed to "60-2 Wrong Polarity" #988
 - exhaust VVTs now use it's own Edge Select setting
 - removing weird 1+16 trigger wheel #6418
 - critical error in case of unneeded second channel #6419
 - Open Loop Boost vertical axis needs to be configured #4778
 - Cranking Cycle Multiplier is now a Map with Coolant Temp as the additional axis. #6584
 - Now we use "Alternator Voltage Target Table" instead of "Target(Volts)" setting on "Alternator Settings" area to calculate alternator voltage target. #6523
 - Now console generates current_configuration.binary_image in new format instead of current_configuration.rusefi_binary #6863

## April 2024 "Day 785"

### Added
 - Boost Open Loop gear-based modifier takes negative values #6189
 - "12 tooth crank" renamed to "12crank/24cam" #6192
 - second CAN WBO channel detailed logging #6306
 - Make sure TUNERSTUDIO IS DISCONNECTED FROM ECU #6325
 - 1_6_5_10_2_7_3_8_4_9 firing order BMW S85, also Audi 5.2 R8 and huracan GDI
 - boost duty gauge is now clamped to match actuator #6339
 - "MAP estimate table" is only available in speed density mode #6344
 - 1-8-6-2-7-3-4-5 Ferrari-Maserati F136 firing order

### Fixed
 - ETB traction control drop is affected by not-highlighted cell #5952
 - Aux Speed sensors stopped working on calibration change #6157
 - EGO renamed to O2 sensor to reduce confusion #6159
 - Disabling slow connectivity mode for now #6170
 - hellen128 better ETB pin choice between rev A/B and C
 - Base map values for Open Loop Boost Duty should be 0% #6188
 - HPFP control on cam with variable timing #6245
 - Negative timing is not displayed correctly fix #5250
 - update-ts-cacerts work-around is no longer needed #6327
 - uaEFI board knock configuration #6338
 - Fix a scenario where noisy trigger can cause overdwell #6349
 - knock retard calibration lookup #6370

### Breaking Changes
 - wrong trigger naming for missing teeth #6258
 - flipping timing_offset_cylinder direction #6095
 - clutch and flex inputs inverted options renamed #2808

## March 2024 "Day 740"

### Breaking Changes
 - Trigger Edge settings renamed from "true"/"false" to "Falling"/"Rising"

### Added
 - Allow brief operation over 100% injector duty cycle and add configurable duty cycle limits #4798
 - Staged injection support #5247
 - Ford Voodoo 1-5-4-8-3-7-2-6 firing order
 - 6/0 CKP trigger pattern for 1995 Lamborghini Diablo #5876
 - VE/Ign/Boost blend tables can select a Y axis override for even more flexibility
 - Disable radiator fans after certain vehicle speed #5875
 - LIS2DW12TR on-board Accelerometer support #4870
 - Wheel slip ratio using aux speed inputs #5897
 - 4 cylinder daihatsu cam sensor decoder #5925
 - allow inverted flex input #6131

### Fixed
 - Honda CBR 600 cam decoder #5909
 - boosted applications to log VE above 127
 - removing confusing numeric options from enumerable drop downs #5942
 - Subaru 6/7 improvement for cranking
 - Improve performance with Lua CAN reception of a high volume of frames #5841
 - odd fire timing_offset_cylinder not accounted by injection #6095
 - odd fire first spark out of order coilIndex logic in prepareCylinderIgnitionSchedule #6094

### Removed
 - Narrow to Wideband approximation

## December 2023 "Day 677"

### Breaking Changes
 - "acIdleRpmBump" renamed to "acIdleRpmTarget", and changed the way of RPM rise needed for proper A/C operation from added to absolute target #5628
 - After Cranking Enrichment changed from fixed value to table, it can help with some engines that want lots of fuel on cold, but don't run too well with big enrichment on hot #5632

### Added
 - DAC with Lua #5601
 - TunerStudio cacerts fix script #5536
 - Idle Timing Control - Soft Entry mechanism, in case of aggressive PID tuning this can help when engine enters close loop idle
 - Idle Timing Control - I factor configurable now #5635
 - Make TPS/PPS split threshold configurable #5620
 - Mitsubishi 6G72 CAM Trigger Pattern #5593
 - 3/0 trigger #5788
 - CANbus front to rear axle speed slip rate gauge on Nissan 350z and modern Hyundai/Kia #5842

### Fixed
 - Changing idle stepper settings causes kernel panic
 - Data log channel "Fuel: Injection timing SOI" indicates correct values
 - Flex sensor input
 - odd fire engines do not appreciate wasted mode on spinning #5715

## October 2023 "Day 591"

### Breaking Changes
 - Simplified VVT single tooth cam modes. "Single tooth second half" and "single tooth first half" have been replaced by simply "single tooth". This may require re-setting your trigger and VVT timing offsets if you used "single tooth first half" prior to this change.
 - "Single Tooth" renamed to "Half Moon", more proper "Single Tooth" crank trigger as a new trigger #5488

### Added
 - Latest jSerialComm 2.10.3
 - Working disconnect button in Console #4862
 - Preset for Mpxh6300 MAP sensor #5481
 - Renault F 60-2-2 trigger wheel #5513
 - AEM WBO EGO preset
 - Mitsubishi 4G69 Cam pattern #5541
 - Preset for Mazdaspeed Miata (NB) IAT sensor
 - option to Suppress start button on start up #5578

### Fixed
 - simulator: sensor mocking UI #5473
 - Custom Trigger Tooth with 1+0 causes endless loop #5471
 - nucleo-h7 bundle st-link flushing #5486
 - 2JZ cam trigger configuration is much easier to adjust #5557
 - lua reads stale output values #5579
 - High Pressure Fuel Pump scheduling goes into negative range #5596

## July 2023 Release "Day 518"

### Added
 - Dashpot for return-to-idle from coasting #5303
 - injector duty cycle limited at 50% for GDI engines #5416
 - STM32Cube v2.14 #5418
 - turning coils and injectors off in case of extremely unexpected errors #5429
 - Configurable ignition timing limits, adding safety particularly for engines running wasted spark with a large cam FOME#211

### Fixed
 - fuel_pump_control is accessible as getOutput("isFuelPumpOn") in Lua #5239
 - start button logic does not crank started for first X seconds since ECU boot #5324
 - launch control: Speed threshold should not depend on launch mode, also zero speed limit handling #5419
 - hard fault due to misaligned big buffer on F7 firmware #5354
 - Pointing at https://adoptium.net/download/ as JRE source

### Breaking Changes
 - Always operate in "two wire" mode for batch fuel, fixing batch firing order #5353
 - rusEFI console requires java 11

## June 2023 Release "Day 466"

### Breaking Changes
 - LCD & joystick support removed
 - CJ125 support removed
 - Single value to be used in event of a failed MAP removed, fallback table is the only option now

### Added
 - Detected gear and wastegate position to CAN format
 - Pause closed loop fuel after cuts
 - More trigger UI tweaks
 - Lua memory leak detection and prevention
 - Support gauge fuel pressure sensors
 - Better idle VE table transition
 - Detected gear available as gppwm channel
 - Y axis override for Idle VE table. Helps with idle quality on ITB setups.
 - Blend tables for boost open and closed loop control
 - Boost Cut Pressure Hysteresis #4529
 - Enable knock sensing on F407 Discovery build, hardcoded to PA3 #5254

## April 2023 Release - "Day 419"

### Added
 - Rearrange & simplify trigger configuration UI #5077
 - Selectable CanBus channel for WBO inputs #5028
 - STM32Cube v2.13 #5135
 - Native (modern, fancy, digital) SENT TPS input #5079
 - Allow k-line as a runtime option on default build
 - microRusEFI: Indicator for injector hardware issues #5189

### Breaking Changes
 - rusefi_default_bundle.zip was replaced by rusefi_bundle_f407-discovery.zip #5078

### Fixed
 - Antilag switch pin mode was ignored #5036
 - 50/83.3/125kbit CAN #5072
 - console creates new log file every 100 ms #5112
 - CAN bus AFR value inverted #5160
 - Subaru EZ30 tdcPosition is now 240
 - ETB control improvements hellen boards #5196
 - Require either analog AFR or CAN AFR input not both #5226
 - Ignition Knock response logging progress
 - sensor checker is not checking sensors #5232

## February 2023 Release - "Day 346"

### Breaking Changes
 - Change ignition IAT correction table to use IAT/load #4948

### Added
 - Electronic throttle supply voltage compensation, giving more consistent behavior as battery voltage changes #4838
 - VR trigger input oscilloscope for boards with "discrete VR" hardware (AlphaX ECUs, some Hellen) [#4885](https://github.com/rusefi/rusefi/issues/4885)
 - Jammed ETB detection #4873
 - RPM correction/multiplier for Accel Enrich #4760
 - Tooth logger writes to SD card #4897
 - Antilag #2403
 - Lua 'setIgnDisabled' function for all kinds of cranking safety systems
 - STM32Cube v2.12
 - detect and ignore doubled trigger edges #4656
 - Additional fuel and timing correction gauges in Tunerstudio #4955
 - Default bundle no longer initializes UART TTL connectivity by default #4998

### Fixed
 - multi-line tooltips in TS #4927
 - Negative temperature values for IAT Corr table #4941
 - DC wastegate #4965
 - [LSE] RTC (SD log dates) #4556

## December 2022 Release - "Day 289"

### Breaking Changes
 - SD logging rate is now set with hz instead of ms period #4553

### Added
 - VVT minimum RPM setting #4545
 - Fuel/spark cut codes to TS indicators #4592
 - Flexible ignition and VE adder/trim tables #4586 #4640
 - Enforce board configuration overrides more strictly #4614
 - rusEFI console Startup Frame should scan for available hardware #4633
 - Don't fire the engine without the ignition on (avoids USB keeping engine alive after ignition off) #4474
 - Lua: function to access VIN setting #3967
 - Lua: designated Lua gauges with logging #4672
 - GCC11 is the suggested compiler now, GCC9 no longer supported #4680
 - Add fuel adder to launch #4777
 - 3-cylinder Benelli trigger
 - ETB intermittent sensors protection #4832
 - ETB output average and rate of change gauges #4833
 - Alternator Duty Cycle Adder for AC Fan #4973

### Fixed
 - Fuel Priming reset fix #4627
 - Slower than expected RPM information was slowing engine start #4629
 - Fix 36-2-1 trigger (Mitsubishi 4B11, etc) #4635
 - Improve injection phase table defaults #4808

### Removed
 - Idle timing deadzone #4729
 - "Use only rising edge" trigger option - triggers now select automatically based on trigger type #4621

## September 2022 Release - "Day 203"

### Added
 - Time delay before DFCO #4292
 - Idle coasting position table is now RPM-based, instead of CLT-based #4487
 - Manual electronic throttle synchronization #3680
 - Delay before enabling AC compressor #4502
 - Require full sync for odd cylinder count #4533
 - Hysteresis on some fuel cuts to avoid engine damage #4541
 - Engine Sniffer into TS data logs #4535

### Fixed
 - Inverted vvt control #4464
 - Lua canRxAdd bus parameter handling #4467
 - STM32Bootloader driver install from console requests elevation #4313
 - VQ trigger gaps improvement #4469
 - Injection Offset for skipped wheel triggers #4536
 - Randomly hanging for a complete second #4557

### Removed
 - Alternator on/off mode #4548

## August 2022 Release - "Day 170"

### Added
 - raw voltage gauges for Lua script aux analog inputs #4346
 - microRusEFI and Proteus F4 have CAN OpenBLT bootloader #4199 #4230
 - counter-noise measure for custom skipped trigger wheels #4375
 - Write hard faults to backup ram, print on next boot #4324
 - Many more options for Lua CAN rx filters/callbacks #4387
 - Password protection against tune access #4243
 - Additional CAN messages #4401
 - Option to invert VVT control (exhaust cams, etc) #4424
 - Raw Battery gauge
 - More accurate/stable VVT angle calculation #4433

### Fixed
 - Lua CAN reception fixed for 11-bit IDs where the frame would be received, but a corrupt ID was passed to the handler function. #4321
 - Many drop downs menues are now sorted #4339
 - rusEFI TS plugin launcher fixed
 - Console autoupdate error dialogs #4352
 - custom skipped wheel could be located on camshaft #4377
 - it's impossible to receive AcceleratorPedal sensor via CAN/Lua #4369
 - MRE stepper disables LS2 control #4381
 - VVT target tables allow negative values #4424

### Removed
 - ICU trigger input logic since it is unused in any current ECU #639
 - Idle PID "offset" field, as this role is filled more effectively by the various open loop parameters.

## July 2022 Release - "Day 130"

### Added
 - verbose trigger sync should reuse engineSnifferRpmThreshold #4259
 - Subaru EZ30 variation of 36/2/2/2 trigger
 - Linux version of rusEFI simulator SocketCAN integration (#4312)

### Fixed
 - Improved logic used to disambiguate trigger sync using cam/VVT information. Engine now runs in wasted spark until cam sync is achieved, at which point it switches to fully sequential. #4099
 - visiting "live data" tab causes fatal error on ECU #4271
 - SD card logs are broken by double fuel: wall correction #4291
 - RPM-related tune fields can now hold larger values for higher rev limits, etc #4298

## June 2022 Release - "Day 98"

### Added
 - FasterEngineSpinUp should be enabled by default #4094
 - ETB low limit is now configurable #4119
 - Advanced Trigger option: require engine phase synchronization in sequential mode #4151
 - Maintainability: frequency sensors need a simple event counter in the logs #4173
 - TS bench test commands are now configurable #4192
 - microRusEFI can now use more pins for Cam position sensor #3032
 - hard requirement for console version match #4187

### Fixed
 - Make 36-2 trigger sync parameters more generous #4132
 - Synchronized Phase handling fixes #4099

### Removed
 - Various Honda 24/4/1 trigger modes (that didn't work very well), replaced with "12 tooth crank" mode.

## April 2022 Release - "Day 58"

All notable user-facing or behavior-altering changes will be documented in this file.

### Fixed
 - An attempt to make 'Trigger' dialog a bit less confusing #4021
 - Fixed knock threshold table, improved knock sensing status gauges

### Added
 - Mitsubishi 36-2-1-1 trigger wheel
 - Mitsubishi 3A92 VVT trigger
 - Toyota 4-1 VVT trigger
 - use extra RAM for lua if your microRusEFI unit has stm32f42x microcontroller
 - VVT activation delay #3443
 - Allow setting injection phase by start or center of injection #4068
 - New 'View' menu in TunerStudio showing a lot of live data points #3614

## March 2022 Release - "Day 22"

### Added
 - Use board-specific output and digital input pin names in error messages #3886
 - Support LPS22 in addition to LPS25 baro sensors #3900
 - Proteus F7 flashing work-around

### Fixed
 - SD card logging with SDIO hardware #3873
 - rusEFI console stability improvement #3912
 - console updater does not work if folder name contains spaces #3927
 - SD card logs PPS as TPS #3943

## Removed
 - Miata NB1 trigger was merged with Miata NB2 trigger
 - FSIO

## January 2022 Release - "Green Juice"

### Added
 - Per-cylinder fuel trim tables
 - Per-cylinder ignition timing trim tables
 - SDRAM reference binary for stm32f429-discovery

### Fixed
 - rusefi_Console: Too long re-connection time #3305
 - Bosch Quick Start on B6 Passat is confused about phase #3812

## December 2021 Release - "Cookie Exchange"

### Added
 - Improved vehicle speed sensor configuration: now uses real physical constants about tires, gear ratio, sensor, etc.
 - Improved priming logic. Now includes a table of priming fuel mass vs. engine temperature, in addition to a delay before priming to allow fuel pressure to build. #3674
 - ISO-TP connector in firmware & ISO-TP to TCP/IP bridge in rusEFI console #3667
 - Lua: mcu_stop method for stm32 F4 and F7

### Fixed
 - Faster engine sync + startup on engines with crank-speed primary trigger

### Added
 - Lua 'Format' button

## November 2021 Release - "Loosen Up Lighten Up Day"

### Added
 - Higher Data Rate with TS 3.1.06.14 Beta or newer
 - turbo speed sensor #2935
 - A TON of Lua progress
 - Overall performance
 - Knock retard #3396

### Fixed
 - A/C control bugfix
 - Better Windows build-in DFU #3338
 - Proteus now waits for VBatt to enable main relay output

## Removed
 - Remove engine load acceleration enrichment #3357
 - FSIO removed from user interface #2928

## October 2021 Release - "Pierogi Day"

### Added
 - Ford PIP trigger decoder https://wiki.rusefi.com/Images/triggers/trigger_65.png
 - Dwell battery voltage correction table
 - rusEFI firmware feature should be honest about it's Windows-only limitation
 - Bosch MM5.10 accelerometer integration
 - CLT/IAT sensor calibration presets

### Fixed
 - Fix of 36/2/2/2 attributes to help rotary #3242
 - SD card doesn't work on H7
 - rusEFI console to validate current bundle against bundle already in ECU #3266
 - GPPWM usability: notes field #3270
 - overdwell protection #3220

## September 2021 Release - "Iguana Awareness Day"

### Added
 - RUSEFI MSD now contains bundle-specific URL #2848
 - Nissan 4 cylinder QR trigger wheel #3118
 - 1-6-2-4-3-5 firing order for all our 911 fans!
 - Add minimum MAP threshold for closed-loop boost control
 - rusEFI console Lua tab loads scripts from ECU on start

### Fixed
 - Composite Logger uses same engineSnifferRpmThreshold setting as engine sniffer #3161

## Removed
 -  TS file read feature #3004

## July 2021 Release "Ice Cream Day"

### Breaking Changes
 - vvtOffset field migrated to four vvtOffsets fields. Anyone using VVT would need to manually adjust their configuration.

### Added
 - Injector nonlinearity (small pulse) correction - so far just polynomial, but table modes coming soon.
 - 1-4-3-6-2-5 firing order for VAG v6
 - vq30de trigger wheel decoder #2974
 - new hardware testing console commands #2978

### Fixed
 - rusEFI console start-up speed #2964
 - wrong handling of symmetrical crank wheels NB2 VQ35 Renix #2980

## June 2021 Release "National Logistics Day"

### Fixed
 - Improved cranking defaults
 - Simplified/clarified idle and cranking TunerStudio pages
 - Minor change of Miata NA trigger shape #2855
 - Improved trigger sync for 60/2 36/1 36/22 triggers as part of VW warnings on cranking part #1 #2861

### Added
 - Idle improvements! Open loop corrections are now applied in closed loop mode.
 - Electronic throttle rev limiter: close the throttle before hitting hard limit, OEM style.
 - "inhibit start until oil pressure" prevents starting the engine with no/low oil pressure #2799
 - Dual cooling fans, with new "enable fan with AC" option
 - Lua scripting: implement custom ECU behavior with a Lua script. https://wiki.rusefi.com/Lua-Scripting

# 2021 May "Piercing Day"
### Fixed
 - LCD screen works again #2576
 - Support STM32F7 1MB devices
### Added
 - Per-bank closed loop fuel correction (each cylinder corrected by the sensor that sees its exhaust)

## April 2021 Release - "Malbec"
### Added
 - mount SD card and drive containing TunerStudio ini at the same time
 - VAG MQB tachometer CAN integration
### Fixed
 - fix error/warning buffer overflow #2456
 - engine sniffer "show only interesting" fix #2528
 - SD card logs bugfix #2556
 - Too many small logs are zero size #2553
 - Launcher splash screen is freezy #2560
 - NB2 trigger decoder #2533

## April 2021 Release "Be Kind to Lawyers Day"
### Added
 - mount SD card and drive containing TunerStudio ini at the same time
### Fixed
 - engine sniffer "show only interesting" fix #2528

## Potato Chip Day 2021 Release

### Added
 - VAG MQB tachometer CAN integration

### Fixed
 - fix error/warning buffer overflow #2456

## Life in the Cracks 2021 Release

### Added
 - USB Mass Storage: The connected SD card will be mounted over USB if rusEFI connected to a PC via USB.
 - GM 60/2/2/2 trigger https://wiki.rusefi.com/All-Supported-Triggers#gm
 - TriTach trigger https://wiki.rusefi.com/All-Supported-Triggers#tritach
 - Skoda Favorit trigger https://wiki.rusefi.com/All-Supported-Triggers#skoda-favorit
 - Add fallback logic handling failed MAP sensor.  In case of failed MAP, ses either a fixed MAP value, or a table that estimates MAP based on TPS and RPM.
 - STM32H7 is mostly working

### Fixed
 - Improved fuel/ignition bench testing precision - now accurate to ~1 microsecond #2440
 - Fix internal MCU temperature sensing on STM32F7-based ECUs #2392

### Breaking Changes
 - VVT target is now taken from VVT not FSIO table #2243

### 2021 Printing Ink Day

### Breaking Changes
 - Closed loop idle timing behavior changed to no longer fall off control as entering/leaving the idle region. It now sharply engages/disengages upon entering/leaving the idle area.
 - Idle phase logic uses the same idle detection thresholds as the main idle controller instead of its own thresholds.

### Added
 - Main Relay bench test button

### Fixed

### 2021 Orthodox Christmas Day

### Breaking Changes

### Added
 - Second wideband O2 processing as channels "Lambda 2" and "Air/Fuel Ratio 2".  Currently only supports CAN sensors, but analog will be supported too soon.
 - Basic fueling-only flex fuel implementation. Automatic adjustment of stoichiometric ratio based on ethanol content, compatible with the common GM/Continental 50-150hz flex fuel sensor 🎉 🎉 🎉

### Fixed
 - Simplify idle control dialog in TunerStudio
 - microRusEFI outputs are in trouble on configuration change
 - CLT gauge no longer erroneously shows "deg F" by default.

### December 2020 Bake Cookies Day

### Breaking Changes
 - GM x24 trigger now uses 0 offset (offset is now built in, previously needed 50 degrees offset)

### Added
 - DAIHATSU 3/4 cylinder trigger https://rusefi.com/images/triggers/trigger_6.png
 - Ford ST170 VVT cam trigger https://rusefi.com/images/triggers/trigger_42.png
 - Changed scheduling timer driver to improve scheduling accuracy #1983

### Fixed
 - microRusEFI GP3 & GP4 fixed

## December 2020 National Mutt Day

### Fixed
 -  minor bugfix - engine sniffer missing pin names #1995

## November 2020 Release - "Black Friday"

### Breaking Changes
 -   "AFR target" table is now "Lambda target" table.  It should convert itself correctly, but a backup of that table is recommended when updating firmware/ini.
 -   "Base cranking fuel" is now in milligrams, using the full injector model at all times now.  60mg per liter per cylinder is a good starting point

### Added
 -   High & low pressure fuel sensor channels
 -   Electronic throttle-style wastegate control found on some VW turbos (and VGTs)
 -   Improved TLE8888 driver on microRusEFI
 -   Improved setting ECU presets/defaults from TunerStudio

### Fixed
 -   Improved TunerStudio protocol reliability - should see fewer CRC errors now #1943

## October 2020 Release - "Sausage Pizza Day"

### Added
 -   `iat` as FSIO variable to read intake air temperature
 -   [ALPHA] Software based knock detection on Proteus v0.4+.  Possible on microRusEFI and Frankenso too with hardware modification.
 -   [ALPHA] Early framing work for automatic transmission control!

### Fixed
 -   Fixed fuel pump logic
 -   Improve trigger input/decode and PWM performance
 -   Fixes to SD card logging

# Old Changelog

| Release date  | Revision  | Details |
| ---  | --- | --- |
| 07/26/2020 | r24635 | improvement #1637: DC motor idle air valve for late 90s German vehicles |
| 07/21/2020 | | bugfix #1592 injectors could stay open on transition from cranking to running under certain conditions |
| 06/17/2020 | r23656 | bugfix #1491 major performance/scheduling improvement |
| 05/21/2020 | r22961 | rusEFI console start-up time improvements |
| 04/18/2020 | r22231 | Renix 44-2-2 trigger support added |
| 04/02/2020 | | Start button feature |
| 03/28/2020 | | Critical error text is now displayed in TunerStudio |
| 03/26/2020 | | Multi-spark feature |
| 09/05/2019 | r19849 | Electronic Throttle Body including idle control seems to work |
| 07/28/2019 | r19612 | improvement #809: software jump to DFU |
| 04/25/2019 | r17317 | bugfix #775: electrical noise reboot during settings change causes with full tune loss |
| 04/07/2019 | r17098 | improvement #714: TLE8888 Enable Outputs SPI integration |
| 02/27/2019 | r16886 | bugfix #698: concurrency defect with single timer executor initialization |
| 02/23/2019 | r16857 | improvement #688: better support for 144 and 176 pin packages |
| 02/05/2019 | r16713 | improvement #631: ChibiOS 18 |
| 01/11/2019 | r16346 | bugfix #663: SPI fixes for CJ125 for stm32 errata STM32f405/7/15/17 |
| 12/09/2018 | r16057 | electronic throttle body control is now BETA version |
| 08/19/2018 | r15811 | bugfix #604: no interpolation outside of the table |
| 01/29/2018 | r15514 | improvement #215: CJ125 wideband controller |
| 01/23/2018 | r15442 | improvement #463: ChibiOS 17 / 4 |
| 01/07/2018 | r14952 | usability & minor bugfix #532 idle defaults are broken |
| 12/17/2017 | r14892 | bugfix #513: console: erase on older chips does not work |
| 11/26/2017 | r14789 | bugfix #500: set_rpn_expression command is broken |
| 11/23/2017 | r14779 | bugfix #497: engine does not start with SD card |
| 11/19/2017 | r14766 | improvement #496: console flasher to support older boards |
| 11/19/2017 | r14760 | improvement #495: incompatible change - larger settings area |
| 11/06/2017 | r14733 | improvement #487: single-point injection mode |
| 10/26/2017 | r14700 | improvement #385: narrow band to wide band conversion table |
| 08/31/2017 | | improvement #442: ADC_VCC should be configurable |
| 07/24/2017 | r14513 | bugfix #307: TS bench test blinks three times |
| 07/13/2017 | r14476 | bugfix #461: SAXParserException on console start-up due to damaged settings.xml file |
| 07/09/2017 | r14473 | improvement: IAC solenoid frequency changeable on the fly |
| 06/19/2017 | r14393 | bugfix: pinMode, milMode |
| 05/27/2017 | r14221 | improvement: ochGetCommand to support offset and count |
| 05/05/2017 | r13974 | bugfix #404: 36/1 FATAL error: angle range trgSync |
| 05/03/2017 | r13967 | improvement: ChibiOS 3.2 |
| 04/06/2017 | r13759 | major improvement #72: ChibiOS 3.1 |
| 03/26/2017 | r13330 | super annoying bug #336 fixed |
| 03/20/2017 | r13233 | improvements #375 & #376: hard FPU mode & migrating to fresh version of arm gcc |
| 03/19/2017 | r13223 | bugfix #374: persistent configuration starts to touch firmware - settings would need to be reloaded |
| 03/09/2017 | r13146 | bugfix #370: duty cycle vs error code 6050 |
| 03/06/2017 | r13123 | bugfix #363: 2/1 skipped wheel is a corner-case |
| 03/05/2017 | r13108 | bugfix #363: trigger front only processing |
| 02/22/2017 | r12980 | bugfix: false error message in case of single coil or simultaneous injection |
| 02/22/2017 | r12973 | unused property 'custom Use Rise Edge' removed |
| 02/22/2017 | r12972 | protocol signature changed to 'v0.02' (this would happen from time to time to ensure version match between console and TS project |
| 02/20/2017 | r12939 | https://github.com/rusefi/rusefi is now the official primary repository |
| 02/18/2017 | r11565 | improvement: level1 default brown out https://sourceforge.net/p/rusefi/tickets/354/ |
| 02/18/2017 | r11554 | bugfix: rusEfi console program/erase buttons fixed with ST-LINK 2.1 |
| 12/09/2016 | r10991 | bugfixes, bugfixes, bugfixes & release 1.0
| 02/15/2016	| r9600 | automatic warm-up fuel correction, performance improvements
| 08/31/2015	| r8725 | acceleration fuel correction, console improvements
| 07/06/2015	| r8554 | more CAN, better console, bugfixes, performance
| 04/26/2015	| r7938	 | vehicle speed sensor, stepper idle valve, lots of improvements
| 11/13/2014	| r5327	 | ChibiOS/RT 2.6.6, better cold start logic, bugfixes, bugfixes, bugfixes...
| 06/12/2014	| r3477	 | Precise event scheduling, protocol selection
| 03/26/2014	| r2413	 | C++, refactoring & improvements
| 02/23/2013	| r1777	 | trigger is now configurable via TunerStudio
| 01/30/2014	| r1309	 | true trigger angles, VBatt signal
| 01/12/2014	| r1007	 | refactoring, refactoring & refactoring
| 12/19/2013	| r605	 | ignition control & a little bit of CAN bus
| 11/08/2013	| r100	 | Tuner Studio fuel map tuning, fuel pump control
| 10/14/2013	| r39	 | USB serial bug, missing IAR files, self-contained Makefile
| 10/13/2013	| r33	 | IAR project file
| 10/04/2013	| r26	 | Patched ChibiOS/RT 2.6.1 sources are now included
| 09/23/2013	| r20	 | Tuner Studio integration, configuration persistence
| 08/30/2013	| r14	 | initial documentation & refactoring. tunerstudio integration
| 08/03/2013	| r13	 | wideband O2 input, better idling algorithm, serial-over-USB
| 07/05/2013	| r10	 | Second CKP, sequential injection.
| 06/19/2013	| r9	 | Initial version - batch injection & ignition with advance table lookup.

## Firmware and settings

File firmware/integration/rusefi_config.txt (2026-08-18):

! This file defines the format of rusEFI persistent configuration structure
! This file is processed by ../java_tools/configuration_definition java toolset
!
! for runtime data points meta info see LiveData.yaml
!
! Comments start with '!'
!
! The format is unique to rusEFI
!
! This file is used in combination with tunerstudio/tunerstudio.template.ini to generate the .ini files used by turner TunerStudio.
! The easiest way to find a specific variable within this config is to search within tunerstudio.template.ini for the on screen text from tuner studio
! this should provide the actual variable name, for example searching for "Number of Cylinders" will provide the variable "cylindersCount".
! Then you can search for "cylindersCount" in this file to find the definition.
!
! This file consists of two parts:
! The first part is engine_configuration_s area, followed by a few tuning tables.
!
! The only difference here is that engine_configuration_s area does not support hot modification while tuning tables can
! be modified without burning changes.
!
! See also tunerstudio/readme.md
!
! # Adding new fields
!
! The most important thing to note when adding fields is that if you change the offset
! of any other fields, users will have their configs scrambled when they update their firmware.
! As a result, this file is an organism that must be handled carefully.
!
! You may notice that there isn't much organization to this file with fields in amongst unrelated fields.
! That's OK, it's just a result of things being removed and new things being put in their places, and new
! things only being able to be added at the end of the structure or where other things were removed previously.
! TODO: technically we can clean this every once in a while and maybe we should
!
!
! Rename or substitute the field with any new fields that total to the same size.
!
! At this point it's a good idea to save your changes in version control, i.e. with `git commit`,
!	so that you can roll back to the current state after you generate the config files.
! This is important because we do not include the generated files in pull requests.
! We have a Github Actions workflow that generates all the files automatically after
! the pull request has been merged.
! Invoke gen_config.sh to generate .h and .ini files.
! Now check the `git diff` to make sure you haven't accidentally changed the offsets of
! any other fields.
! If you did, reset your version control state to your commit, i.e. with `git stash`,
! and fix the fields you created to make sure that they total the same size.
!
!
! each field is declared as
! type name;comment;"units",scale,offset,min,max,number_of_digits
! hello;I like rusEFI;"ms",1,0,-10,10,2
!
! you want to use "SPECIAL_CASE_TEMPERATURE" as units for temperature fields
! "SPECIAL_CASE_PRESSURE" for pressure fields
! "SPECIAL_CASE_SPEED" for speed fields
! so we can auto-generate the TS conditional on the final ini, all the special_case fields should be treated as metrics units in the code,
! they wel be represented on imperial units only on the TS interface
!
! Q: what's the difference between 'engineConfiguration' and rest of the 'persistent_config_s'?
! A: 'engineConfiguration' portion has 'activeConfiguration' copy so that we can detect changes
! A number of systems like IO and trigger do not like to be re-initialized while engine is running, these are great candidates
! for engineConfiguration
! on the other hand VE table changes are much easier to make on the fly with engine running
! todo: move all curves and tables out of engineConfiguration that would make 'activeConfiguration' smaller and we might save a couple of K of ram
!
!
!
! Q: What is "@OFFSET@"?
! A: That's a template placeholder for field offset within the resulting data structure.
!
! Q: What is "[0:2]"?
! A: That part of the bit declaration specified usage of three bits - from bit 0 to bit 2
!
! Q: how does 'custom' work?
! A: let's look at
!  #define can_baudrate_e_enum "100kbps", "250kbps", "500kbps", "1Mbps"
!   custom can_baudrate_e 1 bits, U08, @OFFSET@, [0:1], @@can_baudrate_e_enum@@
!   can_baudrate_e canBaudRate
!
! here #define XXX_enum defines enum options in a reusable way
! @@XXX_e_enum@@ is using the enum options defined above
!
! "custom NEW_TYPE_NAME 1 bits, U08, @OFFSET@, [0:1], @@can_baudrate_e_enum@@" defines NEW_TYPE_NAME
! and "can_baudrate_e canBaudRate; set can_baudrate" creates a parameter of that custom type "can_baudrate_e"
!
!
! bit bitName,"true value","false value";Tooltip text
!
!
!
! units,scale,offset,min,max,digits

! This is the version of the data stored in flash configuration
! Any time an incompatible change is made to the configuration format stored in flash,
! update this string to the current date!
#define FLASH_DATA_VERSION 260817

! Remove next line when Java toolset gets adjusted to load those from json config into VariablesRegistry
! Also remove file integration/generated/rusefi_config_generated_enums.txt
include_file integration/generated/rusefi_config_generated_enums.txt

! all the sub-structures are going to be nested within the primary structure, that's
! needed to get a proper TunerStudio file

! Template struct: parameters are comma-separated in angle brackets
! Usage: @@PARAM_NAME@@ in field definitions is substituted with the provided value
! Define: struct name<T1, T2> ... @@T1@@ ... @@T2@@ ... end_struct
! Instantiate: name<val1, val2> field


struct_no_prefix persistent_config_s

struct_no_prefix engine_configuration_s

! see 'blockingFactor' in tunerstudio.template.ini
! please keep it bigger than (TS_TOTAL_OUTPUT_SIZE / 2) so whole livedata can be
! transferred using two chunks, this will give us 500 Hz refresh rate.
#define BLOCKING_FACTOR 1024

#define SENT_INPUT_COUNT 1

! more normal people are tired of us using 'true'/'false', we need to start removing. At least we have to stop adding :)
#define TRUE_FALSE_COUNT_LIMIT 62

#define TRACTION_CONTROL_ETB_DROP_SLIP_SIZE 6
#define TRACTION_CONTROL_ETB_DROP_SPEED_SIZE 6

! air cooled engines go up to 250, see community board firmware which has that
! PnP boards for liquid cooled engines should override with '120'
#define CLT_UPPER_LIMIT 250
#define CLT_UPPER_VALIDATION_LIMIT 250


#define LUA_PWM_COUNT 8
#define LUA_DIGITAL_INPUT_COUNT 8

! https://github.com/rusefi/rusefi/issues/2010 shows the corner case wheel with huge depth requirement
#define GAP_TRACKING_LENGTH 18
#define VVT_TRACKING_LENGTH 4

#define MAIN_HELP_URL "http://www.rusefi.com/"

#define ETB_BIAS_CURVE_LENGTH 8

#define TOOTH_PACKET_COUNT 1000
#define TOOTH_PACKET_SIZE 2
#define TOOTH_DATA_LENGTH @@TOOTH_PACKET_SIZE@@*@@TOOTH_PACKET_COUNT@@

#define MAP_ANGLE_SIZE 8
#define MAP_WINDOW_SIZE 8

#define TORQUE_TABLE_X_SIZE 6
#define TORQUE_TABLE_Y_SIZE 2

#define CLT_CURVE_SIZE 16
#define CLT_LIMITER_CURVE_SIZE 4
#define CRANKING_CLT_IDLE_CURVE_SIZE 8
#define CLT_CRANKING_CURVE_SIZE 8
#define CLT_CRANKING_TAPER_CURVE_SIZE 6
#define CRANKING_CYCLE_CLT_SIZE 4
! Ethanol axis size for the opt-in 2D cranking flex-fuel enrichment table (crankingFuelFlexTable).
! Deliberately small (4 rows) to keep RAM usage low - cranking enrichment does not need fine ethanol resolution.
#define CRANKING_FLEX_SIZE 4
#define IDLE_ADVANCE_CURVE_SIZE 8
#define CRANKING_ADVANCE_CURVE_SIZE 4
#define TRAILING_SPARK_SIZE 4
#define TRAILING_SPARK_RPM_SIZE 4

#define ENGINE_NOISE_CURVE_SIZE 16
#define CLT_TIMING_TEMP_AXIS_SIZE 5
#define CLT_TIMING_LOAD_AXIS_SIZE 5
#define IDLE_VE_SIZE 4
#define IDLE_VE_SIZE_RPM 4
#define AC_PRESSURE_CURVE_SIZE 8
#define RE_auto_update_root_url "https://rusefi.com/build_server"
#define RE_obfuscated "false"

#define TCU_SOLENOID_COUNT 6
// Only Solenoid 1 & 2 are currently exposed in the TS "Shift Solenoids" dialog, matching
// Generic4TransmissionController (the hardcoded default controller). Up to 6 shift solenoids
// are supported at the config-struct level for a future controller targeting more complex
// transmissions (e.g. a Ford 10R80-style unit uses 6 shift solenoids plus several ancillary
// solenoids) -- see tcu_solenoid3..6 and tcuSolenoidTable.

#define RANGE_INPUT_COUNT 6
#define TCU_RANGE_COUNT 11

! Matt says: The problem is the driver chip. Tle9201 can't do 20k. The drivers are too slow. On purpose to reduce EMI
! https://rusefi.com/forum/viewtopic.php?p=47307#p47307
#define ETB_HW_MAX_FREQUENCY 3000
#define ETB_COUNT 2
#define DC_PER_STEPPER 2
#define DEFAULT_SOLENOID_FREQUENCY 300

#define AUX_DIGITAL_VALVE_COUNT 2

#define VBAT_INJECTOR_CURVE_PRESSURE_SIZE 2
#define VBAT_INJECTOR_CURVE_SIZE 8

#define DWELL_CURVE_SIZE 8

#define EFI_CAN_BUS_COUNT 2
#define EFI_CAN_CANFD FALSE

#define DEFAULT_RPM_AXIS_HIGH_VALUE 7000

#define CRANKING_CURVE_SIZE 8


#define DIGIPOT_COUNT 4
#define TRIGGER_SIMULATOR_PIN_COUNT 2
#define TRIGGER_INPUT_PIN_COUNT 2
#define LOGIC_ANALYZER_CHANNEL_COUNT 4
#define SCRIPT_SETTING_COUNT 8
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

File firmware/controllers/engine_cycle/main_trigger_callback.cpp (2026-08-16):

/**
 * @file    main_trigger_callback.cpp
 * @brief   Main logic is here!
 *
 * See http://rusefi.com/docs/html/
 *
 * @date Feb 7, 2013
 * @author Andrey Belomutskiy, (c) 2012-2020
 *
 * This file is part of rusEfi - see http://rusefi.com
 *
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
 * You should have received a copy of the GNU General Public License along with this program.
 * If not, see <http://www.gnu.org/licenses/>.
 */

#include "pch.h"

#if EFI_PRINTF_FUEL_DETAILS
	bool printFuelDebug = false;
#endif // EFI_PRINTF_FUEL_DETAILS

#if EFI_ENGINE_CONTROL && EFI_SHAFT_POSITION_INPUT

#include "main_trigger_callback.h"
#include "trigger_central.h"
#include "spark_logic.h"
#include "advance_map.h"
#include "cyclic_buffer.h"
#include "fuel_math.h"
#include "cdm_ion_sense.h"
#include "local_version_holder.h"
#include "event_queue.h"
#include "injector_model.h"
#include "injection_gpio.h"

#if EFI_LAUNCH_CONTROL
#include "launch_control.h"
#endif // EFI_LAUNCH_CONTROL

#include "backup_ram.h"

void endSimultaneousInjection(InjectionEvent* event) {
	endSimultaneousInjectionOnlyTogglePins();
	event->update();
}

void turnInjectionPinLow(InjectionEvent *event) {
	efitick_t nowNt = getTimeNowNt();

	for (size_t i = 0; i < efi::size(event->outputs); i++) {
		InjectorOutputPin *output = event->outputs[i];
		if (output) {
			output->close(nowNt);
		}
	}
	event->update();
}

static void turnInjectionPinLowStage2(InjectionEvent* event) {
	efitick_t nowNt = getTimeNowNt();

	for (size_t i = 0; i < efi::size(event->outputsStage2); i++) {
		InjectorOutputPin *output = event->outputsStage2[i];
		if (output) {
			output->close(nowNt);
		}
	}
}

void InjectionEvent::onTriggerTooth(efitick_t nowNt, float currentPhase, float nextPhase) {
	auto eventAngle = injectionStartAngle;

	// Determine whether our angle is going to happen before (or near) the next tooth
	if (!isPhaseInRange(eventAngle, currentPhase, nextPhase)) {
		return;
	}

#if ROTATIONAL_IDLE_CONTROLLER
	if (engine->rotationalIdleController.shouldSkipFuelRotationalIdle()) {
		return;
	}
#endif // ROTATIONAL_IDLE_CONTROLLER

	// Select fuel mass from the correct cylinder
	auto injectionMassGrams = getEngineState()->injectionMass[this->cylinderNumber];

	// Perform wall wetting adjustment on fuel mass, not duration, so that
	// it's correct during fuel pressure (injector flow) or battery voltage (deadtime) transients
	// TODO: is it correct to wall wet on both pulses?
	injectionMassGrams = wallFuel.adjust(injectionMassGrams);

	// Disable staging in simultaneous mode
	float stage2Fraction = isSimultaneous ? 0 : getEngineState()->injectionStage2Fraction;

	// Compute fraction of fuel on stage 2, remainder goes on stage 1
	const float injectionMassStage2 = stage2Fraction * injectionMassGrams;
	float injectionMassStage1 = injectionMassGrams - injectionMassStage2;

#if EFI_VEHICLE_SPEED
	{
		// Log this fuel as consumed

		bool isCranking = getEngineRotationState()->isCranking();
		int numberOfInjections = isCranking ? getNumberOfInjections(engineConfiguration->crankingInjectionMode) : getNumberOfInjections(engineConfiguration->injectionMode);

		float actualInjectedMass = numberOfInjections * (injectionMassStage1 + injectionMassStage2);

#ifdef MODULE_ODOMETER
		engine->module<TripOdometer>()->consumeFuel(actualInjectedMass, nowNt);
#endif // MODULE_ODOMETER

	}
#endif // EFI_VEHICLE_SPEED

	const floatms_t injectionDurationStage1 = engine->module<InjectorModelPrimary>()->getInjectionDuration(injectionMassStage1);
	const floatms_t injectionDurationStage2 = injectionMassStage2 > 0 ? engine->module<InjectorModelSecondary>()->getInjectionDuration(injectionMassStage2) : 0;

#if EFI_PRINTF_FUEL_DETAILS
	if (printFuelDebug) {
		printf("fuel injectionDuration=%.2fms adjusted=%.2fms\n",
				getEngineState()->injectionDuration,
		  injectionDurationStage1);
	}
#endif /*EFI_PRINTF_FUEL_DETAILS */

	if (this->cylinderNumber == 0) {
		if (engine->outputChannels.actualLastInjection) {
			engine->outputChannels.actualLastInjectionRatio = injectionDurationStage1 / engine->outputChannels.actualLastInjection;
		} else {
			engine->outputChannels.actualLastInjectionRatio = 0;
		}
		if (engine->outputChannels.actualLastInjectionStage2) {
			engine->outputChannels.actualLastInjectionRatioStage2 = injectionDurationStage2 / engine->outputChannels.actualLastInjectionStage2;
		} else {
			engine->outputChannels.actualLastInjectionRatioStage2 = 0;
		}
		engine->outputChannels.actualLastInjection = injectionDurationStage1;
		engine->outputChannels.actualLastInjectionStage2 = injectionDurationStage2;
	}

	if (std::isnan(injectionDurationStage1) || std::isnan(injectionDurationStage2)) {
		warning(ObdCode::CUSTOM_OBD_NAN_INJECTION, "NaN injection pulse");
		return;
	}
	if (injectionDurationStage1 < 0) {
		warning(ObdCode::CUSTOM_OBD_NEG_INJECTION, "Negative injection pulse %.2f", injectionDurationStage1);
		return;
	}

	// If somebody commanded an impossibly short injection, do nothing.
	// Durations under 50us-ish aren't safe for the scheduler
	// as their order may be swapped, resulting in a stuck open injector
	// see https://github.com/rusefi/rusefi/pull/596 for more details
	if (injectionDurationStage1 < 0.050f)
	{
		// Zero duration means zero commanded fuel mass - an intentional "no injection"
		// (deceleration fuel cut-off, zero-fuel transients), not a misconfiguration.
		// Only a nonzero-but-impossibly-short pulse deserves a warning. See #9874.
		if (injectionDurationStage1 > 0) {
			warning(ObdCode::CUSTOM_OBD_impossibly_short_INJECTION, "Short pulse %.2f", injectionDurationStage1);
		}
		return;
	}

	floatus_t durationUsStage1 = MS2US(injectionDurationStage1);
	floatus_t durationUsStage2 = MS2US(injectionDurationStage2);

	// Only bother with the second stage if it's long enough to be relevant
	bool hasStage2Injection = durationUsStage2 > 50;

#if EFI_PRINTF_FUEL_DETAILS
	if (printFuelDebug) {
		InjectorOutputPin *output = outputs[0];
		printf("handleFuelInjectionEvent fuelout %s injection_duration %dus engineCycleDuration=%.1fms\t\n", output->getName(), (int)durationUsStage1,
				(int)MS2US(getCrankshaftRevolutionTimeMs(Sensor::getOrZero(SensorType::Rpm))) / 1000.0);
	}
#endif /*EFI_PRINTF_FUEL_DETAILS */

	action_s startAction, endActionStage1, endActionStage2;
	// We use different callbacks based on whether we're running sequential mode or not - everything else is the same
	if (isSimultaneous) {
		startAction = action_s::make<startSimultaneousInjection>();
		endActionStage1 = action_s::make<endSimultaneousInjection>(this);
	} else {
		auto const taggedPointer{TaggedPointer<decltype(this)>::make(this, hasStage2Injection)};

		// sequential or batch
		startAction = action_s::make<turnInjectionPinHigh>( taggedPointer.getRaw() );
		endActionStage1 = action_s::make<turnInjectionPinLow>( this );
		endActionStage2 = action_s::make<turnInjectionPinLowStage2>( this );
	}

	// Correctly wrap injection start angle
	float angleFromNow = eventAngle - currentPhase;
	if (angleFromNow < 0) {
		angleFromNow += getEngineState()->engineCycle;
	}

	// Schedule opening (stage 1 + stage 2 open together)
	efitick_t startTime = scheduleByAngle(nullptr, nowNt, angleFromNow, startAction);

	// Schedule closing stage 1
	efitick_t turnOffTimeStage1 = startTime + US2NT((int)durationUsStage1);
	getScheduler()->schedule("inj", nullptr, turnOffTimeStage1, endActionStage1);

	// Schedule closing stage 2 (if applicable)
	if (hasStage2Injection && endActionStage2) {
		efitick_t turnOffTimeStage2 = startTime + US2NT((int)durationUsStage2);
		getScheduler()->schedule("inj stage 2", nullptr, turnOffTimeStage2, endActionStage2);
	}

#if EFI_DETAILED_LOGGING
	printf("scheduling injection angle=%.2f/delay=%d injectionDuration=%d %d\r\n", angleFromNow, (int)NT2US(startTime - nowNt), (int)durationUsStage1, (int)durationUsStage2);
#endif
#if EFI_DETAILED_LOGGING
	efiPrintf("handleFuel pin=%s eventIndex %d duration=%.2fms %u", outputs[0]->getName(),
			cylinderNumber,
			injectionDurationStage1,
			(unsigned)getRevolutionCounter());
	efiPrintf("handleFuel pin=%s delay=%.2f %u", outputs[0]->getName(), NT2USF(startTime - nowNt),
			(unsigned)getRevolutionCounter());
#endif /* EFI_DETAILED_LOGGING */
}

static void handleFuel(efitick_t nowNt, float currentPhase, float nextPhase) {
	ScopePerf perf(PE::HandleFuel);

	efiAssertVoid(ObdCode::CUSTOM_STACK_6627, hasLotsOfRemainingStack(), "lowstck#3");

	LimpState limitedFuelState = getLimpManager()->allowInjection();

	// todo: eliminate state copy logic by giving limpManager it's owm limp_manager.txt and leveraging LiveData
	engine->outputChannels.fuelCutReason = (int8_t)limitedFuelState.reason;
	bool limitedFuel = !limitedFuelState.value;
	if (limitedFuel) {
		return;
	}

	// This is called in the fast callback already, but since we may have just achieved engine sync (and RPM)
	// for the first time, force update the schedule so that we can inject immediately if necessary
	FuelSchedule *fs = getFuelSchedule();
	if (!fs->isReady) {
		fs->addFuelEvents();
	}

#if FUEL_MATH_EXTREME_LOGGING
	if (printFuelDebug) {
		efiPrintf("handleFuel [%.1f, %.1f) %d", currentPhase, nextPhase, getRevolutionCounter());
	}
#endif /* FUEL_MATH_EXTREME_LOGGING */

	fs->onTriggerTooth(nowNt, currentPhase, nextPhase);
}

/**
 * This is the main trigger event handler.
 * Both injection and ignition are controlled from this method.
 */
void mainTriggerCallback(uint32_t trgEventIndex, efitick_t edgeTimestamp, angle_t currentPhase, angle_t nextPhase) {
	ScopePerf perf(PE::MainTriggerCallback);

	if (hasFirmwareError()) {
		/**
		 * In case on a major error we should not process any more events.
		 */
		return;
	}

	float rpm = engine->rpmCalculator.getCachedRpm();
	if (rpm == 0) {
		// this happens while we just start cranking

		// todo: check for 'trigger->is_synchnonized?'
		return;
	}

	if (trgEventIndex == 0) {

		if (getTriggerCentral()->checkIfTriggerConfigChanged()) {
			getIgnitionEvents()->isReady = false; // we need to rebuild complete ignition schedule
			getFuelSchedule()->isReady = false;
			// moved 'triggerIndexByAngle' into trigger initialization (why was it invoked from here if it's only about trigger shape & optimization?)
			// see updateTriggerConfiguration() -> prepareOutputSignals()

			// we need this to apply new 'triggerIndexByAngle' values
			engine->periodicFastCallback();
		}
	}

	engine->forEachModule([=](auto & m) {
		m.onEnginePhase(rpm, edgeTimestamp, currentPhase, nextPhase);
	});

	/**
	 * For fuel we schedule start of injection based on trigger angle, and then inject for
	 * specified duration of time
	 */
	handleFuel(edgeTimestamp, currentPhase, nextPhase);

	engine->module<TriggerScheduler>()->scheduleEventsUntilNextTriggerTooth(
		rpm, edgeTimestamp, currentPhase, nextPhase);

	/**
	 * For spark we schedule both start of coil charge and actual spark based on trigger angle
	 */
	onTriggerEventSparkLogic(rpm, edgeTimestamp, currentPhase, nextPhase);
}

#endif /* EFI_ENGINE_CONTROL */

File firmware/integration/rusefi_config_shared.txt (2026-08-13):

! These definitions are shared between both output channels/live data and config layout

#define PACK_MULT_PRESSURE 30
#define PACK_MULT_HIGH_PRESSURE 10
#define PACK_MULT_PERCENT 100
#define PACK_MULT_FLEX 2
#define PACK_MULT_EGTEMPERATURE 4
#define PACK_MULT_TEMPERATURE 100
#define PACK_ADD_TEMPERATURE 40
#define PACK_MULT_MS 300
#define PACK_MULT_AFR 1000
#define PACK_MULT_LAMBDA 10000
#define PACK_MULT_ANGLE 50
#define PACK_MULT_VOLTAGE 1000
! see TPS_TS_CONVERSION, this is related on how TS handles voltage for TPS calibration
#define PACK_MULT_RAW_VOLTAGE 0.005
#define PACK_MULT_MASS_FLOW 10
#define TPS_2_BYTE_PACKING_MULT 100
#define PACK_MULT_AFR_CFG 10
#define PACK_MULT_LAMBDA_CFG 147
#define PACK_MULT_FUEL_MASS 100
#define PACK_PERCENT_BYTE_MULT 100.0
#define PACK_MULT_FUEL_FLOW 200
#define PACK_MULT_VSS 100

! technically that's PWM_PHASE_MAX_WAVE_PER_PWM * 2
#define HW_EVENT_TYPES 4

! Short and Long term fuel corrections
#define FT_BANK_COUNT 2

#define VE_RPM_COUNT 16
#define VE_LOAD_COUNT 16

#define MAP_UPPER_LIMIT 650

#define IGN_LOAD_COUNT 16
#define IGN_RPM_COUNT 16
#define BLEND_FACTOR_SIZE 8

#define TORQUE_CURVE_SIZE 6
#define TORQUE_CURVE_RPM_SIZE 6

! Default Lua script buffer size; boards override this (larger) in their prepend.txt.
! Consumed by rusefi_types.h's lua_script_t and the page5_s struct. See #7911.
#define LUA_SCRIPT_SIZE 8000

#define TCU_GEAR_COUNT 10
#define EGT_CHANNEL_COUNT 8

#define MAX_CYLINDER_COUNT 12

! V engines or flat engines would have pairs of shafts with same trigger shape and target position
#define BANKS_COUNT 2
#define CAMS_PER_BANK 2

#define CAM_INPUTS_COUNT @@BANKS_COUNT@@*@@CAMS_PER_BANK@@

#define LUA_ANALOG_INPUT_COUNT 8
#define IGN_BLEND_COUNT 4
#define VE_BLEND_COUNT 4
#define BOOST_BLEND_COUNT 2
#define BLEND_PRECISION 0.1
#define TARGET_AFR_BLEND_COUNT 2
#define TARGET_AFR_BLEND_PRECISION 0.01
#define LUA_GAUGE_COUNT 8


#define GAUGE_NAME_VERSION "firmware"
#define GAUGE_NAME_UPTIME "Uptime"
! WARNING! THIS GAUGE NAME IS PART of REO integration API
#define GAUGE_NAME_TRG_ERR "Trigger Error Counter"
#define GAUGE_NAME_TRG_GAP "Sync: Trigger Latest Ratio"

#define GAUGE_NAME_CAN_READ_OK "CAN: Rx"
#define GAUGE_NAME_CAN_WRITE_OK "CAN: Tx OK"
#define GAUGE_NAME_CAN_WRITE_ERR "CAN: Tx err"

! todo: technical debt: which file is correct for gauge CATEGORY names?
#define GAUGE_CATEGORY_TIMING "Timing"
#define GAUGE_CATEGORY_SYNC "Sync"
#define GAUGE_CATEGORY_FUEL_MATH "Fuel: math"
#define GAUGE_CATEGORY_BOOST_CONTROL "Boost Control"
#define GAUGE_CATEGORY_ETB "ETB more"
#define GAUGE_CATEGORY_SENT "Sensors - SENT"

#define GAUGE_NAME_VVT_B1I "VVT: bank 1 intake"
#define GAUGE_NAME_VVT_B1E "VVT: bank 1 exhaust"
#define GAUGE_NAME_VVT_B2I "VVT: bank 2 intake"
#define GAUGE_NAME_VVT_B2E "VVT: bank 2 exhaust"

#define GAUGE_NAME_VVT_TARGET_B1I "VVT: bank 1 intake target"
#define GAUGE_NAME_VVT_TARGET_B1E "VVT: bank 1 exhaust target"
#define GAUGE_NAME_VVT_TARGET_B2I "VVT: bank 2 intake target"
#define GAUGE_NAME_VVT_TARGET_B2E "VVT: bank 2 exhaust target"

#define GAUGE_NAME_DESIRED_GEAR "TCU: Desired Gear"
#define GAUGE_NAME_CURRENT_GEAR "TCU: Current Gear"
#define GAUGE_NAME_ISS "TCU: Input Shaft Speed"
#define GAUGE_NAME_TC_RATIO "TCU: Torque Converter Ratio"

#define GAUGE_NAME_VVS "Vehicle Speed"
#define GAUGE_NAME_GEAR_RATIO "Gearbox Ratio"
#define GAUGE_NAME_DETECTED_GEAR "Detected Gear"
#define GAUGE_NAME_TURBO_SPEED "Turbocharger Speed"
#define GAUGE_NAME_VBAT "VBatt"
#define GAUGE_NAME_VIGN "VIgn"
#define GAUGE_NAME_TIME "Time"
#define GAUGE_NAME_RPM "RPM"
#define GAUGE_NAME_CLT "CLT"
#define GAUGE_NAME_IAT "Intake Air IAT"
#define GAUGE_NAME_AUX_TEMP1 "Aux temp 1"
#define GAUGE_NAME_AUX_TEMP2 "Aux temp 2"
#define GAUGE_NAME_TPS "TPS"
#define GAUGE_NAME_TPS2 "TPS2"
#define GAUGE_NAME_MAP "MAP"
#define GAUGE_NAME_MAF "MAF"
#define GAUGE_NAME_CPU_TEMP "ECU: CPU Temperature"
#define GAUGE_NAME_ETB_TARGET "ETB: position target"
#define GAUGE_NAME_WG_POSITION "Wastegate position sensor"
#define GAUGE_NAME_ETB_ERROR "ETB: position error"
#define GAUGE_NAME_ETB_DUTY "ETB: Duty"
#define GAUGE_NAME_IDLE_POSITION "Idle: Position sensor"
#define GAUGE_NAME_LAST_ERROR "Warning: last"
#define GAUGE_NAME_TUNE_CRC16 "Tune CRC16"
#define GAUGE_NAME_ENGINE_CRC16 "Engine CRC16"
#define GAUGE_NAME_FW_VERSION "ECU: Software Version"

#define GAUGE_NAME_RAW_FUEL_PRESSURE_LOW "Fuel pressure raw (low)"
#define GAUGE_NAME_FUEL_PRESSURE_LOW "Fuel pressure (low)"
#define GAUGE_NAME_FUEL_PRESSURE_LOW_UNITS "kPa"

#define GAUGE_NAME_RAW_FUEL_PRESSURE_HIGH "Fuel pressure raw (high)"
#define GAUGE_NAME_FUEL_PRESSURE_HIGH "Fuel pressure (high)"
#define GAUGE_NAME_FUEL_PRESSURE_HIGH_UNITS "bar"
#define GAUGE_NAME_FUEL_TEMPERATURE "Fuel Temperature"
#define GAUGE_NAME_FLEX "Flex Ethanol %"
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

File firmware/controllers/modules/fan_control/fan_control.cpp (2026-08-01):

#include "pch.h"

#include "fan_control.h"

#include "bench_test.h"
#include "table_helper.h"
#include "rusefi/interpolation.h"

PUBLIC_API_WEAK bool fansDisabledByBoardStatus() {
  return false;
}

PUBLIC_API_WEAK bool fansEnabledByBoardStatus() {
  return false;
}

bool FanController::getState(bool acActive, bool lastState) {
	auto clt = Sensor::get(SensorType::Clt);
	auto vss = Sensor::get(SensorType::VehicleSpeed);

#if EFI_SHAFT_POSITION_INPUT
	cranking = engine->rpmCalculator.isCranking();
	notRunning = !engine->rpmCalculator.isRunning();
#else
	cranking = false;
	notRunning = true;
#endif

	auto acMode = getAcMode();

	if (disableAtSpeed() > 0 && vss.Valid) {
		if (vss.Value > disableAtSpeed()) {
			disabledBySpeed = true;
		} else if (vss.Value < (disableAtSpeed() - disableAtSpeedHysteresis())) {
			disabledBySpeed = false;
		}
		// else: in hysteresis band — maintain previous disabledBySpeed
	} else {
		disabledBySpeed = false;
	}
	disabledWhileEngineStopped = notRunning && disableWhenStopped();
	brokenClt = !clt;
	enabledForAc = (acMode == fan_ac_mode_e::Relay) && acActive;
	hot = clt.value_or(0) > getFanOnTemp();
	cold = clt.value_or(0) < getFanOffTemp();

	if (fansEnabledByBoardStatus()) {
		radiatorFanStatus = (int)RadiatorFanState::BoardForcedOn;
		return true;
	} else if (cranking) {
		// Inhibit while cranking
		radiatorFanStatus = (int)RadiatorFanState::Cranking;
		return false;
	} else if (disabledWhileEngineStopped) {
		// Inhibit while not running (if so configured)
		radiatorFanStatus = (int)RadiatorFanState::EngineStopped;
		return false;
	} else if (disabledBySpeed) {
		// Inhibit while driving fast
		radiatorFanStatus = (int)RadiatorFanState::VehicleIsTooFast;
		return false;
  } else if (fansDisabledByBoardStatus()) {
    radiatorFanStatus = (int)RadiatorFanState::BoardStatus;
		return false;
	} else if (brokenClt) {
		// If CLT is broken, turn the fan on
		radiatorFanStatus = (int)RadiatorFanState::CltBroken;
		return true;
#if EFI_AC_PRESSURE_FAN
	} else if (acMode == fan_ac_mode_e::Pressure && enabledForAcByPressure(lastState)) {
		return true;
	} else if (acMode == fan_ac_mode_e::Relay && enabledForAc) {
#else
	} else if (enabledForAc) {
#endif
	  radiatorFanStatus = (int)RadiatorFanState::AC;
		return true;
	} else if (hot) {
		radiatorFanStatus = (int)RadiatorFanState::Hot;
		return true;
	} else if (cold) {
		radiatorFanStatus = (int)RadiatorFanState::Cold;
		return false;
	} else {
	  radiatorFanStatus = (int)RadiatorFanState::Previous;
		// no condition met, maintain previous state
		return lastState;
	}
}

#if EFI_AC_PRESSURE_FAN
bool FanController::enabledForAcByPressure(bool lastState) {
	// Pressure is the command here: high-side pressure drives the fan regardless of
	// whether the compressor is currently engaged (eg static heat soak with clutch open).
	auto acPressure = Sensor::get(SensorType::AcPressure);
	if (!acPressure.Valid) {
		enabledForAcPressure = false;
		return false;
	}

	float pressure = acPressure.Value;
	if (pressure >= getAcPressureFanOnThreshold()) {
		enabledForAcPressure = true;
	} else if (pressure < getAcPressureFanOffThreshold()) {
		enabledForAcPressure = false;
	} else {
		// hysteresis band: maintain previous fan state
		enabledForAcPressure = lastState;
	}

	if (enabledForAcPressure) {
		radiatorFanStatus = (int)RadiatorFanState::AcPressure;
	}
	return enabledForAcPressure;
}
#endif

void FanController::initPwm() {
	if (m_pwmInitialized) {
		return;
	}
#ifndef EFI_UNIT_TEST
	if (!isBrainPinValid(getConfigPin())) {
		return;
	}
	startSimplePwm(&m_pwm, "Fan PWM", &engine->scheduler, &getPin(), getPwmFrequency(), 0);
	m_pwmInitialized = true;
#endif
}

void FanController::onSlowCallbackPwm(bool acActive) {
	initPwm();

	auto clt = Sensor::get(SensorType::Clt);

	if (!clt) {
		// Sensor invalid – run fan at max PWM
		float safeDuty = getMaxPwm();
		pwmCurvePwm = safeDuty;
		pwmTargetPwm = safeDuty;
		m_currentPwm = safeDuty;
		pwmAppliedPwm = safeDuty;
		m_state = (safeDuty > 0);
#ifndef EFI_UNIT_TEST
		if (m_pwmInitialized) {
			m_pwm.setSimplePwmDutyCycle(safeDuty / 100.0f);
		}
#endif
		return;
	}

	pwmCurvePwm = computeCurvePwm(clt.Value);

	float target = pwmCurvePwm;
	if (acActive) {
		target += getPwmAcAdder();
		// TODO EFI_AC_PRESSURE_FAN: add an adder curve vs A/C pressure (fanN_ac_pressure_pwm_bins /
		// fanN_ac_pressure_pwm_values) so PWM fans can ramp up proportionally to condenser load.
	}
	target = clampF(getMinPwm(), target, getMaxPwm());
	pwmTargetPwm = target;

	// Soft-start: limit upward slew rate so ramp from 0-100 takes softStartSec seconds
	float softSec = getSoftStartSec();
	if (softSec > 0 && target > m_currentPwm) {
		float maxStep = 100.0f / (softSec * 20.0f);
		target = minF(target, m_currentPwm + maxStep);
	}

	m_currentPwm = target;
	pwmAppliedPwm = m_currentPwm;
	m_state = (m_currentPwm > 0);

#ifndef EFI_UNIT_TEST
	if (m_pwmInitialized) {
		m_pwm.setSimplePwmDutyCycle(m_currentPwm / 100.0f);
	}
#endif
}

void FanController::onSlowCallback() {
#if EFI_PROD_CODE
	if (isRunningBenchTest()) {
	  radiatorFanStatus = (int)RadiatorFanState::Bench;
		return; // let's not mess with bench testing
	}
#endif

	bool acActive = engine->module<AcController>()->isAcEnabled();

	pwmActive = isPwmEnabled();
	if (isPwmEnabled()) {
		onSlowCallbackPwm(acActive);
		return;
	}

	auto& pin = getPin();

	bool result = getState(acActive, pin.getLogicValue());

	m_state = result;

	pin.setValue(result);
}

void FanController::setDefaultConfiguration() {
	engineConfiguration->disableFan1AtSpeedHysteresis = 5;
	engineConfiguration->disableFan2AtSpeedHysteresis = 5;

	engineConfiguration->fanOnTemperature = 92;
	engineConfiguration->fanOffTemperature = 88;
	engineConfiguration->fan2OnTemperature = 95;
	engineConfiguration->fan2OffTemperature = 91;

	engineConfiguration->fan1PwmFrequency = 250;
	engineConfiguration->fan2PwmFrequency = 250;

	setLinearCurve(engineConfiguration->fan1TempBins, 80, 110);
	setLinearCurve(engineConfiguration->fan1PwmValues, 0, 100);
	setLinearCurve(engineConfiguration->fan2TempBins, 85, 115);
	setLinearCurve(engineConfiguration->fan2PwmValues, 0, 100);

	engineConfiguration->fan1MinPwm = 20;
	engineConfiguration->fan1MaxPwm = 100;
	engineConfiguration->fan2MinPwm = 20;
	engineConfiguration->fan2MaxPwm = 100;

	engineConfiguration->fan1AcAdder = 10;
	engineConfiguration->fan2AcAdder = 10;

	engineConfiguration->fan1SoftStartSec = 2.0f;
	engineConfiguration->fan2SoftStartSec = 2.0f;

#if EFI_AC_PRESSURE_FAN
	// Defaults suited for R134a/R1234yf high-side: fan 1 on at ~200 psi, fan 2 on at ~260 psi.
	getCustomPage()->fan1AcPressureOn  = 1400;
	getCustomPage()->fan1AcPressureOff = 1100;
	getCustomPage()->fan2AcPressureOn  = 1800;
	getCustomPage()->fan2AcPressureOff = 1400;
#endif
}

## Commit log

2025-04-12 Begin actual development for diet
    added paralela package, made sure it builds and fixed build errors
    [board_config.txt]
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2026-06-06 add off-idle RPM adder with stabilization state machine
    Replaces the removed dashpot with a cleaner RPM-domain mechanism:
    when the engine returns from off-idle (Running/Coasting phase), a
    configurable RPM adder is applied to the closed-loop idle target so
    the PID chases an elevated RPM until the engine has fully settled.
    State machine: Armed → Stabilizing (monitors dRPM/s) → Waiting
    (hold timer) → Decaying (linear decay to zero) → Inactive.
    Re-triggers at any state snap back to the full adder immediately.
    Four new config fields repurpose existing unused slots (binary-
    layout-compatible with the removed dashpot/ramp fields):
    offIdleEnabled, offIdleRpmAdder, offIdleWaitTime,
    offI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
    [rusefi_config.txt]
2026-06-06 add TunerStudio UI for off-idle RPM adder; simplify enable logic
    - Drop the separate offIdleEnabled bit; the feature is now enabled
    whenever offIdleRpmAdder > 0 (simpler, one less config field)
    - Replace freed bit slot with unusedBit_offIdleEnabled to preserve
    binary config layout
    - Add off-idle adder fields to the "Extra Idle Features" dialog in
    tunerstudio.template.ini; stability threshold, wait time, and
    decay time are conditionally visible when adder > 0
    - Update unit tests accordingly
    [rusefi_config.txt]
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2026-06-06 Add Clutch Down cranking condition option; fix SwitchedState::operator bool()
    - Adds CC_CLUTCH_DOWN = 3 to cranking_condition_e so start/stop can
    require the clutch-down switch instead of clutch-up
    - Renames the existing "Clutch" label to "Clutch Up" (value 2 unchanged,
    so existing tunes are unaffected)
    - Expands the config bits field from [0:1] to [0:2] to fit four values
    - Fixes SwitchedState::operator bool() which returned state != nullptr
    (always true) instead of dereferencing the pointer; this also corrects
    the previously broken CC_BRAKE and CC_CLUTCH checks in start_stop.cpp
    [rusefi_config.txt]
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2026-06-06 state manager intro
    Cherry-picked from 986a7ad982 (state-manager branch).
    Resolved conflicts: exhaustCutout bits kept at their positions, useEngineStateMachine
    placed after them; FLASH_DATA_VERSION bumped to 260602.
    [rusefi_config.txt]
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2026-06-06 Remap slow ADC to ADCD3 and fast MAP to ADCD1 to resolve DMA knock/MAP conflicts on s550
    [board_configuration.cpp]
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2026-06-07 Implement traction control hold and decay logic and fix discrete time step boundary transitions
    [rusefi_config.txt, unittest_Multispark_DefaultConfiguration.csv, unittest_Multispark_EnabledNoMaxRpm.csv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]
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2026-06-12 Add WOT time enrichment AlphaX feature
    New page-5 module (EFI_WOT_ENRICHMENT, FALSE f4 / TRUE f7,h7) that richens
    the target AFR after prolonged time at Wide Open Throttle. While the Engine
    State Machine reports WOT and the feature is enabled, a 20Hz timer counts
    elapsed seconds (capped at 30s) and an 8-cell curve maps that time to an AFR
    adder that is added to the target AFR (negative = richer). The timer and adder
    reset immediately on leaving WOT. Modeled on the Burst Knock module.
    [config_page_5.txt]
2026-06-12 Add DTC-severity trigger for Limp mode; misfire latches limp
    Make the malfunction_central error-code API available in firmware (it was
    previously #if EFI_UNIT_TEST only) so misfire detection can store its OBD
    DTCs, and use accumulated fault severity to latch the Engine State Machine's
    Limp mode.
    - malfunction_central: un-gate addError/removeError; add programmer-defined
    obdCodeSeverity() (misfire P0300-P0312 = 5 pts, others 0) and
    getErrorSeverityTotal() summing severity over the active DTC set.
    - EngineStateMachine::onSlowCallback: latch limp via reportLimpCondition()
    when total severity reaches the user-configurable limpSeverityThreshold.
    - Page 5: new limpSeverityThreshold (default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
    [config_page_5.txt]
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2026-06-12 Revamp misfire to N-of-last-M engine-wide window; add burst knock/WOT/LPR board flags
    Replaces per-cylinder consecutive-arm misfire counting with a shared engine-wide
    N-of-last-M ring-buffer window, freezing the baseline on flagged firings to prevent
    drift. Adds EFI_BURST_KNOCK, EFI_WOT_ENRICHMENT, EFI_LAUNCH_POWER_RAMP flags to
    paralela and hellen154hyundai board.mk; updates board_config_gui curated list and
    ALL_KNOWN_FLAGS accordingly. build_gui.py persists last-used output directory via
    ~/.rusefi_build_gui.json. bundle.mk uses cp -r for folder targets.
    [config_page_5.txt]
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2026-06-13 alphax-s550: fix LPS25HBTR baro I2C pins to PB6/PB7; protorico-econoline board flag additions
    s550 PCB has the onboard LPS25HBTR wired to SCL=PB6, SDA=PB7, not the
    standard Hellen MM176 PB10/PB11 that setHellenMMbaro() was setting.
    Set the correct pins directly so initBaro() can find and register the
    sensor at startup.
    [board_configuration.cpp]
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2026-06-15 Misfire: replace fixed ratio threshold with adaptive K*wobble threshold
    Replaces misfireThresholdRatio with a self-calibrating threshold:
    threshold = baseline + K * wobble
    where "wobble" is a second EMA tracking the mean absolute deviation of
    clean-firing segment durations from the shared baseline. This lets the
    detector auto-scale to the engine's own noise floor -- a smooth flat-plane
    V8 gets a tight threshold without touching K; a lumpy cam gets a looser
    one automatically, avoiding false positives.
    New config knobs: misfireK (replaces ratio), misfireWobbleAlphaRise,
    misfireWobbleAlphaFall (asymmetric, same reasoning as baseline alphas --
    track roughness fast, relax slowly). New live gau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
    [config_page_5.txt]
2026-06-15 Misfire: rewrite alpha tooltips to graph perspective
    All four EMA alpha descriptions now say "above/below baseline on the
    graph" and "climbs/falls" instead of mixing engine-RPM direction with
    graph-µs direction. Removes the misleading "upward baseline drift"
    wording from misfireEmaAlphaAccel.
    [config_page_5.txt]
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2026-06-15 Misfire: add settle period before detection goes live
    misfireSettleCycles (default 200) counts firing events after entering
    idle. Flagging and the misfireDetectionActive gauge are suppressed until
    the counter reaches the threshold. Baseline and wobble EMAs update
    normally during the settle so they are warm when detection starts.
    Setting 0 disables the delay entirely (used in tests).
    [config_page_5.txt]
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2026-06-16 AC pressure fan; ESM temp overlay + quick warmup; alternator single-value fix; misfire quick-warmup guard; build_gui srec path fix
    - EFI_AC_PRESSURE_FAN: per-fan high-side pressure on/off thresholds with hysteresis
    replace the simple "enable with A/C" toggle when AcPressure sensor is present;
    page-5 config fields + defaults suited for R134a/R1234yf; FALSE on f4, TRUE on f7/h7
    - ESM temp overlay: updateTempOverlay() publishes engineSmIsCold/Operating/Hot bits
    from CLT bands (smColdTempThreshold / smHotTempThreshold on page 5); falls back to
    Operating when no valid CLT sensor
    - ESM quick warmup overlay: engineSmIsQuickWarmup = Cold AND Idle; gates ETB offset,
    timing retard, and lambd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
    [config_page_5.txt]
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2026-06-16 ignition: add dwell duty cycle mode for Ford TFI modules
    Adds a page-5 switch that replaces the RPM/voltage dwell tables with a
    fixed percentage of the inter-spark interval. Ford TFI (Thick Film Ignition)
    modules used on Windsor engines expect a 50% duty cycle square wave rather
    than an absolute dwell time.
    When enabled, dwell = (dutyPercent/100) * engineCycleDuration / numSparks,
    which is the exact inverse of the existing getCoilDutyCycle() function.
    Cranking still uses ignitionDwellForCrankingMs regardless of this setting.
    FLASH_DATA_VERSION bumped for page-5 layout change.
    [config_page_5.txt, rusefi_config.txt]
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2026-06-17 launch control: add clutch-up activation mode; alphax-gold: persist page 5/4 to flash
    Splits clutch-down/up into separate launch state bits and a new
    CLUTCH_UP_INPUT_LAUNCH mode so launch can trigger on clutch release as
    well as clutch press. Also enables 2mb_flash layout and disables SD as
    a config backend on alphax-gold so page 5 (and page 4 second tables)
    survive reboot instead of resetting to defaults.
    Adds the new fw-custom-paralela-master board (core board files only).
    [config_page_5.txt, rusefi_config.txt]
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2026-06-18 Shift torque speed gate, eco mode MAP gate, CDV smart mode, launch clutch-up fix
    - Shift Torque Reduction now shares launchSpeedThreshold with Launch
    Control: STR requires speed >= threshold, Launch requires < threshold,
    so the two can't both fire off the same shared clutch/switch pin.
    - Eco Mode: replace the Force-On switch mode with a MAP-based gate
    (ecoModeMapLimit); only Off/Inhibit switch modes remain.
    - CDV controller: add Smart mode, gating activation/deactivation on a
    clutch pressure window (new ClutchPressure sensor channel) in addition
    to the existing time/VSS/clutch exit conditions.
    - Launch control: fix clutch-up switch state inversion (pin reads true
    when released, s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
    [config_page_5.txt, rusefi_config.txt, rusefi_config_shared.txt]
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2026-06-19 ETB rev limiter PID and configurable soft RPM limit range
    Replace the linear ETB rev-limit taper with an opt-in PID
    (cutEtbOnRpmLimit) that actively holds RPM ~50rpm below the hard
    limit. Targets the LimpManager effective rev limit via getRevLimit(),
    seeds the integrator from etbRevLimitSeedTps on engage, and exposes
    Kp/Ki/Kd config. Add Pid::setIntegration() for seeding.
    Decouple the soft RPM limit timing-retard/fuel-added ramp from the
    hard-limit hysteresis via a new rpmSoftLimitRange window.
    [rusefi_config.txt]
2026-06-20 Latch start-button press during pending Lua/CAN cranking authorization; fix AlphaX S550 TPS mux swap; add TCU support to protorico-econoline
    [board_configuration.cpp]
2026-06-20 Fix clutch-up shift detection edge and add second-switch support
    ClutchUp mode was opening the shift window on pedal release (rising
    edge) instead of pedal leaving rest (falling edge), so
    engineSmIsUpshifting/engineSmIsDownshifting fired after the clutch had
    already re-engaged instead of during the drivetrain-locked window that
    UpshiftRpmHold/DownshiftBlipper expect. Open/close edges are now keyed
    correctly per switch type.
    Add smSecondClutchSwitchAvailable (page 5) for vehicles wired with both
    a Clutch-Up and Clutch-Down switch: shift detection can open on
    whichever switch reaches its press-start edge first, and close early
    on the complementary switch's release edge, instead of only trusti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
    [config_page_5.txt, rusefi_config.txt]
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2026-06-20 Add Check Engine Triggering: points-gated CEL with TPS Stuck High/Low
    New AlphaX page-5 feature (EFI_CHECK_ENGINE_TRIGGERING) that lets the
    tuner configure named threshold checks from TunerStudio, each with its
    own enable bit and a tunable points weight, that sum into a points-gated
    CEL independent of the existing always-on addError() MIL path.
    TPS Stuck High/Low is implemented: compares actual TPS against driver
    pedal intent (requires ETB) so it never false-trips at idle or WOT, and
    debounces both tripping and untripping with the same timer/timeout.
    Untripping is optional (tpsStuckCelAutoClear) -- disabled latches the
    code until power cycle, matching the existing Misfire Detection latch.
    R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
    [config_page_5.txt, rusefi_config.txt]
2026-06-22 Rework Downshift Blipper rev-match phasing; gate it with Lua instead of scaling
    Open loop snaps to etbMaximumPosition until RPM is within a configurable
    window of the matched target, then hands off to the closed-loop PID hold,
    which now holds the target RPM (clutch/driver/timeout only) instead of
    cutting as soon as RPM gets close. The Lua gauge input is now an inhibit
    gate (mirrors Exhaust Cutout / Pops and Bangs) rather than a throttle
    multiplier curve.
    Also folds in pending Misfire Detection / Check Engine Triggering (TPS
    Circuit Low/High/Intermittent) / Pops and Bangs exhaust-cutout-inhibit
    edits that were already in progress on this branch.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
    [config_page_5.txt, rusefi_config.txt]
2026-06-22 Rework Upshift RPM Hold to hold through to a real exit; tooltip/dialog cleanup
    Drops upshiftRpmHoldMaxRpm (the computed target is always below current
    RPM by construction, so it never protected against an overrev) and the
    early-release RPM offset, which cut the hold the instant RPM neared
    target instead of actually holding it. ActivePID now holds until
    clutch-release/driver-override/timeout, mirroring the Downshift Blipper.
    Also de-dupes the shared TPS-to-RPM feed-forward curve out of the Upshift
    RPM Hold dialog (it's already reachable from its own Torque Management
    menu entry), adds missing tooltips for every Upshift RPM Hold field, and
    fixes Downshift Blipper dialog/tooltip references lef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
    [config_page_5.txt]
2026-06-24 Unify fan A/C control into a single mode (Disabled/Relay/Pressure)
    Replace the separate per-output "Enable with AC" checkbox and the page-5
    "A/C Control Mode" relay/pressure dropdown with one fan_ac_mode_e control
    (Disabled/Relay/Pressure) per fan, removing the conflict between the two
    previously-independent controls.
    [config_page_5.txt, rusefi_config.txt]
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2026-06-25 Add rpmUpdateMode: Per-cycle, First Order, Instant
    Replaces the boolean alwaysInstantRpm with a 3-value enum rpmUpdateMode_e
    (Per-cycle / First Order / Instant) under Advanced Trigger in TunerStudio.
    First Order mode extrapolates RPM from the last two cycle-averaged periods:
    extrapolatedRpm = prevCycleRpm + rpmRate * timeSinceTDC
    Updated at every tooth (same rev-limiter responsiveness as Instant) but
    derived from cycle-averaged data, so combustion-induced torsional noise
    (±80 RPM on V8) is eliminated. An EMA (alpha=0.5) is applied to rpmRate
    only in First Order mode to attenuate single-cycle outliers without
    delaying tracking of genuine sustained acceleration.
    Bumps FLASH_DATA_VERSION t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
    [rusefi_config.txt]
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2026-06-29 Add fan disable-at-speed hysteresis to prevent on/off cycling at the threshold speed
    [fan_control_engineConfiguration.txt]
2026-06-29 Misc actuator/controller fixes: sport pedal live bit, upshift flat-shift priority, gear detector clutch-aware, fuel pump no-sensor fast path, etbSplit default
    [fuel_pump.cpp]
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2026-06-29 sensors: add Bosch 3 bar TMAP MAP sensor preset (0261230566 / 0281002976)
    Add MT_BOSCH_3_BAR for the Bosch ~3 bar TMAP sensor
    (0261230566 / 0281002976, VAG 03G906051E/M, 038906051C), calibrated as
    11 kPa at 0.39V and 310 kPa at 4.65V per the sensor spec.
    This differs from the existing "Bosch 2.5" preset (250 kPa top), giving
    correct scaling for this higher-range part.
    [rusefi_config.txt]
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2026-06-29 cranking & priming: single flexCranking toggle drives 2D coolant x ethanol tables
    Consolidate flex-fuel start enrichment behind the single existing flexCranking
    toggle (plus a present flex sensor):
    - Cranking coolant multiplier: flex ON -> 2D crankingFuelFlexTable (coolant x
    ethanol %, 4-row ethanol axis); flex OFF -> the 1D crankingFuelCoef curve.
    - Priming pulse mass: same toggle. flex ON -> new 2D primeFlexTable (coolant x
    ethanol %, 4 rows); flex OFF -> the 1D primeValues curve.
    The 1D E0->E100 blend is removed from the firmware path. crankingFuelCoefE100 is
    kept in the struct for tune compatibility but is no longer used and is hidden
    from TunerStudio (no curve/menu references). Th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
    [rusefi_config.txt]
2026-06-29 cranking flex: retire crankingFuelCoefE100, migrate legacy tunes via TuneMigrator
    Review feedback: instead of keeping crankingFuelCoefE100 as a hidden "retained for
    compatibility" field, retire it the idiomatic way and migrate legacy tunes through
    the Java TuneMigrator framework.
    - rusefi_config.txt: rename crankingFuelCoefE100 -> unusedCrankingFuelCoefE100 (keeps
    the byte slot and offsets stable; DefaultTuneMigrator ignores 'unused' fields).
    - default_cranking.cpp: drop the now-dead default seeding of the field.
    - CrankingFlexTableMigrator (+registration in ComposedTuneMigrator): reconstructs
    crankingFuelFlexTable from a user's old crankingFuelCoef (E0) and crankingFuelCoefE100
    (E100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
    [rusefi_config.txt]
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2026-06-29 fuel: flex fuel transient compensation (accel enrichment + wall wetting)
    Adds optional flex-fuel compensation for transient fueling, driven by
    CLT x Ethanol% tables, since gasoline and ethanol behave very differently
    during transient throttle (especially cold).
    Three 8x8 CLT (X) x Ethanol% (Y) multiplier tables with shared axes:
    - flexAeMult -> acceleration enrichment
    - flexWwTauMult -> wall wetting tau
    - flexWwBetaMult -> wall wetting beta
    A single helper getFlexTransientMult() (flex_transient.h) gates on the new
    flexFuelTransientComp enable bit plus the presence of a flex sensor, returns
    1.0 (neutral) otherwise, and treats an un-initialized (all-zero) table as
    neutral. A faile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
    [rusefi_config.txt]
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2026-07-01 Add Ghost Cam Mode and Sport Pedal engine-state-machine tracking
    Ghost Cam Mode is a switch/Lua-gauge activated idle lope effect,
    active only in the Idle SM state: it overrides VVT cam targets, AFR,
    idle ignition timing PID, and IAC position while engaged, and cleanly
    resets the idle timing PID/CLID integrator on exit. Also exposes
    isSportPedalActive() so the state machine can track Sport Pedal
    activation as its own SM bit, matching Ghost Cam's pattern.
    [config_page_6.txt, rusefi_config.txt]
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2026-07-02 Add configurable averaging window for Engine SM RPM rate (RPM/t)
    RPM rate of change (used for Accelerating/Decelerating state detection
    and the RPM-rate shift accumulator) previously recomputed every 50 ms
    slow-callback tick from a raw single-tick delta, which is noisy at low
    resolution. It now accumulates over a configurable window
    (smRpmRateWindowMs, floored to one tick) and measures against the
    actual elapsed time, so smAccelRateThreshold/smDecelRateThreshold stay
    in RPM/s and don't need re-tuning when the window changes. Also expose
    the computed rate as a new live-data field/gauge (engineSmRpmRate).
    Also skip the accel/decel detection entirely while the IdleController
    considers the engi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
    [config_page_6.txt]
2026-07-02 Rewrite CHT-to-CLT estimator as a competing-rate radiator model
    Replace the old steady-state-delta model (ΔT = k0 + k1*CHT + k2*load,
    integrated with separate heat/cool time factors) with a physically-
    motivated competing-rate ODE:
    dCLT/dt = R_heat(CHT) * (CHT - CLT)
    - R_reject(laggedAirflow) * iatFactor(IAT) * valvePos * (CLT - thermostatTemp)
    CHT continuously pulls the estimate up toward itself; radiator airflow
    (cooling fans + VSS-based ram-air, coolant-lag filtered) pulls it down
    toward the thermostat temperature, gated by a lagged thermostat valve
    whose target position is a cubic function of CLT vs. the thermostat
    setpoint. The valve's own lag is what produces the crossin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
    [config_page_6.txt, rusefi_config.txt]
2026-07-03 Convert CLT estimator CHT/rejection curves to tunable base+gain
    The CHT heatload-factor and radiator heat-rejection-vs-airflow curves
    were both close to linear across their configured range, so replace
    the 8-point curves with a base rate + gain (2 tunable numbers instead
    of 16), anchored at a 90 deg C reference CHT and 0 CFM airflow
    respectively. Defaults approximate the old curves within a few percent.
    [config_page_6.txt, rusefi_config.txt]
2026-07-03 Convert CLT estimator IAT/AAT curve to reference temp + gain
    The rejection-rate multiplier vs IAT/AAT curve defaulted flat at 1.0
    (a no-op), so its "base" was always going to be exactly 1.0 by
    definition. Replace the 8-point curve with a user-chosen reference air
    temp (where effectiveness is defined as 100%) plus a gain describing
    how effectiveness scales from there -- an exact match to the previous
    default (zero gain), not just an approximation.
    [config_page_6.txt, rusefi_config.txt]
2026-07-03 Convert CLT estimator VSS ram-air curve to a saturating exponential
    The airflow-vs-VSS curve is genuinely non-linear (concave/decelerating,
    diminishing ram-air returns from backpressure/turbulence at speed), so
    a straight-line base+gain wouldn't fit it. Replace the 8-point curve
    with a saturating exponential (max airflow approached at high speed +
    the speed at which half of that max is reached), approximating the old
    curve within ~10%.
    This was the last curve using CLT_EST_CURVE_SIZE, so remove the now-dead
    constant and the test helper that built flat curves from it.
    [config_page_6.txt, rusefi_config.txt]
2026-07-06 Add Accelerating-hold latch to Engine State Machine (smAccelHoldMs)
    Once the Accelerating rate threshold is met, hold the Accelerating state for
    smAccelHoldMs after the rate drops back below threshold, resetting on any
    fresh crossing during the hold. A lift into Coasting/Overrun still breaks
    the hold immediately so DFCO/Overrun is never masked. Reuses the two
    smAccelDecelPad bytes on page 6.
    [config_page_6.txt]
2026-07-06 Make First Order RPM rate smoothing tunable (rpmRateSmoothingPct)
    Replace the hardcoded EMA alpha=0.5 used to smooth the RPM rate-of-change
    extrapolation slope in RPM_UPDATE_FIRST_ORDER mode with a TS-tunable
    percentage (0-95%, default 50%), so users can trade off responsiveness vs.
    noise rejection. Bumps FLASH_DATA_VERSION for the new field.
    [rusefi_config.txt]
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2026-07-07 Add Sport Mode overlay to Engine State Machine
    Introduces a shared "driver wants aggressive behavior" flag
    (engineSmIsSportMode) as a Sport Mode overlay on the Engine State
    Machine, activated by a hardware switch or Lua gauge threshold. Limp
    mode out-votes Sport Mode (protective); Sport Mode out-votes Eco Mode
    (mutually exclusive). This replaces the GhostCam SM state with an
    Idle-only overlay bit and consolidates the config schema so downstream
    features can consume the flag instead of duplicating their own
    Lua-gauge activation logic.
    [config_page_6.txt]
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2026-07-10 Engine State Machine: add time-based shift accumulator snap (smAccumulatorSnapTimeMs)
    A same-gear direction reversal (e.g. a long Overrun run immediately followed
    by acceleration) previously needed an equally long run the other way to null
    out a large stale opposite-sign shift accumulator, risking a stale
    shift-direction call (spurious downshift blip on clutch-in right after
    tipping back into the throttle). smAccumulatorSnapTimeMs forces the
    accumulator to 0 once continuously dwelling in the opposing state long
    enough, instead of waiting for it to decay/climb across zero on its own.
    0 disables it (legacy decay/cross-only behavior).
    [config_page_6.txt]
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

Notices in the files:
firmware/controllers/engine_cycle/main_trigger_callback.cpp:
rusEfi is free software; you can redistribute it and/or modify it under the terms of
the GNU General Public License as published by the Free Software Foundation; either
